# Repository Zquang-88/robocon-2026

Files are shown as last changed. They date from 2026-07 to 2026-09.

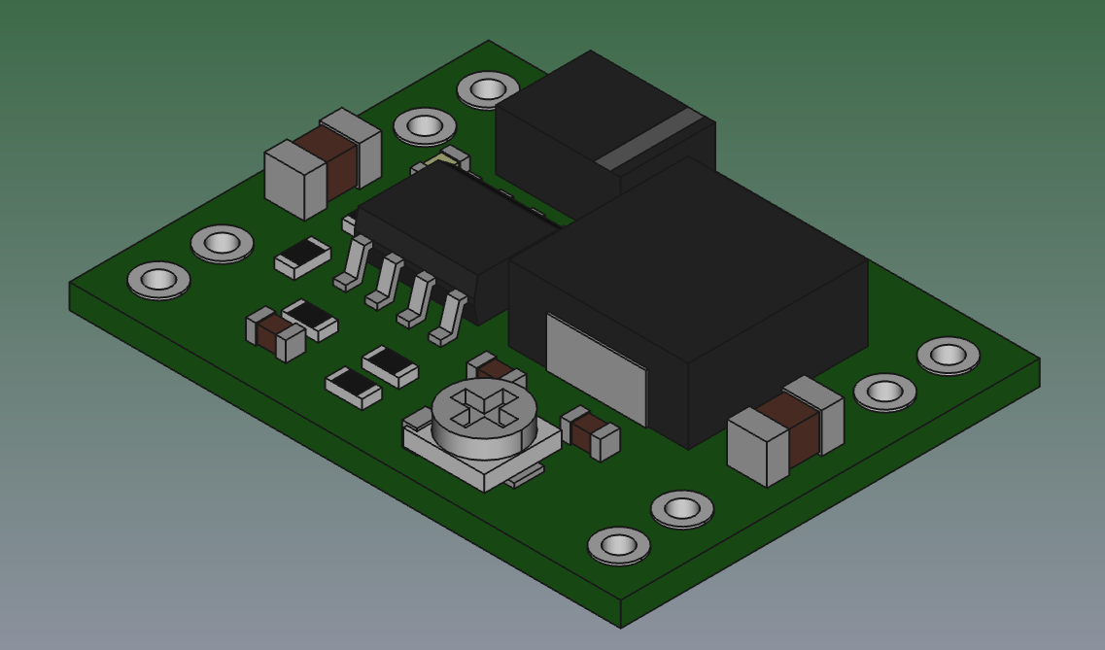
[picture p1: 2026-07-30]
hardwave/MP1584/d-sun-dc-dc-step-down-voltage-regulator-simple-version-1.snapshot.4/render/D-SUN_dcdc_step_down_SIMPLE2.png

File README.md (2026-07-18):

# ROBOCON 2026

Kho mã nguồn và thiết kế phần cứng dùng chung của đội Robocon 2026.

> Trạng thái: đang phát triển. Nhánh `main` chỉ dành cho phiên bản đã được kiểm tra.

## Phạm vi dự án

- Firmware điều khiển robot và các module ngoại vi
- Schematic, PCB và thư viện linh kiện
- Tài liệu kỹ thuật, sơ đồ kết nối và quy trình kiểm thử

## Cấu trúc hiện tại

```text
robocon-2026/
├── firmwave/                  # Firmware hiện có
│   ├── Auto_v1.cpp
│   └── line.h
├── hardwave/                  # Dự án Altium, PCB và schematic
│   ├── ROBOCON_AUTO/
│   ├── ROBOCON_T9_LOGIC/
│   └── ROBOCON_T9_V1/
├── docs/                      # Tài liệu làm việc nhóm
├── CONTRIBUTING.md            # Quy tắc đóng góp
└── README.md
```

Tên `firmwave` và `hardwave` được giữ nguyên để không làm hỏng đường dẫn dự án hiện tại. Có thể đổi thành `firmware` và `hardware` trong một Pull Request riêng sau khi cả đội thống nhất.

## Bắt đầu

1. Cài GitHub Desktop và đăng nhập GitHub.
2. Clone repository về máy.
3. Chọn **Fetch origin** và **Pull origin** trước khi bắt đầu.
4. Tạo branch mới từ `main`.
5. Chỉ sửa phần được phân công và kiểm tra trước khi commit.
6. Push branch và tạo Pull Request để thành viên khác duyệt.

Xem hướng dẫn chi tiết tại [CONTRIBUTING.md](CONTRIBUTING.md).

## Quy ước branch

| Loại công việc | Ví dụ |
|---|---|
| Tính năng firmware | `feature/motor-control` |
| Thiết kế phần cứng | `hardware/logic-board-v2` |
| Sửa lỗi | `fix/encoder-reading` |
| Tài liệu | `docs/wiring-diagram` |

## Quy ước commit

Viết ngắn gọn, mô tả đúng thay đổi:

```text
feat: thêm điều khiển động cơ
fix: sửa cách đọc encoder
hardware: cập nhật schematic bo logic
docs: bổ sung sơ đồ kết nối
```

## Nguyên tắc an toàn

- Không commit mật khẩu Wi-Fi, token, khóa SSH hoặc thông tin bí mật.
- Không đưa code chưa kiểm tra trực tiếp lên `main`.
- Không sửa đồng thời cùng một file PCB/SchDoc trên nhiều branch.
- Ghi rõ điện áp, cực tính và phiên bản bo mạch trước khi thử trên robot.
- Luôn có phương án dừng khẩn cấp khi kiểm thử cơ cấu chấp hành.

## Công cụ

- Firmware: C/C++ (bổ sung board, framework và phiên bản khi chốt cấu hình)
- PCB/Schematic: Altium Designer
- Quản lý mã nguồn: Git, GitHub Desktop và GitHub Pull Request

## Thành viên và phân công

Cập nhật bảng này khi đội chốt vai trò:

| Thành viên | Phụ trách | Module |
|---|---|---|
| Chưa cập nhật | Trưởng nhóm | Điều phối và tích hợp |
| Chưa cập nhật | Firmware | Điều khiển robot |
| Chưa cập nhật | Hardware | PCB và hệ thống điện |
| Chưa cập nhật | Mechanical | Cơ khí |

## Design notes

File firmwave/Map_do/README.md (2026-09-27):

# ESP32-S3 mechanism controller

Firmware điều khiển hai động cơ bước, hai cảm biến E18 và bốn van điện từ hai đầu qua PCF8574. ESP32 nhận lệnh từ Teensy 4.1 bằng UART2; USB Serial 115200 dùng chung bộ parser để thử và chẩn đoán.

## Kiến trúc

```text
Teensy Serial6 (TX24, RX25)
  <-> 57600 baud
ESP32-S3 UART2 (RX16, TX15)
  |- UartProtocol: buffer char cố định, lọc CR/LF/khoảng trắng/byte rác đầu dòng
  |- MechanismController: state machine động cơ, HOME, E18 và chuỗi van
  |- ValveController: PCF8574 active-low, interlock cặp và deadtime 50 ms
  |- AccelStepper.run(): phát xung động cơ không chặn
  `- PersistentConfig: cấu hình profile trong NVS có CRC
```

Chuỗi van dùng `millis()`, không dùng `delay(700)`. Trong thời gian chờ, vòng lặp vẫn đọc UART, chạy động cơ bước, cập nhật E18 và nhận `STOP`.

## Chân phần cứng

| Chức năng | ESP32-S3 | Nối với |
| --- | ---: | --- |
| UART2 RX | GPIO16 | Teensy TX6 chân 24 |
| UART2 TX | GPIO15 | Teensy RX6 chân 25 |
| I2C SDA | GPIO8 | PCF8574 SDA |
| I2C SCL | GPIO3 | PCF8574 SCL |
| PCF8574 | `0x20` | P0-P7, active LOW |
| Step/Dir A | GPIO1 / GPIO2 | Driver stepper A |
| Step/Dir B | GPIO45 / GPIO48 | Driver stepper B |
| HOME A/B | GPIO36 / GPIO37 | Công tắc active LOW |
| E18 A/B | GPIO17 / GPIO18 | Cảm biến active LOW |
| Nút van | GPIO11 | Nút thường hở nối GND, INPUT_PULLUP |
| Nút HOME B rồi A | GPIO12 | Nút thường hở nối GND, INPUT_PULLUP |

Firmware chỉ chấp nhận PCF8574 đúng địa chỉ `0x20`. Khi khởi động, `pcfState = 0xFF`, tức P0-P7 đều HIGH và mọi cuộn van đều mất điện. Nếu không tìm thấy PCF8574, cơ cấu không bắt đầu HOME/AUTO và UART báo `ERROR_PCF8574`.

## Hai nút điều khiển tại ESP32

Các nút vẫn hoạt động khi USB/telemetry không kết nối. Một đầu nút nối GPIO,
đầu còn lại nối GND: bình thường HIGH, nhấn LOW. Chống dội 30 ms; nút bị giữ
khi bật nguồn hoặc lúc STOP phải được nhả ra rồi nhấn lại mới có lệnh mới.

- **GPIO11 nhấn một lần:** đóng cả bốn van bằng cách bật P4/P5/P6/P7 và tắt
  P0/P1/P2/P3 (`enabledMask = 0xF0`, trạng thái PCF sau chuyển mạch là `0x0F`).
  Firmware vẫn mở cửa sổ 400 ms để nhận lần nhấn thứ hai. Nếu cơ cấu đang chạy,
  dừng cả chu trình và motor để bước kế tiếp không ghi đè trạng thái đóng.
  UART/USB báo `ACK,BUTTON11,P4_P7_ON_CLOSED`.
- **GPIO11 nhấn nhanh hai lần trong 400 ms:** mở cả bốn van bằng cách bật
  P0/P1/P2/P3 và tắt P4/P5/P6/P7
  trong cùng một mask (`pcfState = 0xF0`), sau deadtime 50 ms. Khi cơ cấu bận
  hoặc có fault, từ chối bật van. UART/USB báo
  `ACK,BUTTON11,P0_P3_ON_REQUESTED` khi nhận yêu cầu chuyển van.
- **GPIO12 nhấn một lần:** khi cơ cấu rảnh và không có fault, giữ A đứng yên,
  cho B chạy về HOME37. B chạm công tắc thì dừng xung ngay, xác nhận ổn định
  25 ms rồi đặt B=0; sau đó mới kéo A về HOME36 và đặt A=0. Cả hai trục dùng
  8000 step/s, gia tốc 5500 step/s²; timeout toàn chu trình 45 giây. Trục đã
  chạm HOME không chạy thêm. Báo `ACK,BUTTON12,HOME_B_THEN_A,8000,5500` khi
  bắt đầu và `HOME,STATUS,...` khi kết thúc. Nhấn khi bận bị từ chối, không xếp
  hàng để tự chạy sau. Lệnh UART `STOP` vẫn được xử lý trong khi HOME.

Chỉnh chân nút, thời gian nhấn đôi và tốc độ HOME ở `include/HardwareConfig.h`:
`VALVE_BUTTON_PIN`, `HOME_BUTTON_PIN`, `BUTTON_DOUBLE_CLICK_MS`,
`BUTTON_HOME_SPEED_STEPS_S`, `BUTTON_HOME_ACCEL_STEPS_S2`, `BUTTON_HOME_TIMEOUT_MS`.
HOME khi bật nguồn và lệnh UART HOME vẫn dùng cấu hình HOME thông thường;
chuỗi B trước A tốc độ 8000/5500 áp dụng riêng cho GPIO12.

## Ghép bốn van hai đầu

| Van | Đầu thứ nhất | Đầu đối diện |
| --- | --- | --- |
| 1 | P0 | P7 |
| 2 | P1 | P6 |
| 3 | P2 | P5 |
| 4 | P3 | P4 |

Mức LOW bật cuộn; mức HIGH tắt cuộn. Trước mỗi lần đổi đầu kích, `ValveController` đưa cả hai đầu của cặp lên HIGH, chờ 50 ms, rồi mới kéo đầu mới xuống LOW. Mọi byte ghi ra PCF đều được kiểm tra để không có hai đầu cùng một cặp đồng thời ở LOW.

Các hàm chính trong `ValveController`:

- `writePCF()`: ghi toàn bộ `pcfState` và kiểm tra giao tiếp.
- `setOutput(pin, enabled)` và `switchValveOutput(pin, enabled)`: chọn một đầu của đúng cặp; `false` chọn đầu đối diện.
- `allValveCoilsOff()`: hủy chuyển mạch đang chờ và ghi `0xFF` ngay.
- `update()`: hoàn tất pha make sau deadtime 50 ms mà không chặn vòng lặp.

## Chuỗi AUTO của van

Tại cả hai MAP, `POINT_A` hạ sâu hơn `POINT_B`: A/B hạ `610/545 mm` tại
`POINT_A` và `520/480 mm` tại `POINT_B`, tính từ `READY_HOME_A`. MAP đỏ và MAP
xanh có bộ hằng số riêng trong `include/HardwareConfig.h`: tiền tố
`RED_POINT_*` và `BLUE_POINT_*`, nên có thể hiệu chỉnh độc lập về sau.

| Lệnh | Bước 1 | Chờ | Bước 2 | Chờ | Phản hồi |
| --- | --- | ---: | --- | ---: | --- |
| `POINT_A` | P2 và P3 ON đồng thời trong một byte PCF | 50 ms deadtime an toàn | Nâng A/B về HOME_A ngay | - | `DONE_POINT_A` |
| `POINT_B` | P0 và P1 ON đồng thời trong một byte PCF | 50 ms deadtime an toàn | A/B cùng về READY_HOME_A; A nâng 1700 mm, B nâng 850 mm rồi giữ | - | `DONE_POINT_B` khi pha nâng tầng 1 bắt đầu |
| `BRIDGE_STABLE` | Không đổi van | - | A giữ ở 1700 mm, chỉ B nâng nốt 850 mm | - | `DONE_BRIDGE_B` |
| `THA_2A` | P1 OFF, P6 ON | 700 ms | P3 OFF, P4 ON | 700 ms | `DONE_THA_2A` |
| `THA_2B` MAP đỏ | P2 OFF, P5 ON | 350 ms | P0 OFF, P7 ON | 700 ms | `DONE_THA_2B` |
| `THA_2B` MAP xanh | P0 OFF, P7 ON | 350 ms | P2 OFF, P5 ON | 700 ms | `DONE_THA_2B` |

Tại `POINT_A` và `POINT_B`, hai cuộn yêu cầu được chuyển bằng một mask PCF8574 nên cùng kích sau deadtime an toàn 50 ms; không còn khoảng chờ 700 ms giữa hai van. Tại `POINT_B`, A và B trước tiên cùng nâng từ vị trí đang hạ về đúng `READY_HOME_A`. Sau khi cả hai tới READY, A/B cùng tốc độ nâng 850 mm; B dừng giữ, còn A nâng tiếp 850 mm để đạt tổng 1700 mm. ESP32 gửi `DONE_POINT_B` ngay khi pha 850 mm đầu bắt đầu để Teensy chạy qua line lên cầu song song. Khi BNO085 trên Teensy xác nhận robot đã xuống hết dốc và mặt phẳng ổn định 500 ms, Teensy gửi `BRIDGE_STABLE`; ESP32 giữ A ở 1700 mm, nâng riêng B nốt 850 mm và trả `DONE_BRIDGE_B`. Teensy vẫn được căn line sau cầu trong lúc B nâng, nhưng bắt buộc chờ `DONE_BRIDGE_B` trước khi gửi `THA_2A`. Các pha nâng dùng giới hạn 9000 step/s và gia tốc 6000 step/s². `MechanismController::updateValveSequence()` vẫn xử lý không chặn cho `THA_2A` và `THA_2B`. Lệnh chuyển động khác trong lúc cơ cấu bận nhận phản hồi `BUSY`. `STOP` luôn hủy chuỗi, dừng stepper, ghi `0xFF` và phản hồi `STOPPED`.
Sau chuỗi van `THA_2B`, ESP32 trả `DONE_THA_2B` ngay để Teensy bắt đầu chạy robot. ESP32 cho riêng động cơ B hạ trước 400 mm, sau đó A và B cùng chạy với tốc độ 8000 step/s và gia tốc 5000 step/s² cho tới khi HOME37 ổn định 25 ms. Lúc đó B được đặt zero và riêng A đổi chiều kéo về HOME36. Nếu HOME37 tác động sớm trong 400 mm đầu, firmware dừng B ngay và bỏ qua pha hạ đồng bộ để bảo vệ cơ cấu. Toàn bộ quá trình không chặn UART/E18/STOP và có timeout 45 giây.

Phía Teensy, sau `DONE_THA_2B`, robot giữ heading và thực hiện một vector chéo duy nhất: lùi 3000 mm (`-X`) đồng thời đi phải 2000 mm (`-Y`), giới hạn tốc độ tổng 1200 mm/s, rồi chuyển sang `FINISH`.

Log kiểm tra ví dụ:

```text
[POINT_A] P2 + P3 ON TOGETHER
DONE_POINT_A
```

## Lệnh chẩn đoán PCF8574

| Lệnh | Chức năng |
| --- | --- |
| `PCF,P0,ON` ... `PCF,P7,ON` | Chọn đầu được chỉ định, tự tắt đầu đối diện |
| `PCF,P0,OFF` ... `PCF,P7,OFF` | Tắt đầu chỉ định và chọn đầu đối diện |
| `PCF,ALL,OFF` | Tắt điện toàn bộ P0-P7 (`0xFF`) |
| `PCF,STATUS` | Đọc status hiện tại |
| `STOP` | Dừng ưu tiên cao, safe-off toàn bộ van |

Chân ngoài P0-P7 bị từ chối. Nếu ghi I2C thất bại, chuỗi bị hủy, cơ cấu vào fault và UART phát `ERROR_PCF8574`.

## Build và kiểm thử

```powershell
C:\Users\Acer\.platformio\penv\Scripts\platformio.exe run -e esp32-s3-devkitm-1
.\test\run_jog_host.ps1
```

Bộ test host kiểm tra địa chỉ/chân I2C, trạng thái khởi động `0xFF`, active-low, bốn cặp interlock, deadtime 50 ms, thứ tự cả bốn chuỗi, `BUSY`, `STOP` và lỗi ghi PCF8574.

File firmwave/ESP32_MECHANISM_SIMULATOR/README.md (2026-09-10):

# ESP32 mechanism simulator

Firmware này giả lập cơ cấu chưa hoàn thiện để Teensy 4.1 có thể tiếp tục chạy
state machine tự động. ESP32 nhận một lệnh cơ cấu hợp lệ, chờ không chặn 4 giây,
sau đó gửi đúng một dòng `DONE` về robot.

## Giao thức khớp với firmware chính

| Teensy gửi | ESP32 trả sau 4 giây |
|---|---|
| `POINT_A` | `DONE` |
| `POINT_B` | `DONE` |
| `THA_2B` | `DONE` |
| `THA_2A` | `DONE` |
| `DONE_THA_2A` | `DONE_THA2A` |
| `DONE_THA_2B` | `DONE_THA2B` |

- UART giữa hai board: `57600`, `8N1`.
- Mỗi bản tin kết thúc bằng CR/LF; `println()` ở hai phía đáp ứng yêu cầu này.
- Chuỗi `DONE` phải viết hoa vì Teensy so sánh chính xác, phân biệt hoa/thường.
- Lệnh không thuộc bảng trên sẽ bị bỏ qua và chỉ được báo trên USB Serial của
  ESP32. Lệnh lặp trong lúc đang chờ cũng bị bỏ qua để không khởi động lại bộ đếm.

## Đấu dây

| ESP32 DevKit V1 | Teensy 4.1 |
|---|---|
| GPIO16 / RX2 | pin 24 / TX6 |
| GPIO15 / TX2 | pin 25 / RX6 |
| GND | GND |

Hai board đều dùng logic 3.3 V. Phải nối chung GND và nối chéo TX-RX. Không nối
chân 5 V vào đường RX/TX.

## Nạp bằng PlatformIO

Mở thư mục này bằng PlatformIO rồi chạy:

```powershell
platformio run
platformio run --target upload
platformio device monitor
```

USB monitor chạy ở 115200 baud và hiển thị lệnh đã nhận, thời điểm bắt đầu mô
phỏng và lúc gửi `DONE`. Kênh USB debug độc lập với UART2 nối sang Teensy.

Firmware chính đã đặt `ESP32_REPLY_TIMEOUT_MS` thành 15 giây để đủ thời gian chờ
4 giây và có thêm biên an toàn cho scheduler/UART.

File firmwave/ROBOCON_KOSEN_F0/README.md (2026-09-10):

# ROBOCON_KOSEN_F0 — Teensy 4.1 Mecanum

Firmware thi đấu Mecanum được nâng cấp trực tiếp từ trình tự nhiệm vụ của
`V10_SAN_DO_V2.cpp`. Chương trình dùng PID bánh xe 100 Hz, BNO085, hai MCP3008,
optical flow MAVLink, VL53L1X, UART ESP32 và parser Serial không chặn.

## Trạng thái an toàn ban đầu

Firmware biên dịch được nhưng **không cho motor chạy ngay sau khi nạp**.
Trong `include/RobotConfig.h`, `HARDWARE_CONFIG_VERIFIED` đang là `false`, kích
thước robot, số count encoder và phía sân chưa được đặt. Đây là khóa có chủ ý để
robot không chạy sai chiều do thông số chưa đo.

Chỉ đặt `HARDWARE_CONFIG_VERIFIED = true` sau khi hoàn thành toàn bộ mục hiệu
chỉnh bên dưới. Khi STOP pin 31 đang LOW hoặc còn fault, lệnh chạy bị từ chối.

## File chính

- `include/RobotConfig.h`: mọi chân, dấu chiều, kích thước, calibration và PID.
- `src/main.cpp`: firmware thi đấu hoàn chỉnh.
- `src/Read_Optical_Flow.cpp`: firmware chẩn đoán optical flow riêng.
- `platformio.ini`: môi trường `robot` và `optical_flow`; mặc định là `robot`.

## Bảng chân kết nối

| Chức năng | Chân Teensy 4.1 |
|---|---:|
| FL RPWM / LPWM | 36 / 37 |
| FR RPWM / LPWM | 22 / 23 |
| RL RPWM / LPWM | 18 / 19 |
| RR RPWM / LPWM | 14 / 15 |
| Encoder FL A / B | 0 / 1 |
| Encoder FR A / B | 6 / 7 |
| Encoder RL A / B | 2 / 3 |
| Encoder RR A / B | 4 / 5 |
| MCP3008 center CS | 26 |
| MCP3008 stop CS | 8 |
| SPI MOSI / MISO / SCK | 11 / 12 / 13 |
| BNO085 + VL53L1X Wire1 SDA / SCL | 17 / 16 |
| Optical flow UART | Tạm tắt; Serial1 chân 0/1 trùng encoder FL |
| Telemetry Serial5 RX / TX | RX21 / TX20; CP210x phía PC là COM5, 57600 baud |
| ESP32 UART | Tạm tắt; chưa chốt UART và chân riêng không xung đột |
| START / STOP vật lý | Không dùng; chân 32 / 31 để trống |

Hai MCP3008 dùng chung SPI0 MOSI/MISO/SCK và khác CS. MCP center đọc CH0–CH7;
do hai cáp cụm stop được đấu chéo, MCP stop đọc CH3–CH5 cho bên trái và CH0–CH2
cho bên phải. Firmware đổi chúng về thứ tự logic trái trước, phải sau. Tất cả thiết
bị phải chung GND;
Teensy dùng mức logic 3.3 V. Optical flow và VL53L1X đang tắt. Lệnh điều khiển
và telemetry RBT/1 đi qua Serial5 tới COM5; USB native COM14 không phải kênh điều
khiển trong bản này. Chân 31/32 hiện không dùng.

## Thư viện PlatformIO/Arduino

`platformio.ini` đã khai báo:

- Paul Stoffregen `Encoder`
- Adafruit `Adafruit BNO08x`
- Pololu `VL53L1X`
- `SPI` và `Wire` có sẵn trong Teensy framework

## Thông số bắt buộc phải đo

Sửa tập trung trong `include/RobotConfig.h`:

1. `ROBOT_LENGTH_MM`: khoảng cách tâm bánh trước–sau.
2. `ROBOT_WIDTH_MM`: khoảng cách tâm bánh trái–phải.
3. `ENCODER_COUNTS_PER_WHEEL_REV`: số count AB thực tế trên một vòng bánh sau hộp số.
4. `MOTOR_SIGN_*` và `ENCODER_SIGN_*` cho bốn bánh.
5. Chọn sân trên giao diện trước khi START AUTO: sân đỏ bắt đầu đi trái,
   sân xanh bắt đầu đi phải. Firmware tự đảo hướng và chọn cụm 3 mắt tương ứng.
6. Xác nhận bố trí con lăn chữ X và `BNO_YAW_SIGN`.
7. UART/baud, đổi trục, dấu trục và scale của optical flow.
8. `CENTER_SENSOR_MIN/MAX`, `STOP_SENSOR_MIN/MAX`, cực tính line/nền và thứ tự sáu mắt dừng.
9. `TOF_TARGET_MM` và giới hạn hợp lệ VL53L1X.
10. Feedforward, dead-zone và PID riêng của từng bánh sau khi test cơ khí.

`MM_PER_COUNT` được tính từ đường kính 100 mm, count/vòng và
`DISTANCE_CALIBRATION`; không còn dùng hằng số cũ `0.73`.

## Build

```text
pio run -e robot
pio run -e optical_flow
```

Chọn environment `robot` để nạp firmware thi đấu. Chỉ nạp `optical_flow` khi
muốn chạy chương trình chẩn đoán MAVLink độc lập.

## Lệnh telemetry COM5, Serial5, 57600 baud

```text
START                 hoặc RUN / AUTO
STOP                  hoặc ESTOP
RESET
CAL_LINE
TEST_MOTOR
TEST_ENCODER
TEST_BNO
TEST_LINE_CENTER
TEST_LINE_STOP
TEST_FLOW
TEST_TOF
STATUS
DRIVE,vx_mm_s,vy_mm_s,wz_rad_s
MOVE,dx_mm,dy_mm,max_speed_mm_s
POSE_RESET
YAW,degrees
SET_PID,wheel(0-3),kp,ki,kd,kff,deadzone
PID,WHEEL,FL,0.4,0.3,0.002
PID,WHEEL,ALL,0.4,0.3,0.002
PID,HEADING,0,6.0,0.1,0.08
PID,LINE,0,0.16,0.02,0.003
PING
GET_CONFIG
TUNE,WHEEL,FL,120
TUNE,STOP
SAVE_CONFIG
PROFILE_LOAD
FACTORY_RESET
```

`DRIVE` phải được gửi lại trong tối đa 500 ms; mất lệnh sẽ dừng và disarm.
Manual `DRIVE` được phép hoạt động khi BNO085 timeout vì Vx/Vy/Wz được điều khiển
trực tiếp; chỉ riêng `FAULT_IMU_TIMEOUT` được bỏ qua trong chế độ này. Mọi fault
khác vẫn khóa motor. `MOVE`, heading hold và state machine vẫn bắt buộc BNO085.
Khi BNO085 hợp lệ, manual Vx/Vy với Wz bằng 0 dùng PID heading để giữ yaw; mức
bù quay manual được giới hạn bởi `MAX_MANUAL_HEADING_WZ_RAD_S`.
`MOVE` điều khiển vị trí tương đối theo X tiến/lùi và Y phải/trái, dùng odometry,
PID vị trí và BNO085 giữ yaw. Mất heartbeat giao diện quá 600 ms cũng dừng MOVE.
Các alias `RUN`, `ESTOP`, `PID,...` và dòng `TEL,...` tương thích giao diện
ASCII RBT/1 trong thư mục `pid-tuner`. Telemetry đầy đủ có tiền tố `DBG` ở 10 Hz.

Trong lúc AUTO đang ARM, firmware không phát khối telemetry định kỳ. Chọn
`AUTO_TELEM,ON_REQUEST` để chỉ đọc một lần bằng `AUTO_TELEM,SNAPSHOT`, hoặc
`AUTO_TELEM,SILENT` để không trả snapshot. Snapshot theo yêu cầu được chia thành
`AUTO_SNAPSHOT`, `AUTO_WHEELS`, `AUTO_SENSORS` và
`AUTO_TELEM,SNAPSHOT_END`, mỗi vòng lặp chỉ phát một khung ngắn.

Các sự kiện `STATE`, `FAULT`, `SAFETY,FAULT`, `SAFETY,ESTOP`,
`SAFETY,STOP_INPUT` và `SAFETY,AUTO_COMPLETE` luôn được gửi trong cả hai chế độ;
giao diện không thể tắt các bản tin an toàn này.

Giao diện Web Serial gửi heartbeat mỗi 100 ms. Chế độ `TUNE,WHEEL` chỉ cho
phép một bánh chạy; nếu mất heartbeat quá 600 ms, firmware đặt bốn target về 0,
xóa PID và disarm. PID, feedforward, deadzone và các giới hạn mặc định nằm trong
`include/RobotConfig.h`; firmware không đọc hoặc ghi EEPROM. Tune từ giao diện chỉ
thay đổi RAM cho tới khi reset. `SAVE_CONFIG` xác nhận RAM-only và `PROFILE_LOAD`
nạp lại các giá trị đã biên dịch từ `RobotConfig.h`. Hãy mở `pid-tuner`, chọn cổng
CP210x COM5 ở 57600 baud, chọn một
bánh và bắt đầu ở RPM thấp khi robot đang được kê khỏi mặt đất.

Telemetry dùng Serial5 RX21/TX20. ESP32 dùng UART6 riêng: Teensy TX24 → ESP32
RX16 và ESP32 TX15 → Teensy RX25, kèm GND chung.

## Trình tự test bắt buộc

1. Kê bốn bánh khỏi mặt đất, tháo cơ cấu tải và giữ STOP ở trạng thái có thể bấm ngay.
2. Để khóa motion, chạy `TEST_BNO`, `TEST_LINE_CENTER`, `TEST_LINE_STOP`,
   `TEST_FLOW`, `TEST_TOF`; xem `DBG` và sửa chân/cực tính/calibration.
3. Gửi `CAL_LINE`, đưa từng mắt qua cả nền và line, rồi gửi `CAL_LINE` lần nữa.
   Chép bốn mảng min/max được in ra vào `RobotConfig.h`.
4. Đo kích thước, encoder count/vòng, chọn phía sân; đặt
   `HARDWARE_CONFIG_VERIFIED = true`.
5. Kê bánh, chạy `TEST_MOTOR`. Bánh 0/1/2/3 lần lượt là FL/FR/RL/RR, mỗi bánh 2 s.
6. Khi target dương, mỗi bánh phải tạo lực đẩy robot về trước. Nếu sai, đổi
   `MOTOR_SIGN_*`, không đảo dây ngẫu nhiên trong lúc cấp nguồn.
7. Quan sát `ENC`. Khi bánh quay theo chiều dương, count phải tăng; nếu giảm, đổi
   `ENCODER_SIGN_*`. Đo đủ một vòng để xác nhận count/vòng.
8. Dùng `DRIVE,100,0,0`: bốn bánh phải làm robot tiến.
9. Dùng `DRIVE,0,100,0`: robot phải sang phải. Nếu cả hướng bị đối xứng, kiểm tra
   vị trí FL/FR/RL/RR và bố trí con lăn trước khi sửa công thức.
10. Dùng `DRIVE,0,0,0.2`: robot phải quay theo chiều kim đồng hồ. Đồng thời yaw
    BNO phải tăng; nếu không, đổi `BNO_YAW_SIGN`.
11. Đẩy robot bằng tay: chuyển động tiến phải cho flow X dương, sang phải cho
    flow Y dương. Sửa `FLOW_*_FROM_SENSOR_AXIS` và `FLOW_*_SIGN`, rồi đo scale.
12. Tune feedforward/dead-zone trước, sau đó P, I, D từng bánh; cuối cùng mới tune
    heading, line, stop-line và position.
13. Test riêng từng state ở tốc độ thấp, luôn kiểm timeout/fault, rồi mới chạy toàn tuyến.

## Tuyến AUTO commissioning đến cầu

Tuyến hiện tại dừng có chủ ý sau giai đoạn 8 mắt giữa bám line lên cầu. Sau khi
căn ToF và hoàn thành các điểm A/B bằng hai cụm 3 mắt, robot tìm line cầu, yêu
cầu line hợp lệ liên tục, sau đó bám line bằng PID và BNO085. Vạch ngang được
đếm có debounce; đủ `BRIDGE_STOP_CROSS_TARGET` thì firmware vào
`BRIDGE_ENTRY_STOP`, đặt bốn target/PWM về 0 và DISARM. Các nhiệm vụ sau cầu
không được chạy trong bản commissioning này.

## Giới hạn chính đã sửa từ V10

Code V10 dùng động học Omni, `mmPerCount = 0.73`, BNO055, hai line digital và
đọc ESP bằng `String/readStringUntil()`. Heading integral không nhân `dt`; có
`delay()`/`while(1)` chặn, đọc ToF thiếu kiểm soát timeout theo state, và nhiều
lệnh khởi tạo chuyển động nằm trực tiếp trong vòng state. Những điểm này đã được
thay bằng Mecanum X, PID có `dt`/anti-windup, parser không chặn, cảm biến có
validity/timeout, state `onEnter` và fault latch. Thứ tự nhiệm vụ V10 và các lệnh
ESP32 `POINT_A`, `POINT_B`, `THA_2B`, `THA_2A`/phản hồi `DONE` vẫn được giữ.

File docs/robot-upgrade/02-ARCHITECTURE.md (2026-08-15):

# Kiến trúc đích

## Firmware Teensy

```text
ROBOCON_KOSEN_F0/
  src/
    main.cpp                  # setup, scheduler, wiring dependency
    app/ModeManager.*         # IDLE/MANUAL/AUTO/TUNE/SAFE/FAULT
    control/PidController.*
    control/MotorControl.*
    control/HeadingControl.*
    control/LineControl.*
    control/DistanceControl.*
    sensors/EncoderBank.*
    sensors/ImuSensor.*
    sensors/LineSensors.*
    sensors/TofSensors.*
    sensors/OpticalFlow.*
    sensors/BatteryMonitor.*
    actuators/ServoBank.*
    actuators/BldcBank.*
    actuators/PneumaticBank.*
    communication/Protocol.*
    communication/TelemetryService.*
    communication/MechanismLink.*
    config/RobotConfig.*
    config/ConfigStore.*
    safety/FaultManager.*
    safety/SafetyManager.*
    logging/Logger.*
```

`main.cpp` chỉ điều phối scheduler và gọi module. Module không tự dùng `delay()`.

## Scheduler đề xuất

| Task | Tần số | Ưu tiên |
|---|---:|---:|
| E-stop + Safety | mỗi vòng loop | cao nhất |
| Motor speed PID | 200 Hz | cao |
| Heading PID | 100 Hz | cao |
| Line PID | 100 Hz | cao |
| Distance PID | 50 Hz | trung bình |
| Sensor update | theo sensor | trung bình |
| PC heartbeat | 10 Hz | trung bình |
| Telemetry | 25–50 Hz | thấp |
| Buffered logging | 20–100 Hz | thấp |

## GUI

```text
Web Serial worker
  -> RBT/2 stream parser
  -> Robot data store
  -> ring buffers (10–30 s)
  -> tab UI
  -> CSV/profile export
```

State kết nối:

```text
DISCONNECTED -> PORT_OPEN -> HANDSHAKE -> SYNC_CONFIG -> STREAMING
                                             |              |
                                             +----ERROR-----+
```

GUI không gửi PID mặc định khi reconnect. Robot là nguồn cấu hình chính.

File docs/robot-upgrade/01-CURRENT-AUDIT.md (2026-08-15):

# Kiểm kê hệ thống hiện tại

## Firmware đang hoạt động

Dự án hiện hành: `firmwave/ROBOCON_KOSEN_F0` cho Teensy 4.1.

Các module logic đang có trong `src/main.cpp`:

| Nhóm | Hiện trạng |
|---|---|
| Motor | 4 motor FL/FR/RL/RR, encoder riêng, mixer mecanum |
| PID motor | PID riêng từng bánh, 100 Hz; chưa có open-loop mode rõ ràng |
| Heading | BNO055 + PID heading |
| Line | 1 cụm 8 mắt MCP3008 + 1 PID dùng chung |
| ToF | 1 VL53L1X, mới đọc sensor; chưa có PID khoảng cách |
| Battery | ADC điện áp, chưa có dòng điện và fault threshold hoàn chỉnh |
| Safety | E-stop vật lý, khóa motor khi boot, timeout DRIVE 500 ms |
| Auto | State machine kiểm tra 3 bước, chưa phải kịch bản thi đấu chính thức |
| ESP32 | Serial4, gửi chuỗi `POINT_A`, chờ chuỗi chứa `DONE` |
| PC telemetry | Serial5, RBT/1 ASCII, không CRC/sequence/heartbeat/config sync |
| Config | Gain khởi tạo trong code, chưa lưu bền vững |
| Logging | Chưa có logger/ring buffer/SD logging |

## Dashboard hiện tại

`pid-tuner` là dashboard React/Web Serial. Hiện có:

- Kết nối cổng COM bằng Web Serial.
- PID riêng từng bánh, PID heading và một PID line.
- Hiển thị RPM, heading, line error, điện áp.
- Gửi `RUN`, `ESTOP`, `PID`, `YAW` theo RBT/1.

Thiếu: handshake, heartbeat 10 Hz, config sync, packet CRC/sequence, reconnect state machine,
fault model, module tabs đầy đủ, ring buffer graph và CSV logger.

## Rủi ro cần giữ nguyên trong lúc refactor

1. Không thay pin, chiều motor/encoder, CPR hoặc kinematics nếu chưa test trên giá kê.
2. Không xóa RBT/1 cho đến khi RBT/2 đã chạy ổn định trên PC và Teensy.
3. Không chuyển PID ra GUI; tất cả control loop vẫn nằm trên Teensy.
4. Không ghi flash/EEPROM mỗi lần kéo slider.
5. Mọi actuator mới mặc định disabled/disarmed/off.

## Phần cứng chưa đủ thông tin để hoàn thiện

- Địa chỉ/XSHUT của 4 VL53L1X.
- Model và protocol của 4 optical-flow sensor.
- Chân, feedback và giới hạn của 4 servo.
- BLDC dùng PWM, DShot hay protocol khác.
- Mapping 8 van và ma trận interlock.
- Sensor dòng điện và ngưỡng pin thấp.
- Command thật của ESP32 cơ cấu.

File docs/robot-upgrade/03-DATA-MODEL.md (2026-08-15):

# Data model RBT/2

## Trạng thái chung

- `RobotMode`: IDLE, MANUAL, AUTO, TUNE, SAFE, FAULT.
- `ModuleState`: enabled, valid, fault, lastUpdateMs.
- `FaultFlags`: bitmask 32-bit; fault latching do `FaultManager` quản lý.

## PID

Mọi PID dùng chung cấu trúc:

```cpp
struct PIDConfig {
  float kp, ki, kd;
  float integralLimit;
  float outputLimit;
  bool enabled;
};

struct PIDRuntime {
  float target, actual, error;
  float integral, derivative, output;
};
```

`PIDConfig` là dữ liệu lưu bền vững. `PIDRuntime` chỉ là telemetry.

## RobotConfig

Một record versioned gồm:

- 4 motor config.
- Heading PID.
- 3 line PID (left/right/rear).
- 4 distance PID (front/rear/left/right).
- 4 servo config.
- 2 BLDC config.
- 8 valve config + interlock mask.
- Safety thresholds và communication settings.
- `version`, `size`, `crc32`.

Phase 1 mới truyền schema/config hiện có. Field chưa có phần cứng phải mang trạng thái disabled.

## Telemetry

Telemetry snapshot chứa runtime hiện tại. Dữ liệu graph tần số cao có thể tách thành
packet `STREAM_SAMPLE` để không phải gửi toàn bộ snapshot lớn ở 50 Hz.

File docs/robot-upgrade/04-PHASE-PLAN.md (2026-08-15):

# Kế hoạch triển khai theo phase

## Phase 1 — Protocol + Dashboard foundation

- RBT/2 binary framing, CRC16, sequence, timestamp.
- HELLO/HELLO_ACK, heartbeat 10 Hz, connection timeout 500 ms.
- CONFIG_READ handshake; giữ RBT/1 tương thích trong giai đoạn migration.
- Data model và diagnostics counters.
- Test parser với packet chia nhỏ, dính liền, CRC sai và noise.

## Phase 2 — Motor PID Tune

- Tách motor/encoder/PID khỏi main.
- OPEN_LOOP_PWM và CLOSED_LOOP_SPEED_PID loại trừ nhau.
- Điều khiển từng bánh và mixer 4 bánh.
- Ring-buffer graph target/actual/error/PWM.

## Phase 3 — Heading PID

- Heading hold enable/disable/reset/set-current-target.
- Runtime target/actual/error/omega và graph.

## Phase 4 — Line PID

- 3 cụm left/right/rear, mỗi cụm 3 mắt và PID riêng.
- Enable/valid/fault độc lập.

## Phase 5 — ToF PID

- 4 VL53L1X, XSHUT/address management.
- PID không chạy khi invalid/timeout/range error.

## Phase 6 — Optical Flow

- 4 module, quality/flow/velocity/timestamp/valid.

## Phase 7 — Actuators + ESP32 mechanism

- Servo, BLDC protocol abstraction, pneumatic interlock.
- ESP32 command ID + ACK/DONE/ERROR/timeout.

## Phase 8 — Config storage

- EEPROM/Flash record A/B, version, size, CRC32, factory defaults.
- Save/Load/Factory reset; rate-limit writes.

## Phase 9 — Safety + Fault

- Safety priority override, fault latching/clearing, physical E-stop policy.

## Phase 10 — Logging + Diagnostics

- CSV browser logging, fault log, optional SD buffered logger.
- Loop rates, drops, CRC errors, timeouts, CPU load estimate.

## Gate sau mỗi phase

1. Build firmware và dashboard.
2. Unit test protocol/module.
3. Bench test bánh kê khỏi mặt đất.
4. Ghi lại pin/config/threshold đã xác nhận.
5. Chỉ merge sang phase tiếp theo khi gate đạt.

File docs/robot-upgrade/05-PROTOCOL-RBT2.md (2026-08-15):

# RBT/2 protocol

## Framing

Little-endian, không padding:

```cpp
struct PacketHeader {
  uint16_t magic;         // 0x4252 = "RB" trên dây
  uint8_t version;        // 2
  uint8_t type;
  uint16_t payloadLength; // tối đa 1024
  uint32_t sequence;
  uint32_t timestampMs;
  uint16_t crc16;
};
```

CRC16-CCITT-FALSE tính trên header với `crc16 = 0`, sau đó payload.

## Packet types Phase 1

| Type | Hướng | Mục đích |
|---|---|---|
| HELLO | PC -> Teensy | protocol range + client nonce |
| HELLO_ACK | Teensy -> PC | firmware/config version + capabilities |
| HEARTBEAT | hai chiều | 10 Hz, mode/fault/link health |
| CONFIG_READ | PC -> Teensy | yêu cầu config hiện tại |
| CONFIG_DATA | Teensy -> PC | chunk config versioned |
| CONFIG_WRITE | PC -> Teensy | thay đổi RAM, chưa ghi flash |
| CONFIG_SAVE | PC -> Teensy | yêu cầu lưu bền vững |
| TELEMETRY | Teensy -> PC | snapshot/module samples |
| COMMAND | PC -> Teensy | mode/setpoint/actuator command |
| ACK | hai chiều | ACK theo sequence/command ID |
| ERROR | hai chiều | mã lỗi có cấu trúc |

## Reconnect

```text
open port
HELLO
HELLO_ACK
CONFIG_READ
CONFIG_DATA chunk(s)
ACK config complete
start HEARTBEAT + TELEMETRY
```

Không có bước nào tự ghi giá trị mặc định GUI xuống robot.

## Tương thích

RBT/1 ASCII tiếp tục là protocol active của robot trong Phase 1A. RBT/2 được đưa vào
song song và chỉ trở thành mặc định sau bench test. Không trộn byte ASCII và binary
trên cùng link sau khi đã negotiate RBT/2.

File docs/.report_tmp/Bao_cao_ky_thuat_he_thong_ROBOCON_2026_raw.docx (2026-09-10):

# Báo cáo kỹ thuật hệ thống điều khiển robot ROBOCON 2026

Teensy 4.1 ESP32 S3 Giao diện Web Serial

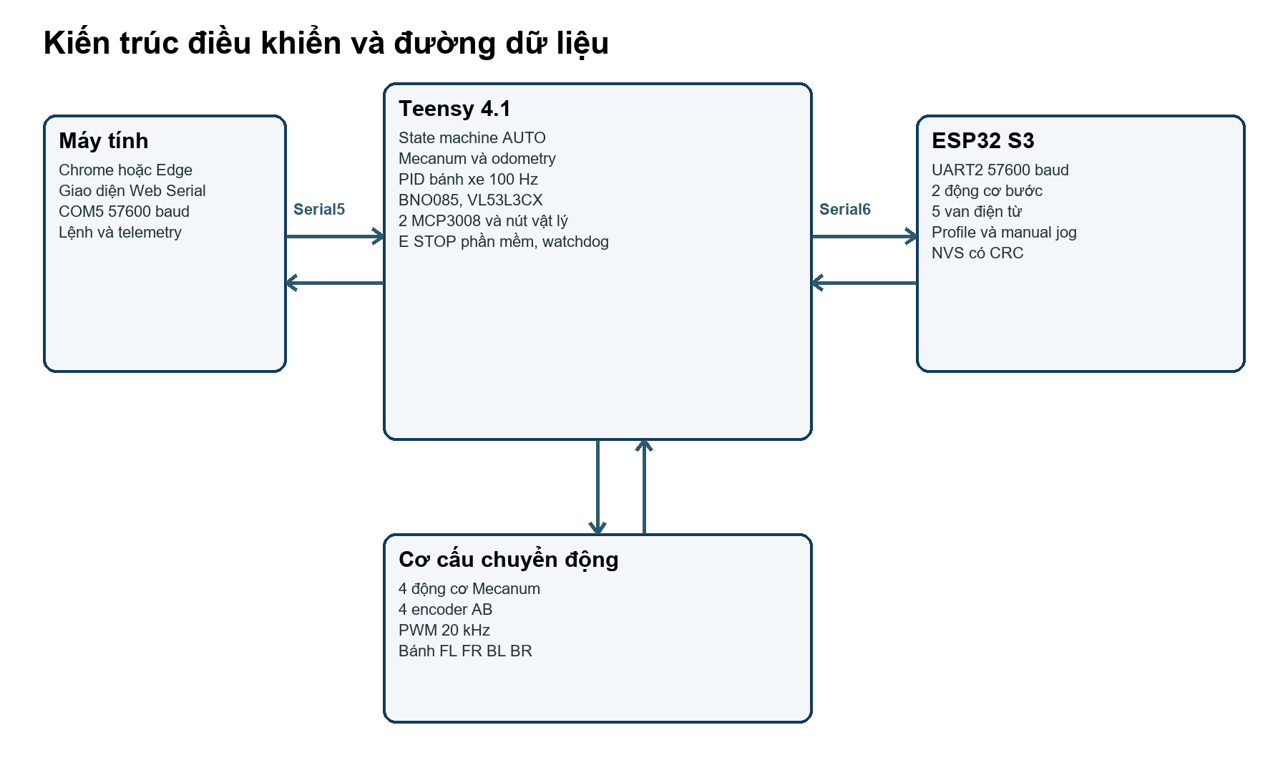
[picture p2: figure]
Sơ đồ máy tính kết nối Teensy qua Serial5, Teensy kết nối ESP32 qua Serial6 và điều khiển bốn bánh Mecanum.

Hình 1 Kiến trúc tổng thể của hệ thống

Thông tin | Giá trị
Mục đích | Giải thích toàn bộ source hiện tại để vận hành, hiệu chỉnh, bảo trì và kiểm soát thay đổi
Phạm vi | Firmware Teensy, firmware ESP32 cơ cấu thật, firmware ESP32 giả lập, giao diện telemetry và các công cụ chẩn đoán
Ngày chụp source | 08 tháng 09 năm 2026
Workspace | D:\ABOUT_ROBOCON_2026\robocon-2026
Commit repository chính | 0b20696
Commit giao diện | 8a5b587
Trạng thái | Tài liệu phản ánh file đang có trên đĩa, bao gồm các thay đổi chưa commit trong repository chính

Kết luận chính Hệ thống đã tách rõ điều khiển chuyển động trên Teensy và điều khiển cơ cấu trên ESP32. Cả hai firmware cùng giao diện đều build thành công tại thời điểm lập báo cáo. Tuy nhiên source chính đang có nhiều thay đổi chưa commit, một số state và hằng số kế thừa không còn nằm trong tuyến AUTO đang chạy, và tài liệu giao diện còn hai nhãn lưu EEPROM không đúng với hành vi RAM only của Teensy. Các điểm này cần được quản lý trước khi chốt bản thi đấu.

# Mục lục

[[TOC]]

# 1 Phạm vi và trạng thái xác minh

Báo cáo này mô tả source đang hoạt động trong workspace, không chỉ mô tả commit Git gần nhất. Cách đọc này cần thiết vì firmware cơ cấu ESP32 và nhiều mô đun mới của Teensy đang ở trạng thái chưa được commit trong repository chính. Các số liệu build bên dưới được kiểm tra trực tiếp từ source hiện tại.

Khối | Kết quả build | Thông tin chính
Teensy 4.1 | Thành công | Platform Teensy 5.1.0; code 156176 byte; data 44540 byte; RAM1 còn 300864 byte; RAM2 còn 511872 byte
ESP32 S3 cơ cấu | Thành công | Espressif32 6.11.0; RAM 20596 trên 327680 byte; flash 328325 trên 3342336 byte
Giao diện | Thành công | vinext build hoàn tất cho route gốc

## 1 1 Các giới hạn của kết quả xác minh

- Build thành công xác nhận cú pháp, liên kết thư viện và kích thước chương trình; build không thay thế thử nghiệm phần cứng dưới tải.
- Không có phép đo mới về chiều motor, cực tính cảm biến, khoảng cách thực tế hoặc đáp ứng PID trong quá trình lập tài liệu.
- Firmware có cơ chế bảo vệ bằng fault, watchdog và giới hạn phần mềm, nhưng E STOP vật lý độc lập chưa xuất hiện trong source Teensy hiện tại; biến dừng hiện tại là chốt E STOP do lệnh serial.
- Map_do là project ESP32 cơ cấu thật hiện tại. ESP32_MECHANISM_SIMULATOR là project thay thế để giả lập DONE sau 4 giây.

# 2 Kiến trúc hệ thống

Máy tính mở giao diện trong Chrome hoặc Edge và trao đổi với Teensy qua Web Serial. Teensy chịu trách nhiệm thời gian thực cho chuyển động, cảm biến, odometry và tuyến AUTO. ESP32 nhận lệnh cơ cấu từ Teensy qua UART riêng, phát xung cho hai động cơ bước, điều khiển năm van và trả trạng thái hoặc DONE.

Liên kết | Đầu thứ nhất | Đầu thứ hai | Tốc độ | Nội dung
Telemetry | Máy tính COM5 | Teensy Serial5 RX21 TX20 | 57600 8N1 | RBT 1 ASCII, lệnh điều khiển, cấu hình, telemetry
Cơ cấu | Teensy Serial6 TX24 RX25 | ESP32 UART2 RX16 TX15 | 57600 8N1 | Lệnh profile, jog, van, config, STATUS, DONE, ERR
Bảo trì Teensy | Máy tính COM14 | USB native Teensy | 115200 | Đường nhận lệnh dự phòng; phản hồi chính vẫn được in qua Serial5 do macro Serial
Bảo trì ESP32 | Máy tính USB | USB Serial ESP32 | 115200 | Dùng cùng parser với UART2 và nhận bản sao phản hồi

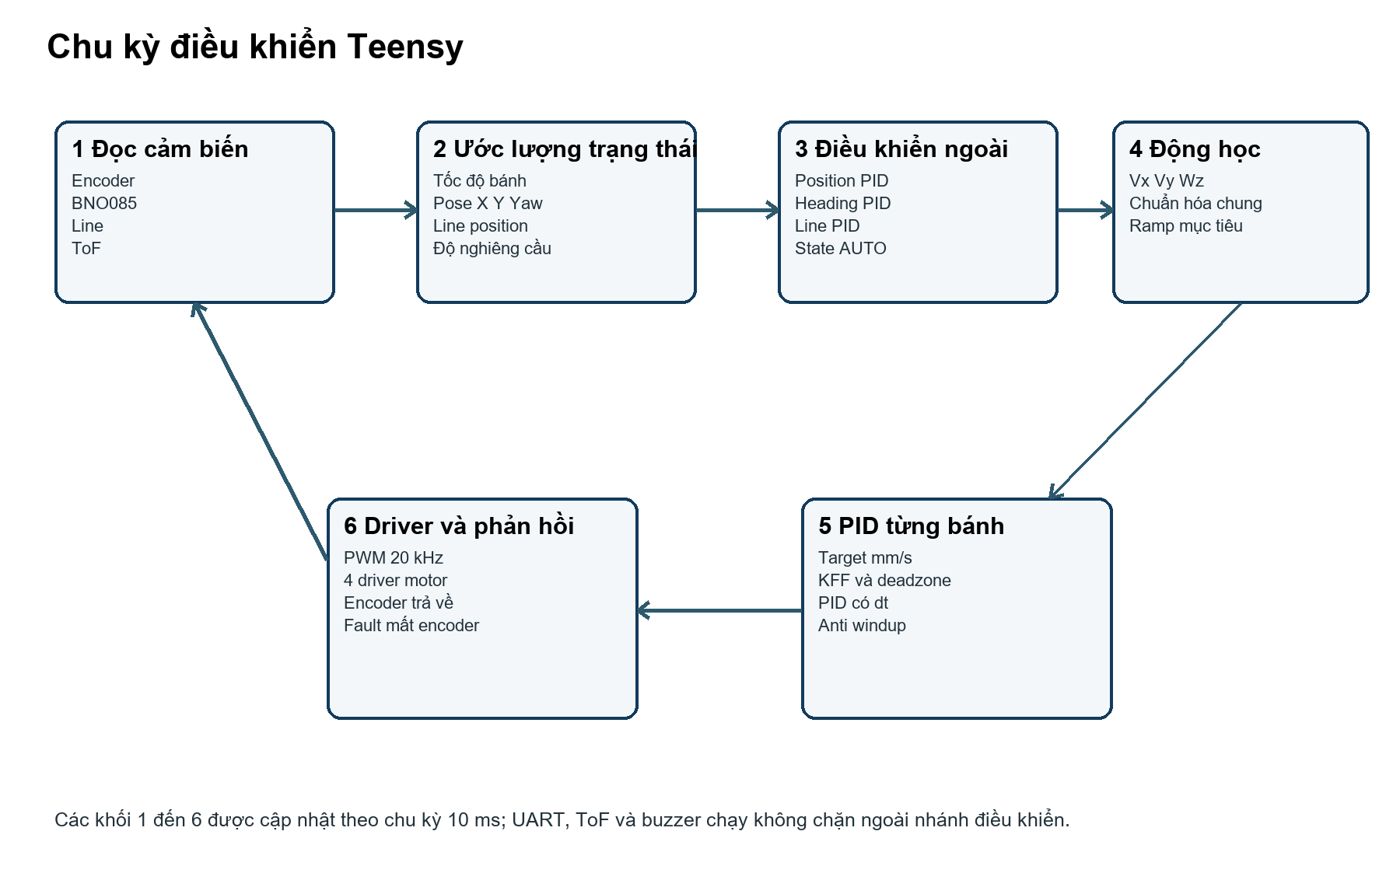
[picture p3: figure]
Chu kỳ đọc cảm biến, odometry, điều khiển ngoài, động học Mecanum, PID bánh và phản hồi encoder.

Hình 2 Các tầng điều khiển trong chu kỳ 10 ms

# 3 Bố cục source code

Đường dẫn logic | Vai trò
firmwave ROBOCON KOSEN F0 include RobotConfig h | Cấu hình tập trung Teensy gồm chân, dấu chiều, PID, line, ToF, AUTO, UART và an toàn
firmwave ROBOCON KOSEN F0 src main cpp | Firmware thi đấu Teensy gồm toàn bộ vòng điều khiển và state machine
firmwave ROBOCON KOSEN F0 src mechanism | Client UART6 và bộ giải mã trạng thái cơ cấu ESP32
firmwave ROBOCON KOSEN F0 src communication | Khung nhị phân RBT 2 có CRC; hiện không được nối vào main RBT 1 ASCII
firmwave ROBOCON KOSEN F0 src READ và TUNE | Các firmware độc lập để đọc line, ToF, optical flow, encoder và tune bốn bánh
firmwave Map_do | Firmware ESP32 S3 cơ cấu thật gồm controller, profile, van, UART và NVS
firmwave ESP32_MECHANISM_SIMULATOR | Firmware giả lập nhận lệnh và trả DONE sau 4 giây
pid-tuner app page tsx | Giao diện chính, Web Serial, parser, log chuyển động, xuất Excel và các trang chức năng
pid-tuner app MechanismJog tsx | Hai cần nhấn giữ cho động cơ bước A và B
pid-tuner app mechanism-jog-controller ts | Bộ phát latest state only 120 ms và hủy lệnh cũ để giảm lag
pid-tuner worker và vite config | Lớp deploy Cloudflare và tích hợp Sites

# 4 Phần cứng và sơ đồ chân

## 4 1 Chân Teensy 4 1

Khối | Chân | Ghi chú
Motor FL | RPWM 36 LPWM 37 | PWM 20 kHz
Motor FR | RPWM 22 LPWM 23 | MOTOR SIGN bằng âm
Motor BL RL | RPWM 18 LPWM 19 | Kênh sau đã được đổi nhận dạng vật lý
Motor BR RR | RPWM 14 LPWM 15 | Kênh sau đã được đổi nhận dạng vật lý
Encoder FL | A0 B1 | ENCODER SIGN âm
Encoder FR | A6 B7 | ENCODER SIGN dương
Encoder BL RL | A2 B3 | ENCODER SIGN dương
Encoder BR RR | A4 B5 | ENCODER SIGN âm
MCP3008 center | CS26 SPI0 11 12 13 | 8 mắt giữa CH0 đến CH7
MCP3008 stop | CS8 SPI0 11 12 13 | 6 mắt dừng cùng H1 H2 CH6 CH7
I2C Wire1 | SDA17 SCL16 | BNO085 0x4A và VL53L3CX 0x29 dùng chung bus 100 kHz
Telemetry | RX21 TX20 | Serial5 57600
ESP32 | TX24 RX25 | Serial6 57600
Nút START | 34 | Active low với INPUT PULLUP
Nút đổi map | 35 | Một nhấn RED hai nhấn BLUE
Buzzer | 40 | Active high qua AO3400A

## 4 2 Chân ESP32 S3

Khối | GPIO | Ghi chú
UART2 | RX16 TX15 | Nối chéo với Teensy TX24 RX25 và chung GND
Stepper A | STEP1 DIR2 | AccelStepper DRIVER
Stepper B | STEP45 DIR48 | GPIO45 là strap và GPIO48 dùng chung LED trên một số board
Van 1 đến 5 | 4 5 6 7 8 | Active high, safe mask 0; source yêu cầu xác nhận dây trước khi cấp khí
Home và cảm biến cơ cấu | Chưa gán | HOME chỉ về zero phần mềm; E18 và line input đang bằng âm một

# 5 Firmware Teensy 4 1

## 5 1 Khởi tạo

1. Mở USB Serial 115200, cấu hình Serial5 telemetry và Serial6 cơ cấu.
2. Khởi tạo buzzer và hai nút active low.
3. Khởi tạo SPI, hai chân CS và bốn cặp PWM ở 20 kHz.
4. Nạp PID, KFF và deadzone đã biên dịch từ RobotConfig h vào RAM.
5. Sao chép min max hiệu chuẩn line vào mảng runtime.
6. Khởi tạo Wire1 100 kHz, thử BNO085 tối đa ba lần và đặt yaw tương đối về zero.
7. Khởi tạo VL53L3CX ở long distance, timing budget 100 ms và bắt đầu đo liên tục.
8. Reset pose, phát thông tin boot và giữ robot không chạy cho đến khi có lệnh hợp lệ.

## 5 2 Vòng lặp hợp tác

Hàm loop không dùng delay trong đường chạy bình thường. Mỗi vòng lặp cập nhật parser USB và telemetry, UART ESP32, optical flow, BNO085, ToF, nút và buzzer. Cứ đủ 10000 micro giây, firmware đọc line, encoder, odometry, kiểm tra fault, cập nhật test hoặc AUTO rồi chạy PID bánh. Telemetry được xử lý sau khối điều khiển.

loop -> UART -> ESP32 -> Flow -> BNO085 -> ToF -> Nút và buzzer -> chu kỳ 10 ms -> Telemetry

## 5 3 Động học Mecanum và giới hạn

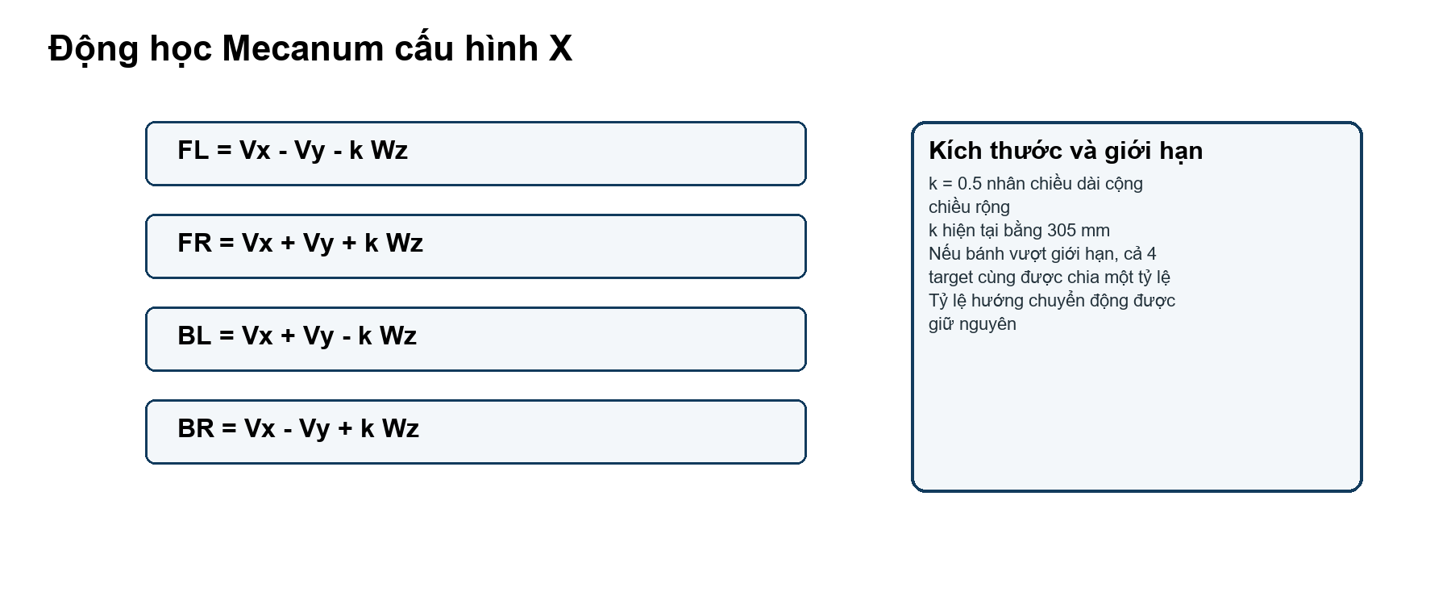
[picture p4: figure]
Bốn công thức vận tốc bánh cho cấu hình Mecanum X và cơ chế chuẩn hóa chung.

Hình 3 Công thức target bốn bánh

Trong công thức, Vx dương là tiến, Vy dương là sang phải theo quy ước nội bộ và Wz dương là quay theo chiều kim đồng hồ. k bằng nửa tổng khoảng cách tâm bánh trước sau và trái phải, hiện bằng 305 mm. Nếu một target vượt giới hạn bánh, setRobotVelocity chia đồng thời cả bốn target cho cùng một hệ số. Sau đó target được ramp đồng bộ với gia tốc 1400 mm trên giây bình phương và giảm tốc 2400 mm trên giây bình phương, nhờ đó tỷ lệ hướng Mecanum không bị phá bởi việc kẹp từng bánh độc lập.

## 5 4 Vòng PID tốc độ bốn bánh

Bánh | Kp | Ki | Kd | KFF | Deadzone PWM | Motor sign | Encoder sign
FL | 0.15 | 0.08 | 0 | 0.035 | 36 | +1 | -1
FR | 0.14 | 0.08 | 0 | 0.045 | 34 | -1 | +1
BL RL | 0.14 | 0.12 | 0 | 0.034 | 34 | +1 | +1
BR RR | 0.15 | 0.10 | 0 | 0.034 | 34 | -1 | -1

Encoder được đổi từ count sang milimet bằng chu vi bánh 100 mm chia 300 count mỗi vòng. Tốc độ đo được lọc IIR với alpha 0.35. PWM bằng KFF nhân target cộng deadzone theo dấu, sau đó cộng hiệu chỉnh PID. PID dùng dt, giới hạn tích phân 250 và anti windup theo bão hòa đầu ra. Nếu target lớn hơn 100 mm trên giây nhưng encoder không đổi trong 600 ms, firmware chốt FAULT ENCODER và dừng.

## 5 5 Các vòng điều khiển ngoài

Vòng | Hệ số hiện tại | Vai trò
Heading thường | Kp 0.101 Ki 0 Kd 0.004 | Giữ yaw; deadband 0.50 độ; Wz tối thiểu 0.18; max 1.2 rad trên giây
Heading fine | Kp 0.120 Kd 0.003 | Căn góc chính xác; deadband 0.25 độ; max 0.35
Heading ngang | Fine PID cộng slew | Deadband 0.45 độ; min 0.06; max 0.20; slew 0.80 rad trên giây bình phương
Heading tại trạm | Fine PID cộng slew | Deadband 0.45 độ; min 0.05; max 0.16; slew 0.55
Position X và Y | Mỗi trục 1.40 0.05 0.01 | MOVE tương đối và GOTO tuyệt đối; ngưỡng hoàn thành 18 mm
Line center | 0.16 0.02 0.003 | Sai số weighted của 8 mắt thành Vy; giảm Vx khi line lệch về mép
ToF | 0.80 0 0 | Căn khoảng cách target 160 mm; hiện không chặn A và B
Stop forward | 0.20 0.01 0.002 | Căn theo trung bình vị trí hai cụm trong hàm stop alignment kế thừa
Stop yaw | 0.0018 0.0001 0.00002 | Căn chênh lệch hai cụm line kế thừa
Cụm 3 mắt trái phải | Kp 0.08 | Kéo cặp mắt mục tiêu về vị trí 500 tại B

## 5 6 BNO085 và nhận diện dốc cầu

BNO085 phát Game Rotation Vector mỗi 10 ms. Firmware đổi quaternion thành yaw, roll và pitch. Yaw được đặt tương đối theo yawReferenceDeg; tốc độ quay được lọc. Roll và pitch dùng alpha 0.35. Trên cầu, robot chụp roll và pitch nền lúc bắt đầu bám line, chọn trục nghiêng lớn hơn khi độ nghiêng vượt 5 độ trong 150 ms, tăng tốc lên 1300 mm trên giây khi đang leo, nhận đỉnh khi trục nghiêng trở lại dưới 4 độ trong 120 ms sau tối thiểu 300 ms leo, rồi giảm còn 400 mm trên giây để xuống.

## 5 7 Cảm biến line

Cụm | Kênh vật lý | Thứ tự logic | Công dụng
8 mắt giữa | MCP CS26 CH0 đến CH7 | Trọng số âm 3500 đến dương 3500 | Bám line lên cầu và nhận vạch ngang khi ít nhất 6 mắt active
3 mắt trái | MCP CS8 CH3 CH4 CH5 | Ngoài âm 1000 giữa 0 trong dương 1000 | Căn điểm theo map
3 mắt phải | MCP CS8 CH0 CH1 CH2 | Ngoài âm 1000 giữa 0 trong dương 1000 | RED dùng tại A; cụm đối diện dùng tại B
H1 H2 | MCP CS8 CH6 CH7 | H1 ở đuôi H2 ở đầu | Giữ trôi dọc khi chạy ngang và tìm line dọc

Line đen cho ADC cao hơn nền trắng. Dữ liệu được chuẩn hóa 0 đến 1000 và cảm biến được xem là HIGH trên line khi normalized đạt ngưỡng. Ngưỡng chung là 550; riêng phát hiện nhanh pick line dùng 400. Center có min max đã hiệu chuẩn; sáu mắt stop cũng có min max đã hiệu chuẩn. H1 H2 vẫn dùng min 0 max 1023 mặc định và nên được hiệu chuẩn riêng để tăng độ tin cậy.

## 5 8 VL53L3CX

VL53L3CX dùng địa chỉ 0x29 trên Wire1 chung với BNO085. Firmware chọn vật thể hợp lệ gần nhất trong vùng 35 đến 800 mm, loại bước nhảy lớn hơn 250 mm và lọc median 5 mẫu. Timeout mẫu là 1500 ms. Tại A và B, ToF chỉ được phát bản tin thông tin và không quyết định chuyển state. Target vẫn là 160 mm, dung sai 30 mm. Luồng xuất phát hiện tại tắt nhận ToF trong đoạn tiến 170 mm vì cảm biến ở quá gần tường.

## 5 9 Odometry và MOVE

Odometry Mecanum tính dx và dy trong thân robot từ bốn delta encoder, dùng BNO085 làm yaw khi hợp lệ và xoay delta sang hệ tọa độ thế giới. Optical flow đang tắt, do đó trọng số odometry hiện là encoder 1.0 và flow 0.0. MOVE nhận dx dy tương đối trong hệ tọa độ tại thời điểm bắt đầu. GOTO nhận X Y yaw tuyệt đối trong hệ pose hiện tại. Cả hai đều yêu cầu BNO085 và heartbeat; mất heartbeat sau 600 ms sẽ dừng.

## 5 10 Nút vật lý và buzzer

Tác động | Xử lý
Nhấn START chân 34 | Kêu 1 tiếng, kiểm tra idle, E STOP, fault, BNO và cấu hình; tự chọn AUTO rồi vào CAN START dù không có telemetry
Nhấn map chân 35 một lần | Sau cửa sổ 450 ms chọn sân RED và kêu 2 tiếng
Nhấn map hai lần | Chọn sân BLUE và kêu 3 tiếng
Đến A hoặc B và bắt đầu chờ cơ cấu | Kêu 2 tiếng
Fault trong nhóm state căn A hoặc B | Buzzer chớp tắt 120 ms trong 2 giây

Hai nút dùng INPUT PULLUP nên thả là HIGH và nhấn nối GND là LOW. Debounce bằng thời gian, buzzer dùng hàng đợi và không chặn vòng điều khiển.

## 5 11 Fault và watchdog

Bit | Tên | Nguyên nhân điển hình | Tác động
0 | IMU TIMEOUT | BNO không có mẫu quá 250 ms | AUTO dừng; manual DRIVE có thể bỏ qua riêng bit này
1 | FLOW TIMEOUT | Optical flow mất dữ liệu | Hiện flow tắt nên không dùng trong tuyến chính
2 | LINE LOST | Mất center line quá 650 ms hoặc H1 H2 mất quá thời gian | Dừng và FAULT STOP
3 | TOF TIMEOUT | ToF bắt buộc ở hàm căn ToF nhưng mất quá 3 s | Dừng
4 | ENCODER | Có target trên 100 nhưng encoder đứng 600 ms | Dừng bốn bánh
5 | ESP TIMEOUT | Cơ cấu REAL không trả lời trong state chờ | Dừng AUTO
6 | STATE TIMEOUT | State vượt thời gian cho phép | Dừng AUTO
7 | CONFIG | Cấu hình không đủ hoặc tune bị khóa | Không cho motor chạy

# 6 Luồng AUTO hiện tại

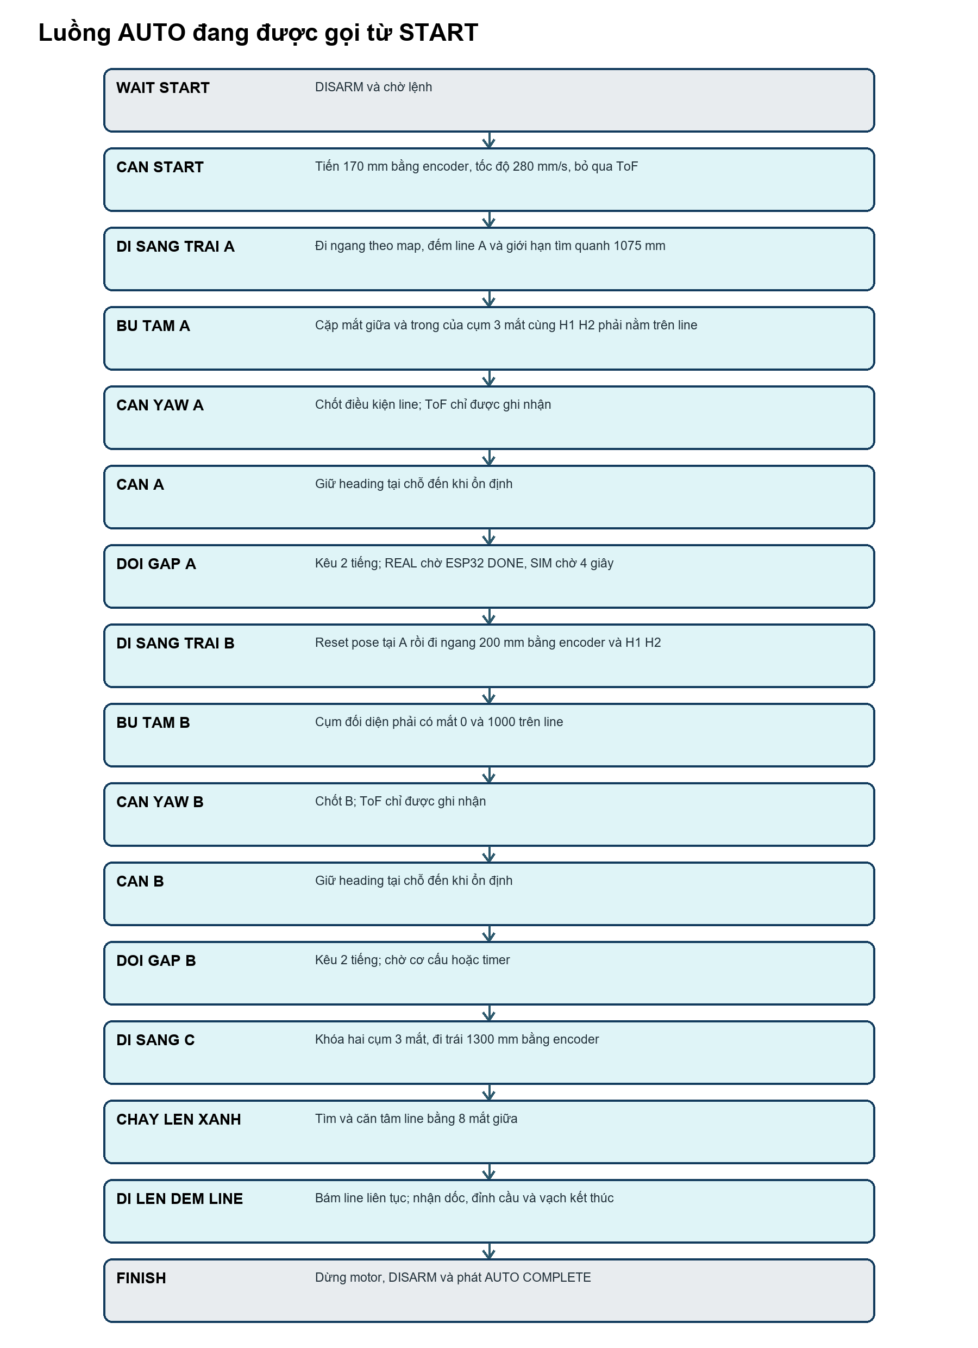
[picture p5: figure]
Chuỗi state từ WAIT START qua A, B, tìm line cầu, bám line và FINISH.

Hình 4 Tuyến AUTO thực sự được gọi từ START

Sân RED đặt dấu chạy ngang là dương và dùng cụm 3 mắt phải tại A. Sân BLUE đảo dấu chạy ngang và dùng cụm trái tại A. B dùng cụm đối diện. Heading cạnh tranh được chụp đúng lúc START và giữ xuyên suốt A và B.

State | Hành động | Điều kiện hoàn tất | State sau
WAIT START | Robot DISARM | START UART hoặc nút 34 | CAN START
CAN START | Tiến 170 mm encoder ở 280 | MOVE hoàn thành | DI SANG TRAI A
DI SANG TRAI A | Tìm pick line A quanh 1075 cộng trừ 200 mm | Đếm đủ 2 line, encoder trong cửa sổ, mắt giữa và trong đã đi qua | BU TAM A
BU TAM A | Kéo chậm về line | Mắt giữa và trong của cụm A cùng H1 H2 ổn định 180 ms | CAN YAW A
CAN YAW A | Xác nhận line và ghi ToF | Line còn đúng | CAN A
CAN A | Căn heading tại chỗ | X Y đã chốt và heading ổn định | DOI GAP A
DOI GAP A | Gửi POINT A hoặc SIM POINT A | DONE hoặc đủ 4 s | DI SANG TRAI B
DI SANG TRAI B | Reset pose rồi chạy ngang 200 mm | Relative move hoàn thành | BU TAM B
BU TAM B | Căn cụm đối diện | Mắt 0 và dương 1000 cùng nằm trên line 180 ms | CAN YAW B
CAN YAW B | Chốt B và ghi ToF | Ngay sau ghi | CAN B
CAN B | Căn heading tại chỗ | Heading ổn định | DOI GAP B
DOI GAP B | Gửi POINT B hoặc SIM POINT B | DONE hoặc đủ 4 s | DI SANG C
DI SANG C | Khóa cụm 3 mắt và đi trái 1300 mm ở 800 | MOVE hoàn thành | CHAY LEN XANH
CHAY LEN XANH | Quét trái phải trong bán kính 180 mm và căn center line | Line hợp lệ và gần tâm 180 ms | DI LEN DEM LINE
DI LEN DEM LINE | Bám line, tăng giảm ga theo dốc | Sau đỉnh cầu gặp vạch ngang ít nhất 80 ms | FINISH
FINISH | PWM về zero, DISARM | Lệnh RESET hoặc START mới | WAIT START qua lệnh

## 6 1 State kế thừa không nằm trong tuyến START hiện tại

Các state sau vẫn còn trong enum và switch nhưng không được tuyến START hiện tại chuyển tới. Chúng là phần kế thừa hoặc đường thử. Không nên chỉnh tốc độ trong các state này với kỳ vọng tuyến thi đấu sẽ thay đổi:

- CAN START FAST
- CAN START FINE
- BU TAM C
- CAN YAW C
- CAN GIUA LINE C
- HOME CENTER
- HOME DROP
- HOME TO B
- TIEN 34CM B
- DOI THA 2B
- CHO SAU B
- LUI 33CM A
- DOI THA 2A
- CHO SAU THA A
- LUI 3M
- SANG TRAI 1M5

## 6 2 Hằng số được định nghĩa nhưng không ảnh hưởng tuyến chính

Hằng số | Giá trị | Nhận xét
START LATERAL DISTANCE MM | 1000 | Không có tham chiếu trong main hiện tại
START LATERAL SPEED MM S | 400 | Không có tham chiếu trong main hiện tại
TOF START ESCAPE DISTANCE MM | 250 | Không có tham chiếu trong main hiện tại
TOF START ESCAPE SPEED MM S | 300 | Không có tham chiếu trong main hiện tại
PICK B LINE TARGET | 1 | Tuyến B hiện dùng encoder 200 mm rồi căn cặp mắt, không đếm line
BRIDGE LINE TARGET | 3 | Không được dùng; tuyến hiện dừng theo center cross sau đỉnh
BRIDGE SPEED FAST SLOW | 1150 và 1000 | Chỉ còn tham chiếu trong file recovery, không được main dùng
BRIDGE ACCEL DECEL | 1800 và 700 | Chỉ còn tham chiếu trong file recovery

# 7 Giao tiếp giữa Teensy và ESP32

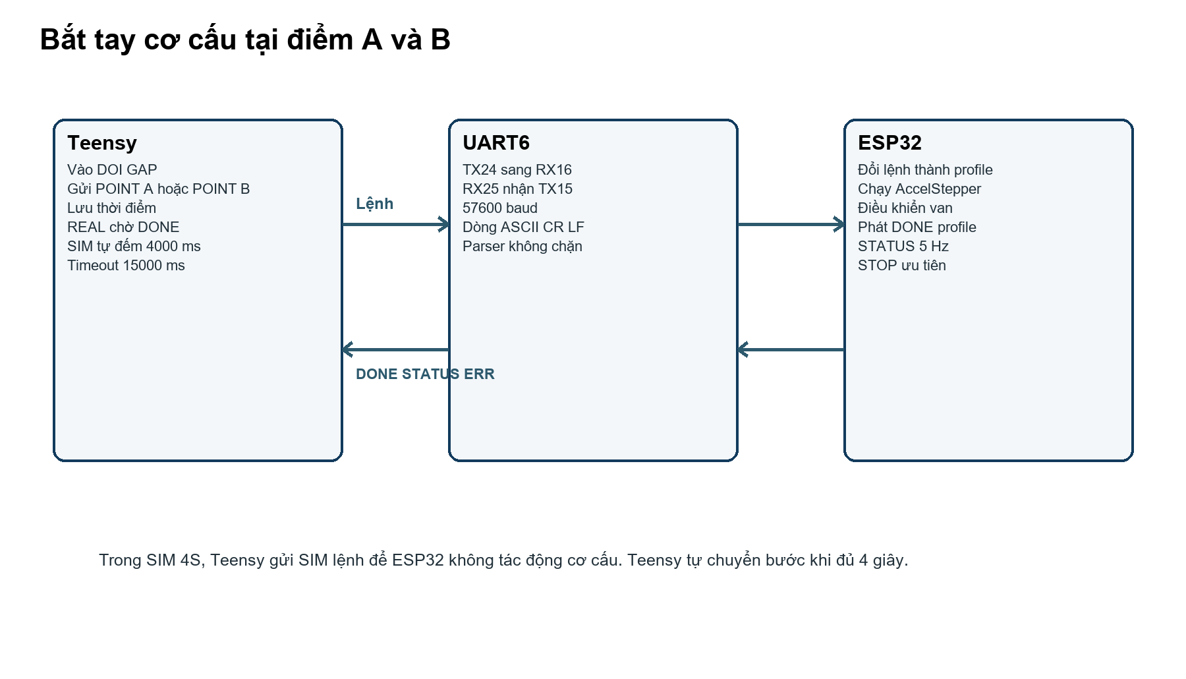
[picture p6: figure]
Teensy gửi lệnh qua UART6, ESP32 chạy profile và trả DONE hoặc Teensy chờ timer ở chế độ SIM.

Hình 5 Cơ chế chờ cơ cấu tại A và B

Chế độ REAL là mặc định sau mỗi lần reset Teensy. Ở chế độ này, robot chỉ rời state chờ khi nhận chuỗi chứa DONE. Nếu sau 5.5 giây chưa DONE, Teensy gửi lại POINT A hoặc POINT B với khoảng cách giữa hai lần gửi ít nhất 5 giây. Timeout state là 15 giây. Chế độ SIM 4S gửi khung SIM để ESP32 xác nhận nhưng không chạy cơ cấu; Teensy tự coi hoàn thành khi đủ 4000 ms.

Teensy gửi | ESP32 cơ cấu thật | Phản hồi quyết định
POINT A | Chạy profile PICK A | DONE PICK A
POINT B | Chạy profile PICK B | DONE PICK B
THA 2A hoặc THA 2B | Chạy profile RETRACT | DONE RETRACT
SIM lệnh | Chỉ ACK NO MOTION | Teensy tự hết 4 giây
STOP | Dừng stepper và đưa van về safe mask | ACK STOPPED SAFE

# 8 Firmware ESP32 S3 cơ cấu

## 8 1 Cấu trúc chạy

main cpp chỉ khởi tạo USB Serial, UART2, đọc cấu hình NVS hoặc nạp mặc định, khởi tạo MechanismController và gọi protocol update liên tục. UartProtocol đọc đồng thời UART2 và USB bằng hai buffer cố định 256 byte. Mỗi lần update, controller được gọi trước và sau khi đọc lệnh để AccelStepper run có cơ hội phát xung đều.

## 8 2 Cấu hình profile

Profile | A mm | B mm | Dir A | Dir B | Speed step s | Accel step s2 | Chờ ms | Mode
ROBOT START | 10 | 0 | -1 | +1 | 5000 5000 | 3500 3500 | 300 | Tương đối
PICK A | 500 | 500 | -1 | -1 | 5000 5000 | 3500 3500 | 3000 | Tương đối
PICK B | 615 | 500 | -1 | +1 | 5000 5000 | 3500 3500 | 3000 | Tương đối
RETRACT | 2200 | 2200 | +1 | -1 | 5000 5000 | 3500 3500 | 3000 | Tương đối
HOME | 0 | 0 | +1 | +1 | 5000 5000 | 3500 3500 | 0 | Tuyệt đối

Mỗi profile mặc định có ba bước: phát lệnh move, chờ hai stepper về target, rồi chờ post wait. Khung dữ liệu cho phép tối đa tám bước và enum đã hỗ trợ bật van, chờ thời gian, chờ stepper, chờ cảm biến và kết thúc. Tuy nhiên profile mặc định hiện không có bước ValveSet hoặc WaitSensor.

## 8 3 Tính vị trí và đồng bộ hai trục

Số step trên milimet bằng step trên vòng nhân hệ số hiệu chỉnh rồi chia bước vít. Mặc định A dùng 200 step trên vòng và vít 12 mm trên vòng; B dùng 200 và 10. Khi hai trục có quãng đường khác nhau, firmware chỉ giảm tốc trục ngắn hơn để thời gian chạy gần bằng trục dài hơn, không tăng quá giới hạn đã cấu hình. Chuyển profile vẫn giữ tọa độ milimet bằng cách đổi currentPosition theo scale mới.

## 8 4 Manual jog

JOG nhận tốc độ có dấu riêng cho A và B trong vùng 10 đến 30000 step trên giây. Giao diện gửi lại mỗi 120 ms. ESP32 yêu cầu có lệnh mới trong 500 ms; quá thời gian sẽ dừng và chốt JogLinkTimeout. Đổi chiều làm tốc độ dư được xóa trước khi ramp lại. Lệnh JOG STOP dừng hai trục nhưng không phát DONE và không thay đổi van.

## 8 5 Van và interlock

Năm van active high khởi động ở safe mask 0. writeOne ghi mức safe trước khi đổi chân sang OUTPUT để giảm xung kích lúc boot. Interlock hiện đều bằng 0, nghĩa là source chưa cấm cặp van nào bật cùng lúc. Nếu mạch dùng hai coil đối nghịch, cần điền VALVE INTERLOCK MASK trước khi chạy khí thật.

## 8 6 NVS và CRC

MechanismConfig có magic MECH, version, size, giới hạn vị trí, năm profile và CRC32. SAVE kiểm tra phạm vi, tính CRC, ghi namespace mechanism key config, đọc lại toàn bộ, so sánh byte và kiểm CRC lần nữa. Nếu load thất bại, ESP32 nạp mặc định vào RAM nhưng không tự ghi NVS. RESTORE DEFAULT cũng chỉ nạp RAM cho đến khi có SAVE.

## 8 7 Fault cơ cấu

Mã enum | Tên | Ý nghĩa
0 | None | Không lỗi
1 | Busy | Dùng cho dừng bất thường có reason khác STOP hoặc BOOT SAFE
2 | InvalidProfile | Profile không hợp lệ
3 | PositionLimit | Target vượt giới hạn phần mềm
4 | MotionTimeout | Profile hoặc direct move quá deadline
5 | SensorUnavailable | Profile yêu cầu sensor chưa gán chân
6 | SensorTimeout | Sensor không đạt trạng thái đúng hạn
7 | ValveInterlock | Hai van xung đột
8 | NotZeroed | HOME khi chưa SET ZERO và không có công tắc home
9 | JogLinkTimeout | Mất refresh JOG trên 500 ms

# 9 Firmware ESP32 giả lập

Project ESP32 MECHANISM SIMULATOR dùng cùng UART2 RX16 TX15 ở 57600. Nó nhận POINT A, POINT B, THA 2A, THA 2B hoặc SIM lệnh. Với lệnh hợp lệ, timer không chặn bắt đầu, LED bật và sau 4 giây gửi đúng một dòng DONE. Lệnh lặp khi bận bị bỏ qua nên không làm timer chạy lại. STOP hoặc ESTOP hủy pending ngay. Firmware này không điều khiển stepper hoặc van.

# 10 Giao diện Web Serial

## 10 1 Công nghệ và kết nối

Giao diện dùng React 19, Next 16, TypeScript, vinext và Vite. Bản deploy chạy qua Cloudflare Worker và Sites. Web Serial mở cổng ở baud do người dùng chọn, mặc định 57600 và buffer 8192 byte. Khi kết nối, giao diện gửi PING, GET CONFIG, MECH GET STATUS và MECH GET CONFIG. Nếu chỉ nhận mà không có chiều gửi, giao diện cảnh báo kiểm tra TXD bộ chuyển sang RX5 chân 21.

## 10 2 Các trang chức năng

Trang | Chức năng chính
Tổng quan | Hiển thị bốn bánh, heading, line và ToF
Điều khiển Mecanum | DRIVE nhấn giữ, heading manual, MOVE tương đối, pose, log và tải Excel
AUTO Setup sân | Chọn map, REAL hoặc SIM 4S, telemetry mode, GOTO, snapshot, START, DISARM, E STOP
CƠ CẤU ESP32 | Profile, trạng thái, hai cần jog, năm van, SET ZERO, config RAM và SAVE NVS
PID 4 bánh | Chọn một bánh, PID, target RPM, chạy thuận nghịch và heartbeat an toàn
Heading PID | PID heading, giới hạn Wz, deadband, Wz tối thiểu và giới hạn tốc độ bánh
Line PID | Đọc raw normalized, hiệu chuẩn 8 mắt, 6 mắt và xem H1 H2
Cấu hình | GET CONFIG, SAVE CONFIG, PROFILE LOAD và FACTORY RESET
Chẩn đoán | Trạng thái liên kết, RX TX, state, fault và ARM

## 10 3 Cơ chế chống lag

Parser đọc mọi dòng để ghi log, nhưng UI chỉ render theo batch 40 ms. Các record tần suất cao như WHEEL được ghi đè bằng bản mới nhất theo key; record sự kiện như STATE, ACK và ERR vẫn giữ thứ tự. Các dòng không cần cho giao diện như MOTION, DBG, TILT, STOP6, HOLD2, PICK SCAN và BRIDGE SCAN bị bỏ khỏi hàng render. Hàng lệnh serial được tuần tự hóa. DRIVE và JOG dùng latest state only để không tích tụ lệnh cũ phía sau thao tác ghi chậm.

## 10 4 Ghi log và xuất Excel

Giao diện tự ghi mẫu khi MOTION báo active. Mỗi mẫu giữ thời gian PC và robot, mode, map, state, fault, ARM, Vx Vy Wz, sai số vị trí, pose, heading, ToF và target actual error PWM encoder của từng bánh. File tải về là workbook XML Excel có sheet Tổng quan và Dữ liệu 4 bánh. Tốc độ thực tế robot được suy ra từ RPM bốn bánh và đường kính 100 mm; đây là tốc độ suy ra từ encoder, không phải tốc độ đo độc lập ngoài robot.

# 11 Danh mục lệnh điều khiển

Lệnh Teensy | Chức năng
PING | Bắt tay và nhận HELLO
GET CONFIG | Đọc PID, giới hạn, mode, map và cấu hình AUTO
HEARTBEAT | Giữ tune, MOVE, GOTO hoặc test giám sát
MODE MANUAL hoặc AUTO | Đổi mode khi DISARM
FIELD RED hoặc BLUE | Chọn map khi DISARM
START hoặc RUN | Chạy tuyến AUTO hiện tại
START TEST | AUTO có heartbeat giám sát
START BRIDGE TEST | Bắt đầu từ đoạn sau B để thử cầu
ARM | Chỉ test khóa heading AUTO, không chạy tuyến
STOP hoặc DISARM | Dừng và về WAIT START
ESTOP | Chốt E STOP phần mềm và gửi STOP sang ESP32
RESET | Xóa E STOP phần mềm và fault
DRIVE vx vy wz | Điều khiển vận tốc manual; phải refresh trong 500 ms
MOVE dx dy maxSpeed | Vị trí tương đối
GOTO x y yaw maxSpeed | Vị trí tuyệt đối ở mode AUTO
POSE RESET | Đặt pose về zero khi DISARM
MANUAL HEADING ON OFF | Bật tắt giữ heading manual
MANUAL YAW degrees | Đặt yaw manual
PID WHEEL name kp ki kd | Đổi PID bánh trong RAM
SET PID index kp ki kd kff deadzone | Đổi đầy đủ điều khiển một bánh trong RAM
PID HEADING | Đổi PID heading trong RAM
PID LINE | Đổi PID line trong RAM
LIMITS HEADING | Đổi max Wz, deadband và min Wz khi DISARM
LIMITS MOTOR | Đổi giới hạn bánh 100 đến 2000 mm trên giây
TUNE WHEEL | Quay một bánh theo target RPM
TUNE STOP | Dừng tune
TEST LINE CENTER STOP | Bật dữ liệu raw line tương ứng
CAL CENTER hoặc CAL STOP | Bắt đầu và kết thúc hiệu chuẩn
AUTO MECH REAL hoặc SIM 4S | Chọn cơ cấu thật hoặc giả lập
AUTO TELEM ON REQUEST hoặc SILENT | Chọn chính sách telemetry AUTO
AUTO TELEM SNAPSHOT | Lấy một snapshot phân mảnh
MECH command | Chuyển command nguyên văn xuống ESP32

Lệnh ESP32 | Chức năng
PING | HELLO ESP32 MECHANISM
GET STATUS | Trạng thái, vị trí, van, profile, step, zero và jog
GET CONFIG | Header CRC và năm profile
CMD profile | Chạy ROBOT START, PICK A, PICK B, RETRACT hoặc HOME
POINT A POINT B | Alias trực tiếp cho PICK A và PICK B
THA 2A THA 2B | Alias trực tiếp cho RETRACT
JOG speedA speedB | Điều khiển giữ tốc độ hai trục
JOG STOP | Dừng manual jog
VALVE n state | Điều khiển van 1 đến 5 khi idle
STOP ESTOP CMD STOP | Dừng ưu tiên và safe off van
SET ZERO | Đặt tọa độ phần mềm bằng zero
HOME | Về zero phần mềm
SET PROFILE | Cập nhật một profile trong RAM
SAVE | Ghi NVS và kiểm CRC
RESTORE DEFAULT | Nạp mặc định vào RAM
CLEAR FAULT | Xóa fault khi không bận
NANG HA SPEED POS | Tương thích lệnh USB cũ
SIM action | Xác nhận không chạy cơ cấu

# 12 Trình tự vận hành và kiểm tra

## 12 1 Trước khi cấp nguồn

9. Kiểm tra GND chung, TX RX nối chéo, dây BNO, ToF, hai MCP3008 và encoder.
10. Xác nhận vùng chạy trống, nguồn motor và nguồn van có nút ngắt độc lập, E STOP sẵn sàng.
11. Đặt cơ cấu trong vùng hành trình an toàn vì chưa có công tắc home hoặc limit trong source.
12. Đặt robot ở đúng vạch xuất phát và kiểm tra H1 H2 cùng các cụm 3 mắt theo map.

## 12 2 Khởi động bằng giao diện

13. Mở giao diện bằng Chrome hoặc Edge, chọn KẾT NỐI TEENSY và COM5 ở 57600 baud.
14. Chờ HELLO, GET CONFIG và MECH STATUS. Nếu cơ cấu offline, kiểm tra UART6.
15. Chọn AUTO, map RED hoặc BLUE, chọn REAL hoặc SIM 4S và chính sách telemetry.
16. Nếu dùng cơ cấu thật, đọc config ESP32, xác nhận zero và profile trước khi chạy.
17. Giữ robot DISARM và nhấn START AUTO ĐẾN CẦU. Không nhấn ARM trước vì ARM chỉ test khóa đầu.
18. Theo dõi sự kiện STATE, FAULT và DONE. Dùng snapshot khi cần nhưng không stream AUTO.

## 12 3 Khởi động không telemetry

19. Chờ BNO085 khởi tạo và đảm bảo robot không có fault chốt từ lần chạy trước.
20. Nhấn nút map chân 35 một lần cho RED hoặc hai lần nhanh cho BLUE; nghe 2 hoặc 3 tiếng xác nhận.
21. Nhấn START chân 34 một lần; nghe một tiếng. Firmware tự chuyển AUTO và chạy nếu đủ điều kiện.
22. Nếu còi cảnh báo chớp trong 2 giây, dừng cấp lực và kết nối telemetry để đọc fault.

## 12 4 Quy trình tune

23. Tune bốn bánh khi kê khỏi sàn trước, sau đó kiểm tra lại có tải ở tốc độ thấp, trung bình và cao.
24. Xác nhận chiều motor và encoder trước khi thay Kp Ki Kd KFF hoặc deadzone.
25. Tune KFF và deadzone để đạt gần target, sau đó tăng Kp, thêm Ki vừa đủ và chỉ dùng Kd khi dữ liệu tốc độ đủ sạch.
26. Tune heading sau khi bốn bánh đồng đều. Tune line sau khi heading ổn và min max cảm biến đúng.
27. Mọi PID Teensy chỉnh từ giao diện chỉ nằm trong RAM. Chép giá trị đã chốt vào RobotConfig h rồi build lại.

# 13 Điểm cần kiểm soát trước khi chốt bản thi đấu

Mức | Vấn đề | Tác động | Hướng xử lý
Cao | Repository chính đang dirty và Map_do chưa được theo dõi | Có thể mất hoặc nhầm phiên bản source | Commit theo mốc có tag và ghi checksum firmware hex
Cao | Không có E STOP vật lý độc lập trong source Teensy | Mất serial hoặc treo MCU có thể không nhận lệnh ESTOP | Bổ sung ngõ dừng phần cứng hoặc mạch cắt enable nguồn motor
Cao | ESP32 chưa có limit home switch | HOME dựa trên zero phần mềm và mất mốc sau sự cố | Gắn limit, homing từng trục và kiểm tra polarity
Cao | GPIO van và interlock chưa xác minh | Có thể kích sai van hoặc hai coil đối nghịch | Đo từng ngõ ra khi chưa cấp khí rồi điền interlock
Trung bình | H1 H2 dùng min max mặc định 0 1023 | Ngưỡng thực tế có thể ít biên chống nhiễu | Hiệu chuẩn riêng H1 H2 và lưu hằng số
Trung bình | Nhiều state và hằng số kế thừa không được dùng | Người chỉnh nhầm tham số nhưng robot không đổi | Xóa hoặc gắn nhãn legacy rõ trong code
Trung bình | RBT 2 có source nhưng main dùng RBT 1 ASCII | Hai giao thức dễ gây hiểu nhầm | Quyết định giữ RBT 1 hoặc hoàn tất tích hợp RBT 2
Trung bình | Nhãn EEPROM trên UI và protocol sai | Người vận hành tưởng PID Teensy đã lưu bền | Đổi nhãn thành RAM only và sửa tài liệu protocol
Trung bình | USB COM14 nhận lệnh nhưng phản hồi dùng macro Serial5 | Khó tune chỉ bằng USB | Tách hàm emit theo cổng nguồn lệnh hoặc ghi rõ giới hạn
Thấp | README Teensy còn chi tiết VL53L1X và tuyến cũ | Tài liệu cục bộ không khớp source | Cập nhật README từ báo cáo này

# 14 Ma trận tham số chính

Nhóm | Tham số | Giá trị | Ảnh hưởng
Kích thước | WHEEL DIAMETER MM | 100 | Quy đổi encoder và RPM
Kích thước | ROBOT LENGTH MM | 260 | k Mecanum
Kích thước | ROBOT WIDTH MM | 350 | k Mecanum
Encoder | COUNTS PER WHEEL REV | 300 | mm per count
Motor | MAX WHEEL SPEED | 1300 mm/s | Trần target bánh
Motor | TARGET ACCEL DECEL | 1400 2400 | Khởi động và dừng mềm
Chu kỳ | CONTROL PERIOD | 10000 us | 100 Hz
Heading | KP KI KD | 0.101 0 0.004 | Giữ yaw
Heading | LATERAL MAX WZ | 0.20 rad/s | Đi ngang A B
Line | ACTIVE NORMALIZED | 550 | Logic HIGH trên line đen
Line | PICK DETECT | 400 | Phát hiện line hẹp tốc độ cao
Line | CENTER CONTROL SIGN | -1 | Chiều hiệu chỉnh 8 mắt
H1 H2 | CONTROL SIGN | +1 | Chiều kéo đuôi và đầu về line
ToF | TARGET | 160 mm | Thông tin tại A B; dùng trong state căn ToF nếu gọi
ToF | VALID RANGE | 35 đến 800 mm | Lọc target
Xuất phát | START ENCODER | 170 mm ở 280 mm/s | Bỏ qua ToF
A | EXPECTED LATERAL | 1075 cộng trừ 200 mm | Cửa sổ tìm line
A đến B | DISTANCE | 200 mm ở 300 mm/s | Relative move
Sau B | POST B LEFT | 1300 mm ở 800 mm/s | Tìm line cầu
Cầu | APPROACH ASCENT DESCENT | 1000 1300 400 mm/s | Theo phase độ nghiêng
UART | TELEMETRY PERIOD | 200 ms | 5 Hz ngoài AUTO ARM
UART | MANUAL WATCHDOG | 500 ms | Dừng DRIVE
UART | POSITION WATCHDOG | 600 ms | Dừng MOVE GOTO
Cơ cấu | SIM DELAY | 4000 ms | AUTO mô phỏng
Cơ cấu | REPLY TIMEOUT | 15000 ms | FAULT ESP

# 15 Phụ lục danh mục hàm

Các bảng sau được trích tự động từ source hiện tại. Số dòng giúp tra cứu trong VS Code; số dòng có thể thay đổi sau khi sửa code.

## Teensy main cpp

Dòng | Hàm | Tham số
20 | beginUsbCommandStream
236 | selectedFieldLateralSign
241 | selectedFieldUsesRightStopGroup
247 | secondPickUsesRightStopGroup
436 | applyFactoryPidConfig
456 | wrap180 | float angle
462 | shortestAngleError | float target, float current
466 | readFloatLE | const uint8_t *p
472 | readU32LE | const uint8_t *p
482 | stationAlignmentInProgress
489 | setFault | FaultCode fault, const char *reason
505 | stopInputActive
509 | clearFaults
517 | hardwareConfigurationValid
522 | competitionConfigurationValid
531 | wheelTuneConfigurationValid
536 | configurationAllowsMotion
545 | writeMotor | WheelControl &wheel, int pwm
551 | resetWheelPid | WheelControl &wheel
559 | resetAllControllers
577 | stopRobot
586 | setRobotVelocity | float vx, float vy, float wz
631 | updateEncoderMeasurements | float dt
644 | updateWheelSpeedPid | float dt
672 | enableBnoReport
680 | initializeBno085
694 | quaternionYaw | float real, float i, float j, float k
699 | quaternionRoll | float real, float i, float j, float k
704 | quaternionPitch | float real, float i, float j, float k
709 | updateBno085
781 | headingControl | float dt, float limit = MAX_HEADING_WZ_RAD_S
799 | headingControlFine | float dt, float limit = FINE_HEADING_MAX_WZ_RAD_S
813 | headingControlLateral | float dt
841 | headingControlStationary | float dt
873 | readMCP3008Raw | uint8_t csPin, uint8_t channel
882 | readMCP3008 | uint8_t csPin, uint8_t channel
889 | normalizeLine | uint16_t raw, uint16_t minimum, uint16_t maximum
897 | updateLineArrays
989 | updateLineFollowing | float dt, float &vx
1014 | printLineCalibration
1026 | printCenterCalibrationTelemetry
1035 | printStopCalibrationTelemetry
1122 | updateOpticalFlow
1145 | medianTof
1156 | updateTof
1197 | resetPose | float x=0, float y=0, float yaw=0
1206 | updateOdometry | float dt
1231 | lateralXHoldVelocity
1257 | resetLateralLineHold
1264 | lateralLineHoldVelocity | float dt
1301 | firstLateralGuidanceReady
1324 | beginRelativeMove | float dx, float dy, float maxSpeed=MOVE_SPEED_MM_S
1336 | beginAbsoluteMove | float targetX,float targetY,float targetYaw,float maxSpeed
1345 | updateAbsoluteMove | float dt
1380 | updateRelativeMove | float dt
1403 | updateRelativeLateralMoveWithHold | float dt
1424 | updateRelativeMoveWithLine | float dt
1442 | updateBridgeLineUntilEndMarker | float dt
1512 | updateYawAlignment | float dt, float tolerance=1.0f
1520 | updateTofAlignment | float dt
1561 | beginStopAlignment | float searchVy,uint8_t crossings,bool rightGroup
1569 | updateStopAlignment | float dt
1688 | stopGroupActiveCount | uint8_t offset
1695 | pointARequiredSensorsOnLine | bool rightGroup
1708 | updatePointAPassMemory | bool rightGroup
1716 | updateAutoPickTravel | float dt,bool rightGroup,uint8_t targetCount
1800 | updateAutoPickX | float dt,bool rightGroup
1896 | autoHeadingAligned
1906 | autoPickVerified
1912 | reportStationTofInfo | const char *point
1950 | sendEsp | const char *command
1970 | printAutoStartConfiguration | const char *source
1976 | printAutoTelemetryMode
1981 | requestAutoTelemetrySnapshot
1994 | printAutoMechanismStatus
2006 | printMechanismTelemetryStatus
2019 | beginAutoMechanismAction | const char *command
2037 | autoMechanismActionComplete
2058 | handleMechanismLine | const char *line, void *
2073 | updateEspProtocol
2098 | tunerWheelIndex | const char *name
2106 | wheelRpmToMmS | float rpm
2107 | wheelMmSToRpm | float speed
2109 | sendTunerConfig
2138 | enterPassiveTest | TestMode mode
2142 | processCommand | const char *line
2516 | updateUsbCommands
2525 | updateTestMode | float dt
2630 | onExitState | AutoState
2632 | transitionTo | AutoState next
2638 | onEnterState
2784 | checkStateTimeout
2794 | updateCompetition | float dt
3023 | printAutoTelemetrySnapshotStage
3065 | printTelemetry
3211 | confirmPhysicalField | FieldSide field
3218 | startAutoFromPhysicalButton
3258 | updatePhysicalControls
3291 | setup
3370 | loop

## Teensy Esp32MechanismClient cpp

Dòng | Hàm | Tham số
3 | Esp32MechanismClient::begin | uint8_t rxPin, uint8_t txPin, uint32_t baud
11 | Esp32MechanismClient::send | const char *line
15 | Esp32MechanismClient::update | LineHandler handler, void *context

## Teensy MechanismTelemetryView cpp

Dòng | Hàm | Tham số
6 | MechanismTelemetryView::consume | const char *line
33 | MechanismTelemetryView::updateTimeout | uint32_t timeoutMs

## Teensy RBT2 Protocol cpp

Dòng | Hàm | Tham số
12 | packetCrc | const uint8_t *packet, size_t length
27 | crc16Ccitt | const uint8_t *data, size_t length, uint16_t initial
37 | encodePacket | PacketType type, uint32_t sequence, uint32_t timestampMs, const void *payload, uint16_t payloadLength, uint8_t *output,
64 | StreamParser::StreamParser | PacketHandler handler, void *context) : handler_(handler), context_(context
67 | StreamParser::reset
73 | StreamParser::beginHeader
81 | StreamParser::feed | uint8_t byte
108 | StreamParser::feed | const uint8_t *data, size_t length
113 | StreamParser::validateHeader
136 | StreamParser::finishPacket

## ESP32 main cpp

Dòng | Hàm | Tham số
23 | setup
42 | loop

## ESP32 MechanismController cpp

Dòng | Hàm | Tham số
9 | MechanismController::MechanismController | AccelStepper &motorA, AccelStepper &motorB, ValveController &valves) : motorA_(motorA), motorB_(motorB), valves_(valves
14 | MechanismController::begin | MechanismConfig &config
27 | MechanismController::stepsPerMmA | const StepperProfile &p
31 | MechanismController::stepsPerMmB | const StepperProfile &p
35 | MechanismController::positionAmm
41 | MechanismController::positionBmm
47 | MechanismController::selectProfileScale | ProfileId id
59 | MechanismController::targetsWithinLimits | float targetAmm, float targetBmm
68 | MechanismController::issueProfileMotion | const StepperProfile &p
103 | MechanismController::startProfile | ProfileId id
117 | MechanismController::startDirectMove | float signedAmm, float signedBmm, float speedStepsPerSecond
142 | MechanismController::applyJogAxis | AccelStepper &motor, uint8_t axis, float speed, long target, float acceleration
160 | MechanismController::setJog | float signedSpeedA, float signedSpeedB
193 | MechanismController::stopJog
205 | MechanismController::advanceStep
210 | MechanismController::sensorValue | uint8_t sensorIndex, bool &available
221 | MechanismController::update
290 | MechanismController::setValve | uint8_t index, bool enabled
299 | MechanismController::setSoftwareZero
306 | MechanismController::startHome
314 | MechanismController::emergencyStop | const char *reason
328 | MechanismController::clearFault
336 | MechanismController::completeOperation
342 | MechanismController::setFault | MechanismFault fault, const char *reason
356 | MechanismController::takeDoneEvent | char *profileText, size_t capacity
366 | MechanismController::takeFaultEvent | char *reason, size_t capacity

## ESP32 PersistentConfig cpp

Dòng | Hàm | Tham số
9 | setReason | char *reason, size_t capacity, const char *text
16 | PersistentConfig::begin
21 | PersistentConfig::load | MechanismConfig &config, char *reason, size_t reasonCapacity
47 | PersistentConfig::save | MechanismConfig &config, char *reason, size_t reasonCapacity
76 | PersistentConfig::erase | char *reason, size_t reasonCapacity

## ESP32 StepperProfiles cpp

Dòng | Hàm | Tham số
10 | initProfile | StepperProfile &profile, const char *name, float distanceA, float distanceB, int8_t directionA, int8_t directionB, uint3
40 | finiteInRange | float value, float minimum, float maximum
44 | setReason | char *reason, size_t capacity, const char *text
58 | parseProfileId | const char *text, ProfileId &id
69 | loadDefaultMechanismConfig | MechanismConfig &config
90 | mechanismConfigCrc | const MechanismConfig &config
102 | validateMechanismConfig | const MechanismConfig &config, char *reason, size_t reasonCapacity

## ESP32 UartProtocol cpp

Dòng | Hàm | Tham số
20 | uppercaseAscii | char *text
27 | isSimulatedAutoAction | const char *action
33 | UartProtocol::UartProtocol | Stream &usb, Stream &robot, MechanismController &controller, MechanismConfig &config, PersistentConfig &persistentConfig
40 | UartProtocol::begin
48 | UartProtocol::emit | const char *line
53 | UartProtocol::emitAck | const char *token
59 | UartProtocol::emitError | const char *code, const char *detail
66 | UartProtocol::readStream | Stream &stream, Receiver &receiver
89 | UartProtocol::runNamedProfile | const char *name
102 | UartProtocol::updateProfile | const char *arguments
146 | UartProtocol::emitCapabilities
150 | UartProtocol::processJog | const char *arguments
173 | UartProtocol::processLine | char *rawLine
242 | UartProtocol::emitProfile | ProfileId id
255 | UartProtocol::emitConfig
267 | UartProtocol::emitStatus
278 | UartProtocol::update

## ESP32 ValveController cpp

Dòng | Hàm | Tham số
5 | ValveController::writeOne | uint8_t index, bool enabled
11 | ValveController::begin
21 | ValveController::set | uint8_t index, bool enabled
31 | ValveController::setMask | uint8_t mask
43 | ValveController::safeOff

## ESP32 simulator main cpp

Dòng | Hàm | Tham số
24 | isSupportedCommand | const char *command
48 | startSimulatedAction | const char *command
89 | processCompleteLine
98 | readRobotCommands
120 | finishSimulatedActionWhenDue
142 | setup
158 | loop

## Giao diện page tsx

Dòng | Hàm hoặc component | Tham số
96 | escapeXml | value: unknown
100 | excelCell | value: string | number, style = ""
105 | Pill | { tone = "good", children }: { tone?: "good" | "warn" | "bad" | "off"; children: React.ReactNode }
109 | Gauge | { current, target }: { current: number; target: number }
119 | GainsEditor | { gains, onChange }: { gains: Gains; onChange: (key: keyof Gains, value: number) => void }
123 | SectionTitle | { eyebrow, title, action }: { eyebrow: string; title: string; action?: React.ReactNode }
127 | Home
233 | if | !manualDriveActiveRef.current && !heartbeatPendingRef.current && queuedWritesRef.current === 0
285 | if | kind === "WHEEL"
321 | if | ["HELLO", "CFG", "CFG_END", "ACK", "ERR"].includes(fields[0])
325 | if | fields[0] === "MECH_STATUS" && fields.length >= 13
329 | if | [fault, positionA, positionB, valveMask, step].every(Number.isFinite)
338 | if | fields[1] === "STATUS" && fields.length >= 11
341 | if | [fault, positionA, positionB, valveMask, step].every(Number.isFinite)
358 | if | mechanismProfileIds.includes(id)
360 | if | values.every(Number.isFinite)
387 | if | fields[1] === "MODE" && (fields[2] === "ON_REQUEST" || fields[2] === "SILENT")
401 | if | [fault, vx, vy, wz, x, y, poseYaw, actualYaw, wantedYaw, distance].every(Number.isFinite)
424 | if | fields[1] === "FAULT"
457 | if | values.every(Number.isFinite)
465 | if | values.every(Number.isFinite)
471 | if | values.every(Number.isFinite)
481 | if | values.every(Number.isFinite)
487 | if | values.every(Number.isFinite)
546 | if | fields[1] === "RESET"
547 | if | fields[1] === "ESTOP"
558 | if | fields[0] === "WHEEL" && fields.length >= 6
563 | if | id && [targetRpm, actualRpm, pwm, encoder].every(Number.isFinite)
581 | if | values.every(Number.isFinite)
585 | if | active
586 | if | !motionLogActiveRef.current
595 | if | now - motionLogCountUpdatedAtRef.current >= 500
614 | if | !motionLogRef.current.length
669 | while | portRef.current === port
671 | if | value
676 | for | const raw of lines
690 | if | connected
709 | if | !serial
741 | if | !connected
748 | if | !configSynced
755 | if | !configSynced
756 | if | robotArmed
758 | if | manualWz < .05 || manualWz > 1.5 || autoWz < .05 || autoWz > 2 || deadbandDeg < 0 || deadbandDeg > 5 || minWz < 0 || min
770 | if | !configSynced
777 | if | direction !== 0 && !wheelTuneReady
783 | if | manualDriveTimerRef.current !== null
796 | while | latestDriveRef.current !== null
808 | if | !connected || !configSynced
847 | if | !mechanismConfigSynced
865 | if | next === "mechanism"
877 | if | autoTelemetryMode === "SILENT"
927 | Overview | { wheels, yaw, targetYaw, lineError, lineRawReady, tofDistance, tofValid, open }: { wheels: Wheel[]; yaw: number; target
935 | MotionControl | { connected, manualReady, positionReady, fault, pose, yaw, targetYaw, manualHeadingLock, setManualHeading, setManualYaw,
980 | AutoControl | { connected, ready, mode, field, state, armed, fault, estop, bnoValid, tofDistance, tofValid, tofTarget, yaw, targetYaw,
1036 | MechanismNumber | { label, value, unit, min, max, step = 1, disabled, onChange }: { label: string; value: number; unit: string; min?: numb
1112 | Drive | { wheels, selectedWheel, setSelectedWheel, changeGain, tuneTargetRpm, changeTarget, ready, sendPid, applyAll, command }:
1117 | Heading | { yaw, target, setTarget, gains, setGain, limits, setLimit, maxWheelSpeed, setMaxWheelSpeed, sendSettings, saveConfig, s
1127 | Line | { error, gains, centerRaw, centerNormalized, centerCalMin, centerCalMax, calibrationActive, centerValid, centerPosition,
1175 | Config | { send }: { send: (command: string) => void }
1180 | Diagnostics | { connected, linkAlive, rx, tx, state, fault, armed }: { connected: boolean; linkAlive: boolean; rx: number; tx: number;

## Giao diện manual jog

Dòng | Hàm hoặc phương thức | Tham số
12 | MechanismJog | { ready, supported, connected, busy, positions, confirmedSpeeds, write }: Props
24 | if | !ready
51 | if | !Number.isFinite(speed[axis]) || speed[axis] < 10 || speed[axis] > 30000
81 | if | event.key === " " || event.key === "Enter"
10 | constructor | private send: Send, private onError: () => void
12 | setEnabled | enabled: boolean
17 | setAxis | axis: 0 | 1, speed: number
23 | if | !this.speeds.some(Boolean)
27 | stop | force = false
36 | pump

# 16 Phụ lục toàn bộ hằng số RobotConfig

Bảng này liệt kê mọi constexpr tìm thấy trong RobotConfig h để kiểm soát thay đổi. Giá trị mảng được giữ theo thứ tự source. Hãy ưu tiên bảng Ma trận tham số chính khi vận hành và dùng phụ lục này khi review code.

Dòng | Tên | Giá trị trong source
10 | HARDWARE_CONFIG_VERIFIED | true
13 | DEBUG_TELEMETRY | false
16 | WHEEL_DIAMETER_MM | 100.0f
17 | ROBOT_LENGTH_MM | 260.0f
18 | ROBOT_WIDTH_MM | 350.0f
19 | ENCODER_COUNTS_PER_WHEEL_REV | 300.0f
20 | DISTANCE_CALIBRATION | 1.0f
24 | RED_FIELD_LATERAL_SIGN | 1
25 | BLUE_FIELD_LATERAL_SIGN | -1
27 | MOTOR_SIGN_FL | 1
28 | MOTOR_SIGN_FR | -1
31 | MOTOR_SIGN_RL | 1
32 | MOTOR_SIGN_RR | -1
34 | ENCODER_SIGN_FL | -1
36 | ENCODER_SIGN_FR | 1
37 | ENCODER_SIGN_RL | 1
38 | ENCODER_SIGN_RR | -1
42 | MECANUM_X_CONFIGURATION | true
45 | FL_RPWM | 36, FL_LPWM = 37
46 | FR_RPWM | 22, FR_LPWM = 23
47 | RL_RPWM | 18, RL_LPWM = 19
48 | RR_RPWM | 14, RR_LPWM = 15
50 | FL_ENC_A | 0, FL_ENC_B = 1
51 | FR_ENC_A | 6, FR_ENC_B = 7
52 | RL_ENC_A | 2, RL_ENC_B = 3
53 | RR_ENC_A | 4, RR_ENC_B = 5
55 | PWM_FREQUENCY_HZ | 20000
56 | PWM_MAX | 255
57 | MAX_WHEEL_SPEED_MM_S | 1300.0f
58 | WHEEL_SPEED_FILTER_ALPHA | 0.35f
59 | CONTROL_PERIOD_US | 10000
62 | WHEEL_TARGET_ACCEL_MM_S2 | 1400.0f
63 | WHEEL_TARGET_DECEL_MM_S2 | 2400.0f
70 | WHEEL_KP[4] | { 0.15f, 0.14f, 0.14f, 0.15f }
76 | WHEEL_KI[4] | { 0.08f, 0.08f, 0.12f, 0.10f }
82 | WHEEL_KD[4] | { 0.0f, 0.0f, 0.0f, 0.0f }
88 | WHEEL_KFF[4] | {0.035f, 0.045f, 0.034f, 0.034f}
89 | WHEEL_DEADZONE_PWM[4] | {36, 34, 34, 34}
90 | WHEEL_INTEGRAL_LIMIT | 250.0f
93 | POSITION_X_KP | 1.40f
94 | POSITION_X_KI | 0.05f
95 | POSITION_X_KD | 0.01f
96 | POSITION_X_INTEGRAL_LIMIT | 400.0f
97 | POSITION_Y_KP | 1.40f
98 | POSITION_Y_KI | 0.05f
99 | POSITION_Y_KD | 0.01f
100 | POSITION_Y_INTEGRAL_LIMIT | 400.0f
101 | STOP_FORWARD_KP | 0.20f
102 | STOP_FORWARD_KI | 0.01f
103 | STOP_FORWARD_KD | 0.002f
104 | STOP_FORWARD_INTEGRAL_LIMIT | 600.0f
105 | STOP_YAW_KP | 0.0018f
106 | STOP_YAW_KI | 0.0001f
107 | STOP_YAW_KD | 0.00002f
108 | STOP_YAW_INTEGRAL_LIMIT | 500.0f
109 | TOF_DISTANCE_KP | 0.80f
110 | TOF_DISTANCE_KI | 0.0f
111 | TOF_DISTANCE_KD | 0.0f
112 | TOF_DISTANCE_INTEGRAL_LIMIT | 300.0f
113 | RIGHT_LINE_KP | 0.08f
114 | RIGHT_LINE_KI | 0.0f
115 | RIGHT_LINE_KD | 0.0f
116 | RIGHT_LINE_INTEGRAL_LIMIT | 1000.0f
117 | LEFT_LINE_KP | 0.08f
118 | LEFT_LINE_KI | 0.0f
119 | LEFT_LINE_KD | 0.0f
120 | LEFT_LINE_INTEGRAL_LIMIT | 1000.0f
124 | BNO085_I2C_ADDRESS | 0x4A
125 | SENSOR_I2C_HZ | 100000
126 | BNO_USE_GAME_ROTATION_VECTOR | true
130 | BNO_YAW_SIGN | 1
131 | BNO_REPORT_INTERVAL_US | 10000
132 | BNO_TIMEOUT_MS | 250
133 | BNO_RETRY_INTERVAL_MS | 1000
135 | HEADING_KP | 0.101f
136 | HEADING_KI | 0.0f
137 | HEADING_KD | 0.004f
138 | HEADING_INTEGRAL_LIMIT | 30.0f
139 | MAX_HEADING_WZ_RAD_S | 1.2f
140 | MAX_MANUAL_HEADING_WZ_RAD_S | 0.60f
141 | MAX_AUTO_HEAD_LOCK_WZ_RAD_S | 1.00f
142 | MAX_LINE_ALIGN_WZ_RAD_S | 0.45f
143 | MAX_BRIDGE_HEADING_WZ_RAD_S | 0.25f
144 | HEADING_OUTPUT_DEADBAND_DEG | 0.50f
145 | HEADING_MIN_WZ_RAD_S | 0.18f
146 | FINE_HEADING_KP | 0.120f
147 | FINE_HEADING_KD | 0.0030f
148 | FINE_HEADING_DEADBAND_DEG | 0.25f
149 | FINE_HEADING_MIN_WZ_RAD_S | 0.180f
150 | FINE_HEADING_MAX_WZ_RAD_S | 0.35f
154 | STATION_HEADING_DEADBAND_DEG | 0.45f
155 | STATION_HEADING_MIN_WZ_RAD_S | 0.05f
156 | STATION_HEADING_MAX_WZ_RAD_S | 0.16f
157 | STATION_HEADING_SLEW_RAD_S2 | 0.55f
158 | STATION_HEADING_SETTLED_RATE_DEG_S | 2.0f
161 | LATERAL_HEADING_DEADBAND_DEG | 0.45f
162 | LATERAL_HEADING_MIN_WZ_RAD_S | 0.06f
163 | LATERAL_HEADING_MAX_WZ_RAD_S | 0.20f
164 | LATERAL_HEADING_SLEW_RAD_S2 | 0.80f
165 | LATERAL_LINE_COUNT_MAX_YAW_ERROR_DEG | 2.0f
166 | LATERAL_HEADING_RECOVERY_SPEED_FACTOR | 0.45f
169 | MCP_CENTER_CS | 26
170 | MCP_STOP_CS | 8
173 | STOP_LEFT_CHANNELS[3] | {3, 4, 5}
174 | STOP_RIGHT_CHANNELS[3] | {0, 1, 2}
175 | MCP_SPI_HZ | 1000000
179 | LINE_IS_HIGHER_THAN_FLOOR | true
180 | CENTER_SENSOR_MIN[8] | {84,79,76,75,74,75,81,83}
181 | CENTER_SENSOR_MAX[8] | {1023,1023,1023,1023,969,866,1023,1023}
183 | STOP_SENSOR_MIN[6] | {76,76,76,80,83,81}
184 | STOP_SENSOR_MAX[6] | {1023,1023,1023,1023,1023,1023}
187 | LATERAL_HOLD_SENSOR_MIN[2] | {0, 0}
188 | LATERAL_HOLD_SENSOR_MAX[2] | {1023, 1023}
190 | LATERAL_HOLD_TAIL_CHANNEL | 6
191 | LATERAL_HOLD_FRONT_CHANNEL | 7
192 | LATERAL_HOLD_LINE_THRESHOLD | 500
195 | LATERAL_HOLD_CONTROL_SIGN | 1
196 | LATERAL_HOLD_CORRECTION_SPEED_MM_S | 65.0f
197 | LATERAL_HOLD_SEARCH_SPEED_MM_S | 35.0f
198 | LATERAL_HOLD_SLEW_MM_S2 | 220.0f
199 | LATERAL_HOLD_LOST_TIMEOUT_MS | 450
200 | LATERAL_HOLD_ACQUIRE_TIMEOUT_MS | 1200
204 | FIRST_LATERAL_BLIND_DISTANCE_MM | 400.0f
205 | CENTER_LINE_CALIBRATION_VERIFIED | true
206 | STOP_LINE_CALIBRATION_VERIFIED | true
209 | STOP_SENSOR_ORDER_VERIFIED | true
210 | LINE_FILTER_ALPHA | 0.55f
211 | LINE_ACTIVE_NORMALIZED | 550
212 | CROSS_MIN_ACTIVE_SENSORS | 6
213 | CROSS_CONFIRM_MS | 35
214 | CROSS_RELEASE_MS | 100
215 | LINE_SHORT_LOST_MS | 180
216 | LINE_FAULT_TIMEOUT_MS | 650
217 | LINE_KP | 0.16f
218 | LINE_KI | 0.02f
219 | LINE_KD | 0.003f
221 | CENTER_LINE_CONTROL_SIGN | -1
224 | MAX_LINE_VY_MM_S | 220.0f
225 | LINE_LOST_SEARCH_VY_MM_S | 140.0f
228 | STOP_WEIGHTS[3] | {-1000, 0, 1000}
229 | STOP_POSITION_TOLERANCE | 120.0f
230 | STOP_SIDE_DIFFERENCE_TOLERANCE | 150.0f
231 | STOP_ALIGNMENT_CONFIRM_MS | 180
232 | STOP_CROSS_CONFIRM_MS | 40
233 | STOP_CROSS_RELEASE_MS | 100
241 | PICK_A_LINE_TARGET | 2
242 | PICK_B_LINE_TARGET | 1
245 | BRIDGE_LINE_TARGET | 3
246 | LINE_DEBOUNCE_MS | 40
247 | LINE_CLEAR_DEBOUNCE_MS | 100
250 | PICK_LINE_DETECT_NORMALIZED | 400
251 | PICK_LINE_CONFIRM_MS | 8
252 | PICK_LINE_CLEAR_MS | 60
253 | X_ALIGN_STABLE_TIME_MS | 180
254 | LINE_SEARCH_TIMEOUT_MS | 5000
255 | HEADING_STABLE_TIME_MS | 350
256 | HEADING_TOLERANCE_DEG | 0.60f
257 | MOVE_LEFT_SPEED_MM_S | 400.0f
261 | LATERAL_LONGITUDINAL_HOLD_ENABLED | false
263 | LATERAL_X_HOLD_KP | 1.20f
264 | LATERAL_X_HOLD_DEADBAND_MM | 6.0f
265 | LATERAL_X_HOLD_MAX_SPEED_MM_S | 140.0f
268 | LATERAL_TOF_HOLD_KP | 0.90f
269 | LATERAL_TOF_HOLD_DEADBAND_MM | 8.0f
270 | LATERAL_TOF_HOLD_MAX_SPEED_MM_S | 130.0f
272 | BRIDGE_LATERAL_SCAN_SPEED_MM_S | 500.0f
273 | X_ALIGN_MAX_SPEED_MM_S | 80.0f
274 | X_ALIGN_SEARCH_SPEED_MM_S | 35.0f
277 | POINT_B_PAIR_TARGET_POSITION | 500.0f
278 | POINT_B_PAIR_SEARCH_TIMEOUT_MS | 10000
279 | TOF_ALIGN_MAX_SPEED_MM_S | 100.0f
280 | BRIDGE_FORWARD_SPEED_MM_S | 1300.0f
281 | BRIDGE_APPROACH_SPEED_MM_S | 1000.0f
282 | BRIDGE_DESCENT_SPEED_MM_S | 400.0f
285 | BRIDGE_INCLINE_ENTER_DEG | 5.0f
286 | BRIDGE_CREST_LEVEL_DEG | 4.0f
287 | BRIDGE_INCLINE_CONFIRM_MS | 150
288 | BRIDGE_CREST_CONFIRM_MS | 120
289 | BRIDGE_MIN_ASCENT_BEFORE_CREST_MS | 300
290 | BRIDGE_END_MARKER_CONFIRM_MS | 80
291 | BNO_TILT_FILTER_ALPHA | 0.35f
292 | BRIDGE_LINE_SEARCH_RADIUS_MM | 180.0f
293 | BRIDGE_LINE_SEARCH_SPEED_MM_S | 60.0f
294 | BRIDGE_ENTRY_CENTER_KP | 0.08f
296 | BRIDGE_ENTRY_CENTER_MIN_VY_MM_S | 90.0f
297 | BRIDGE_ENTRY_CENTER_MAX_VY_MM_S | 140.0f
298 | BRIDGE_ENTRY_CENTER_TOLERANCE | 300.0f
299 | BRIDGE_ENTRY_CENTER_CONFIRM_MS | 80
302 | BRIDGE_STOP_CROSS_TARGET | 3
303 | BRIDGE_LINE_ACQUIRE_CONFIRM_MS | 180
304 | BRIDGE_LINE_ACQUIRE_TIMEOUT_MS | 10000
305 | BRIDGE_FOLLOW_TIMEOUT_MS | 20000
307 | TOF_CONTROL_SIGN | 1
310 | LEFT_STOP_CONTROL_SIGN | 1
311 | RIGHT_STOP_CONTROL_SIGN | -1
317 | OPTICAL_FLOW_ENABLED | false
319 | FLOW_BAUD | 115200
320 | MAVLINK_OPTICAL_FLOW_RAD_ID | 106
321 | MAVLINK_OPTICAL_FLOW_RAD_LEN | 44
322 | MAVLINK_OPTICAL_FLOW_RAD_CRC_EXTRA | 138
323 | FLOW_X_FROM_SENSOR_AXIS | 0
324 | FLOW_Y_FROM_SENSOR_AXIS | 1
325 | FLOW_X_SIGN | 1
326 | FLOW_Y_SIGN | 1
327 | FLOW_SCALE_X_MM | 1.0f
328 | FLOW_SCALE_Y_MM | 1.0f
329 | FLOW_MIN_QUALITY | 80
330 | FLOW_TIMEOUT_MS | 250
331 | ODOM_ENCODER_WEIGHT | 1.0f
332 | ODOM_FLOW_WEIGHT | 0.0f
333 | LATERAL_SLIP_THRESHOLD_MM_S | 180.0f
338 | TOF_ENABLED | true
339 | TOF_I2C_ADDRESS | 0x29
341 | TOF_TARGET_MM | 160
342 | TOF_MIN_VALID_MM | 35
343 | TOF_MAX_VALID_MM | 800
345 | TOF_MAX_SAMPLE_JUMP_MM | 250
346 | TOF_TIMEOUT_MS | 1500
349 | TOF_ALIGNMENT_RECOVERY_MS | 3000
353 | START_ENCODER_DISTANCE_MM | 170.0f
354 | START_ENCODER_SPEED_MM_S | 280.0f
355 | START_LATERAL_DISTANCE_MM | 1000.0f
356 | START_LATERAL_SPEED_MM_S | 400.0f
357 | START_HOLD_LINE_SEARCH_SPEED_MM_S | 280.0f
358 | START_HOLD_LINE_CONFIRM_MS | 100
359 | START_HOLD_LINE_SEARCH_TIMEOUT_MS | 8000
362 | POINT_A_RIGHT_ALIGN_SPEED_MM_S | 50.0f
363 | POINT_A_RIGHT_SENSOR_THRESHOLD | 500
364 | POINT_A_RIGHT_CONFIRM_MS | 120
365 | POINT_A_RIGHT_PAIR_WINDOW_MS | 1200
366 | POINT_A_RIGHT_SEARCH_TIMEOUT_MS | 15000
370 | POINT_A_EXPECTED_LATERAL_MM | 1075.0f
371 | POINT_A_SEARCH_HALF_RANGE_MM | 200.0f
372 | POINT_A_SEARCH_SPEED_MM_S | 70.0f
375 | POINT_A_TO_B_DISTANCE_MM | 200.0f
376 | POINT_A_TO_B_SPEED_MM_S | 300.0f
379 | POINT_A_H_SEARCH_RADIUS_MM | 100.0f
380 | POINT_A_H_SEARCH_SPEED_MM_S | 35.0f
381 | POINT_A_H_SEARCH_TIMEOUT_MS | 15000
383 | POST_B_LEFT_DISTANCE_MM | 1300.0f
384 | POST_B_LEFT_SPEED_MM_S | 800.0f
385 | TOF_START_ESCAPE_DISTANCE_MM | 250.0f
386 | TOF_START_ESCAPE_SPEED_MM_S | 300.0f
387 | TOF_MEDIAN_SAMPLES | 5
388 | TOF_COARSE_SPEED_MM_S | 180.0f
389 | TOF_FINE_SPEED_MM_S | 65.0f
390 | TOF_TOLERANCE_MM | 30.0f
391 | TOF_CONFIRM_MS | 200
397 | TELEMETRY_BAUD | 57600
398 | TELEMETRY_RX_PIN | 21
399 | TELEMETRY_TX_PIN | 20
403 | ESP32_UART_ENABLED | true
405 | ESP32_TX_PIN | 24
406 | ESP32_RX_PIN | 25
407 | ESP32_BAUD | 57600
411 | AUTO_MECHANISM_SIM_DELAY_MS | 4000
414 | ESP32_REPLY_TIMEOUT_MS | 15000
415 | STATE_DEFAULT_TIMEOUT_MS | 12000
418 | TELEMETRY_PERIOD_MS | 200
419 | TUNER_WATCHDOG_MS | 600
420 | MANUAL_DRIVE_WATCHDOG_MS | 500
421 | POSITION_LINK_WATCHDOG_MS | 600
424 | MAX_POSITION_HEADING_WZ_RAD_S | 0.35f
428 | PHYSICAL_CONTROL_BUTTONS_ENABLED | true
429 | PHYSICAL_START_BUTTON_PIN | 34
430 | PHYSICAL_FIELD_BUTTON_PIN | 35
431 | PHYSICAL_BUTTON_DEBOUNCE_MS | 35
432 | PHYSICAL_FIELD_DOUBLE_CLICK_MS | 450
435 | BUZZER_PIN | 40
436 | BUZZER_ACTIVE_HIGH | true
437 | BUZZER_BEEP_ON_MS | 110
438 | BUZZER_BEEP_OFF_MS | 100
439 | BUZZER_PATTERN_GAP_MS | 180
440 | BUZZER_ALARM_TOGGLE_MS | 120
441 | BUZZER_ALIGNMENT_ALARM_MS | 2000
449 | SENSOR_TO_CENTER_MM | 20.0f
450 | START_APPROACH_MM | 125.0f
451 | C_OFFSET_MM | 150.0f
452 | HOME_TO_B_MM | 410.0f
453 | RETURN_A_MM | 330.0f
454 | RETURN_LONG_MM | 2650.0f
455 | RETURN_LATERAL_MM | 1650.0f
456 | MOVE_SPEED_MM_S | 450.0f
459 | BRIDGE_SPEED_FAST_MM_S | 1150.0f
460 | BRIDGE_SPEED_SLOW_MM_S | 1000.0f
461 | BRIDGE_ACCEL_MM_S2 | 1800.0f
462 | BRIDGE_DECEL_MM_S2 | 700.0f

# 17 Thư viện và môi trường build

Khối | Thư viện hoặc framework | Phiên bản hoặc vai trò
Teensy | Arduino Teensy | Framework 1.60 trên Teensy platform 5.1.0
Teensy | Encoder | 1.4.4; đọc encoder quadrature
Teensy | Adafruit BNO08x | 1.2.7; SH2 Game Rotation Vector
Teensy | PWFusion VL53L3C | 1.0.0; multi target ToF
Teensy | SPI và Wire | Thư viện lõi Arduino
ESP32 | Arduino ESP32 | Platform Espressif32 6.11.0
ESP32 | AccelStepper | 1.64; phát xung không chặn
ESP32 | Preferences | NVS thuộc Arduino ESP32
UI | React | 19.2.6
UI | Next | 16.2.6
UI | TypeScript | 5.9.3
UI | vinext và Vite | vinext 0.0.50; Vite 8.0.13
UI | Cloudflare plugin | Deploy Worker và Sites

# 18 Quy tắc kiểm soát thay đổi

28. Mỗi lần chốt hoạt động ổn định, commit đồng thời RobotConfig h, main cpp, ESP32 source, giao diện và tài liệu protocol.
29. Gắn tag theo ngày và nội dung thử, lưu file hex hoặc bin kèm checksum và log chạy thật.
30. Mỗi thay đổi route phải cập nhật một bảng state gồm điều kiện vào, điều kiện ra, timeout, cảm biến chính và hành động lỗi.
31. Không tái sử dụng chân mà chưa cập nhật bảng chân và kiểm tra xung đột UART PWM encoder I2C SPI.
32. Mọi tham số tune từ giao diện phải được chép về RobotConfig h hoặc profile ESP32 rồi build lại. Chỉ ESP32 SAVE mới ghi NVS.
33. Giữ một test checklist theo map RED và BLUE, tốc độ thấp và tốc độ thi đấu, nguồn đầy và nguồn giảm, không tải và có tải.
34. Trước khi thi đấu, tạo bản release chỉ chứa state đang dùng, xóa hằng số không tham chiếu hoặc đánh dấu legacy bằng tên riêng.

Tóm tắt sử dụng tài liệu Khi robot có hành vi sai, bắt đầu từ state đang báo trên giao diện, đối chiếu bảng luồng AUTO, kiểm tra cảm biến quyết định của state đó, sau đó mới thay PID hoặc tốc độ. Nếu giao diện báo gửi thành công nhưng cơ cấu không chạy, kiểm tra lần lượt chiều gửi COM5, UART6, MECH STATUS, fault ESP32 và zero phần mềm.

Trang | Snapshot ngày 08 tháng 09 năm 2026

ROBOCON 2026 | Tài liệu kiểm soát phần mềm

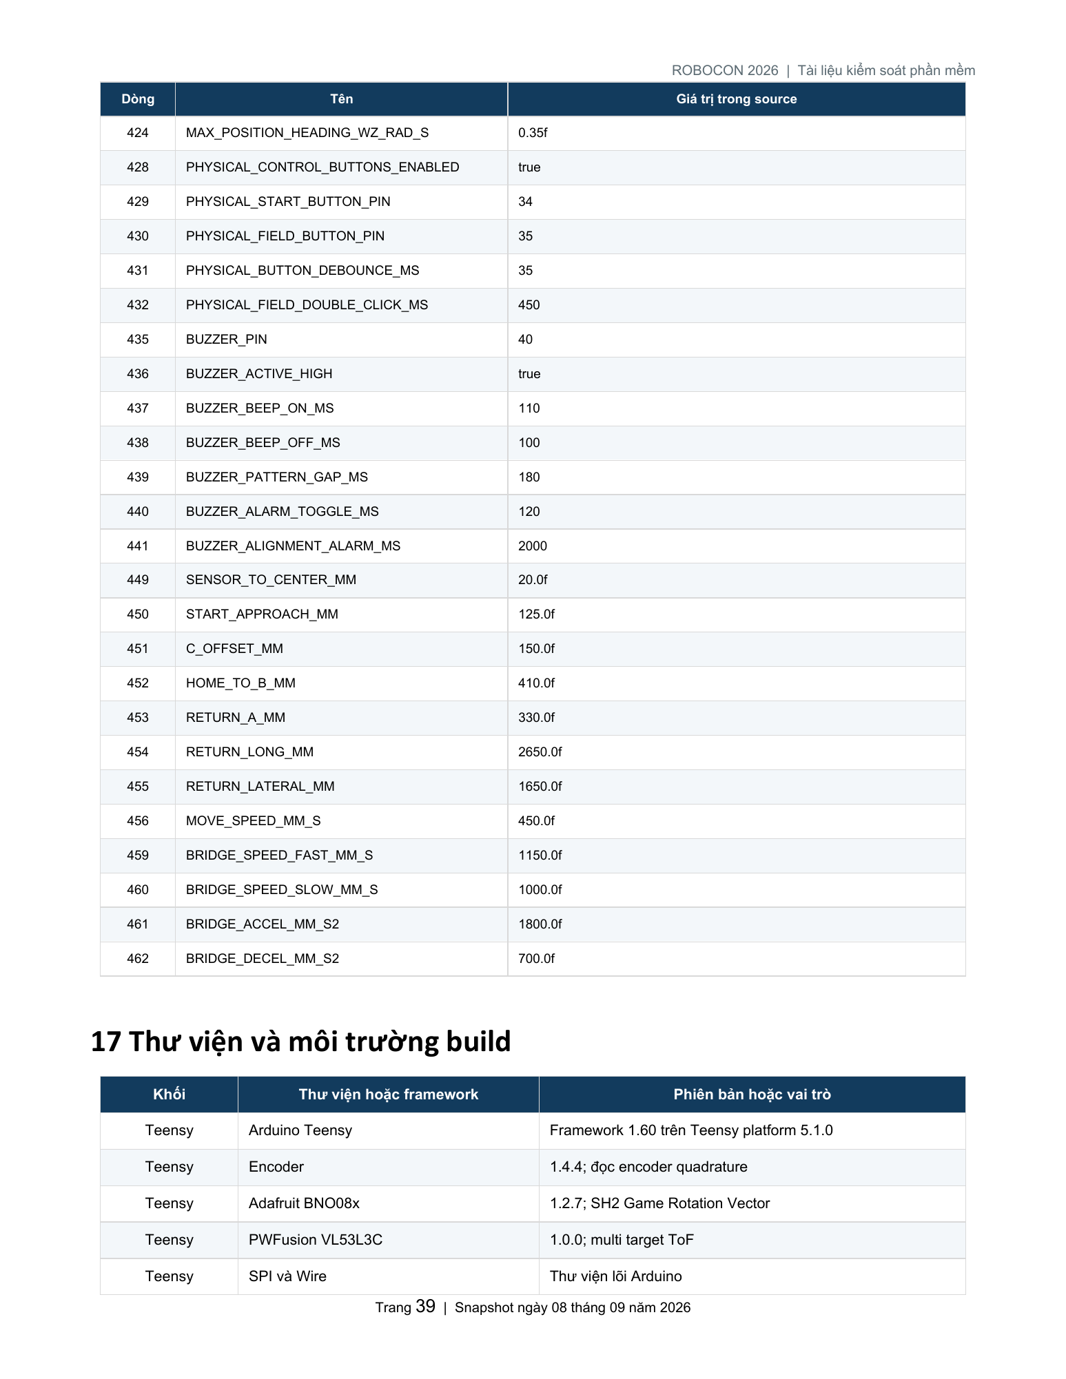
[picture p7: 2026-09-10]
docs/.report_tmp/rendered_final/page-39.png

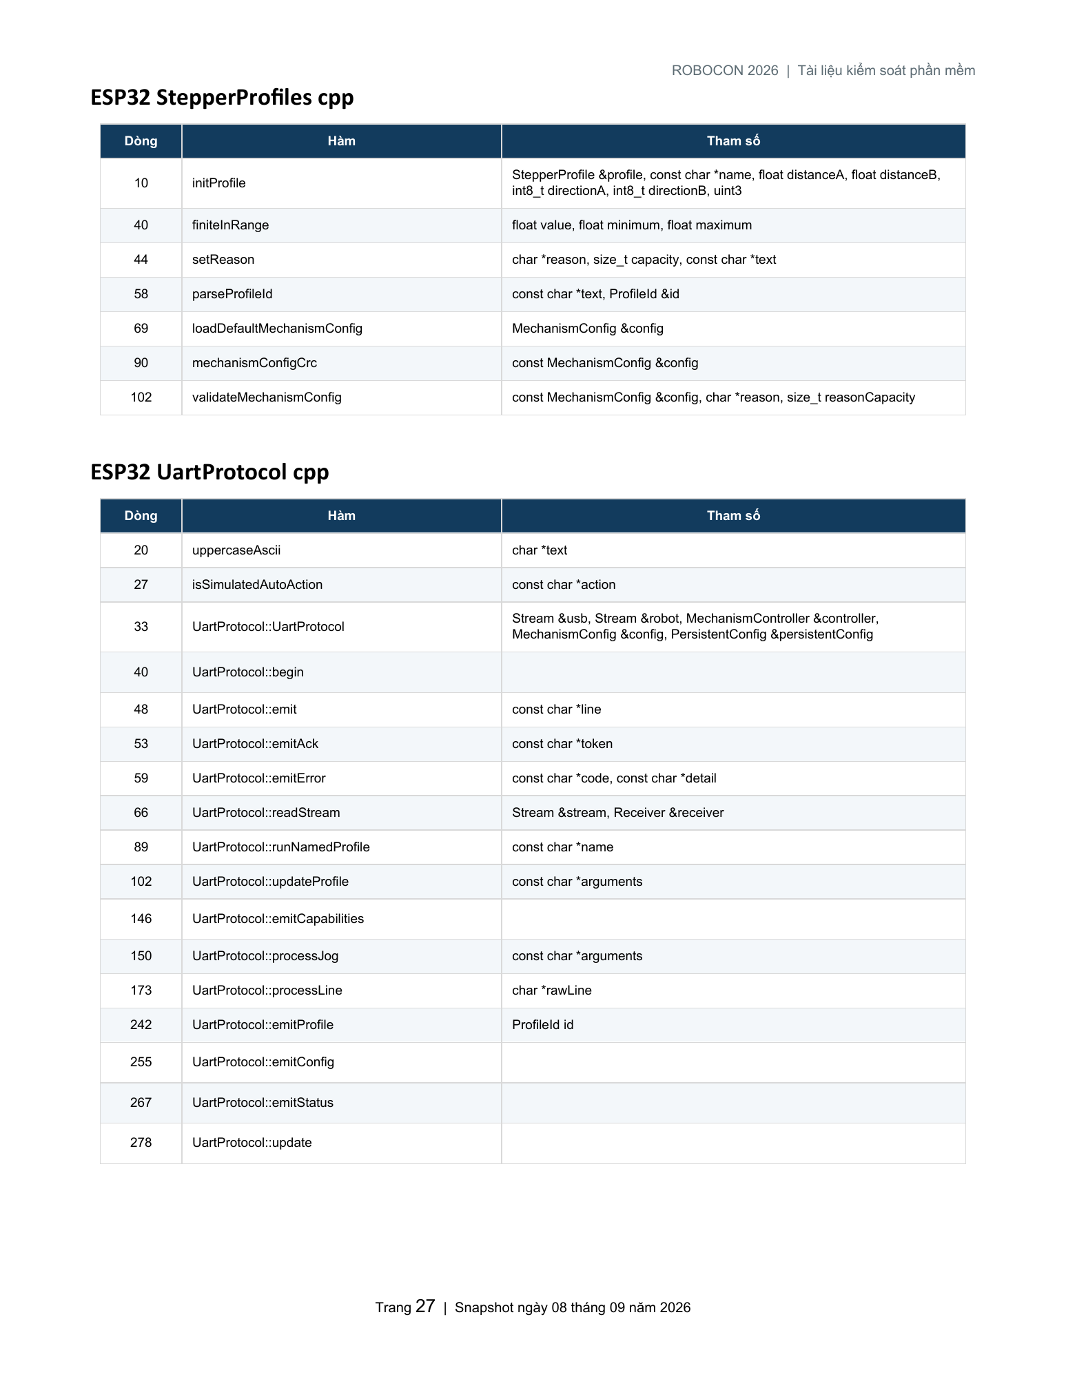
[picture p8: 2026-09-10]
docs/.report_tmp/rendered_final/page-27.png

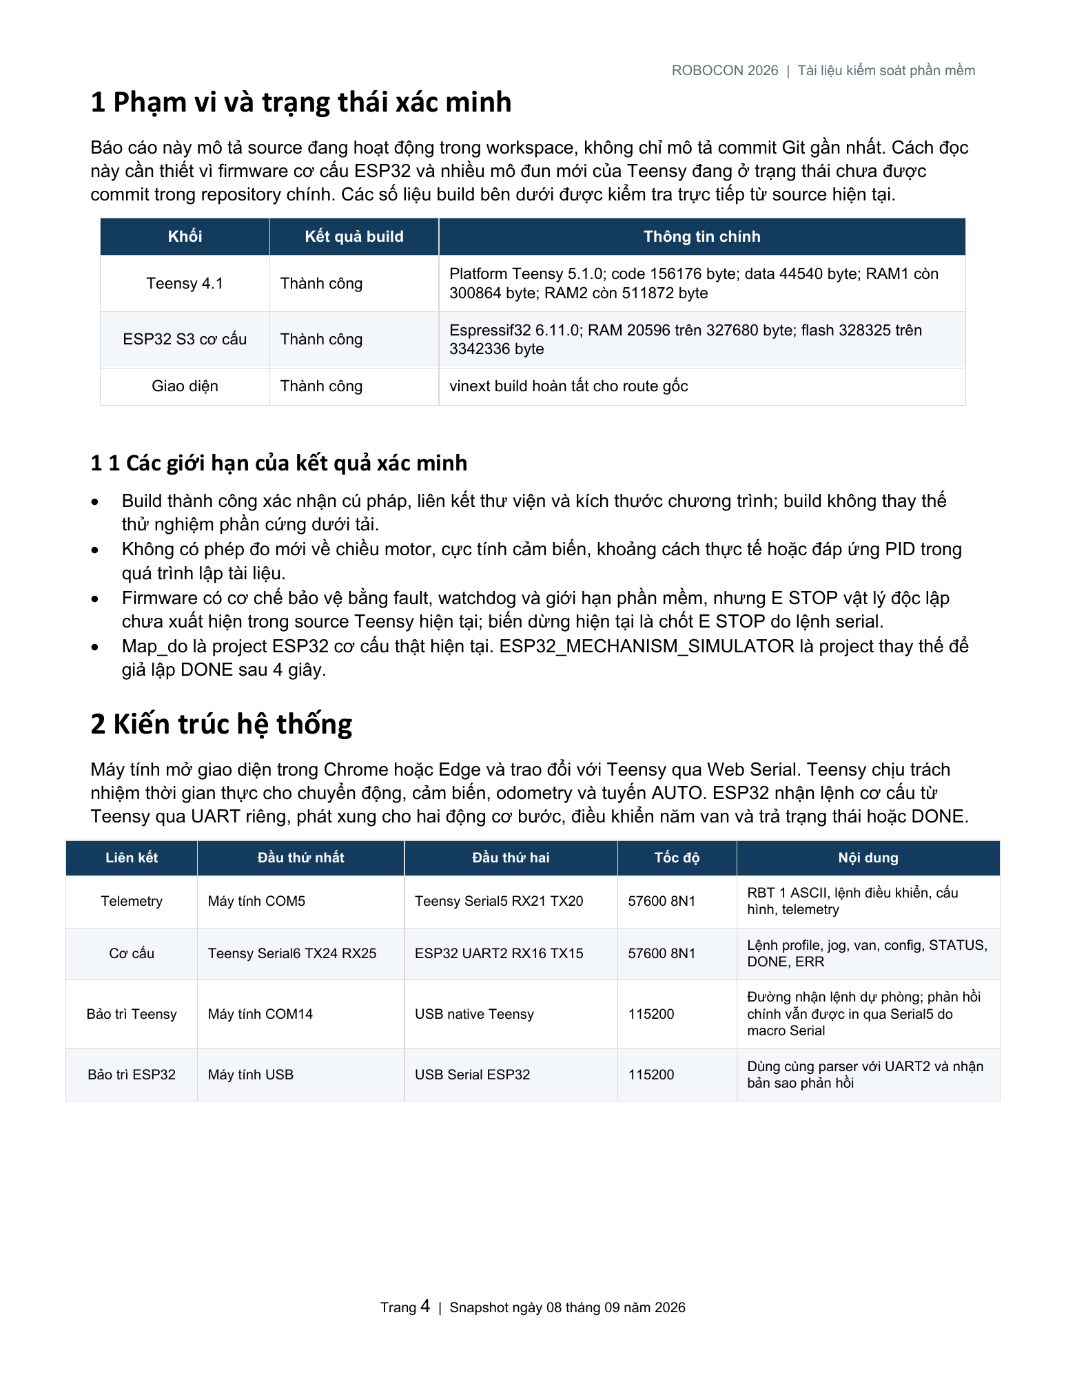
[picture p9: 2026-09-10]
docs/.report_tmp/rendered_final_v2/page-4.png

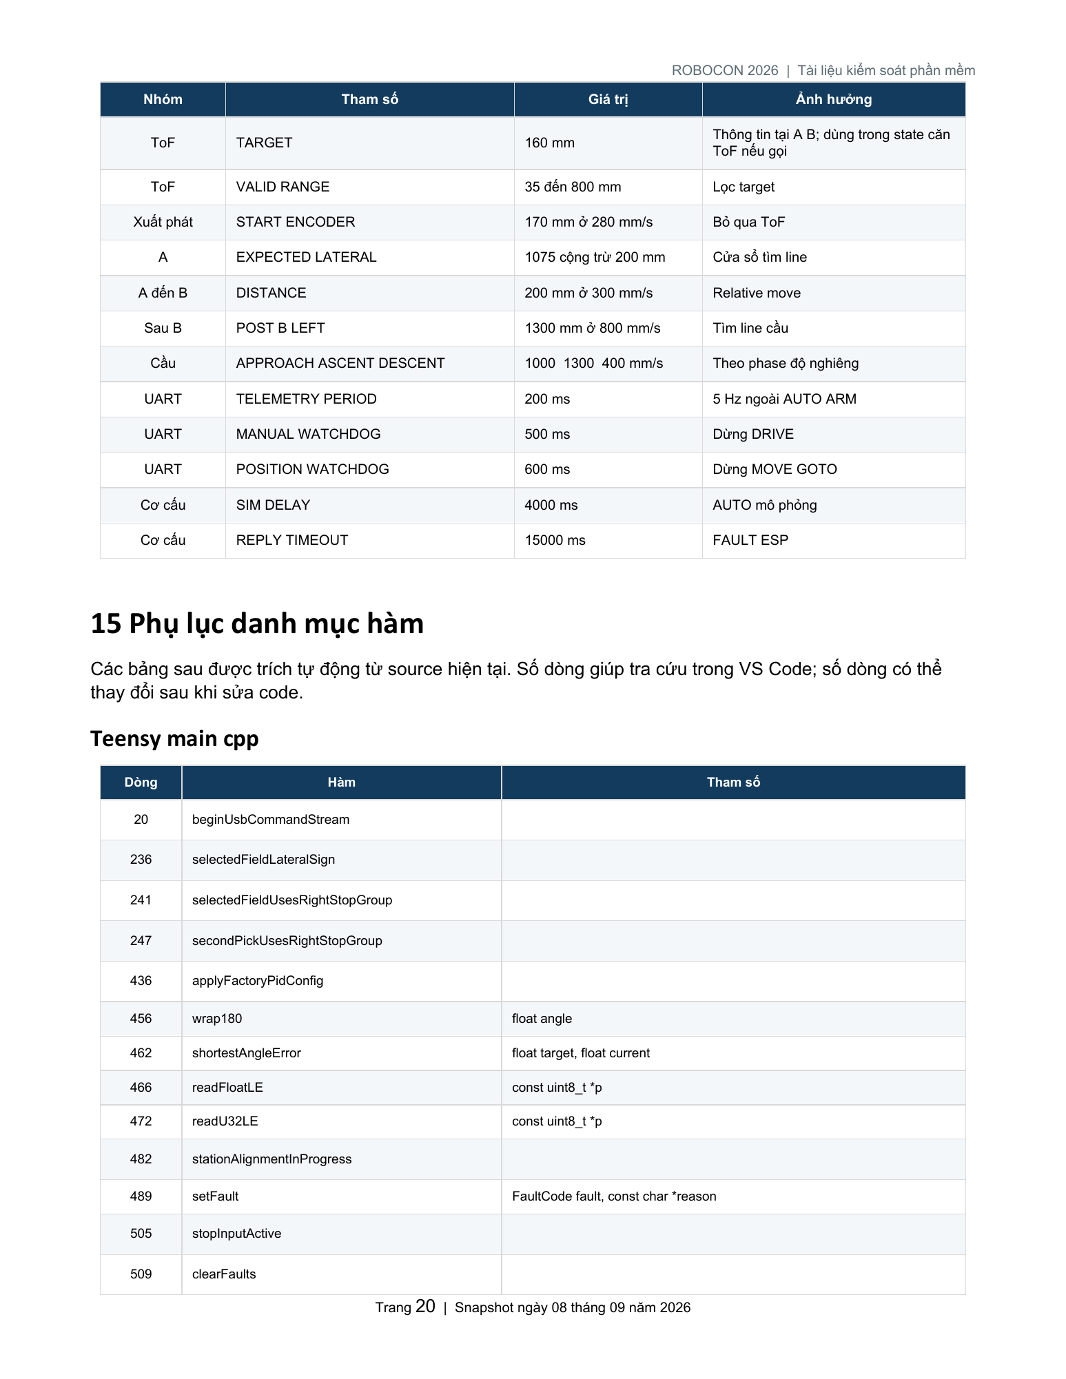
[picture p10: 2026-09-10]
docs/.report_tmp/rendered_final_v2/page-20.png

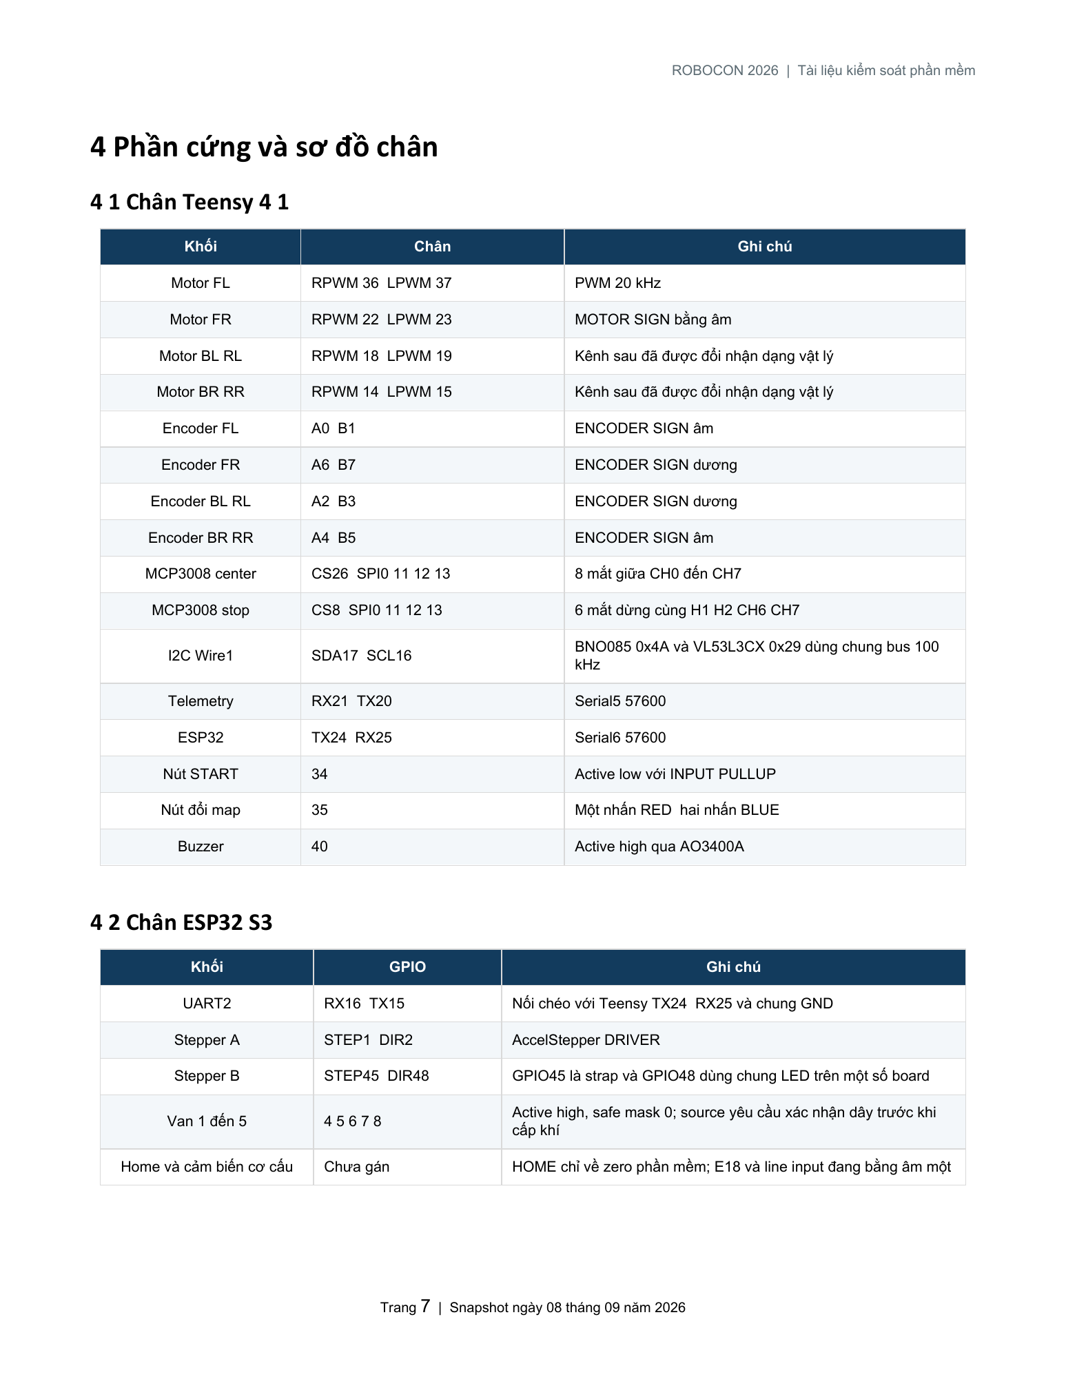
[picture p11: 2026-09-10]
docs/.report_tmp/rendered_final/page-7.png

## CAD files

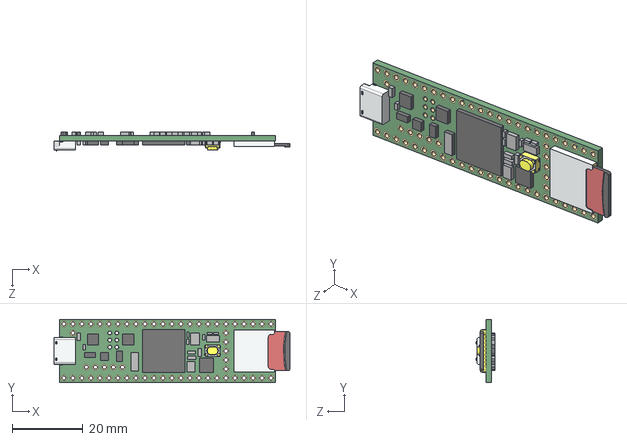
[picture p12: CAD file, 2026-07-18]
hardwave/ROBOCON_T9_LOGIC/teensy_4-1_assembly-1.snapshot.1/Teensy_4.1_Assembly.STEP
66.6 x 17.8 x 5.27 mm

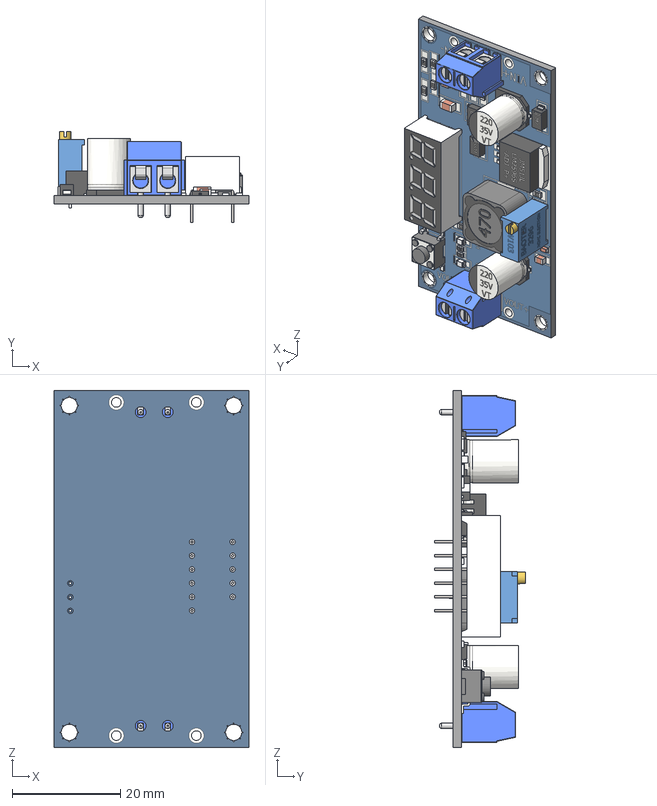
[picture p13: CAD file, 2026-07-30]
cad/buck-converter-lm2596-with-led-1.snapshot.1/LM2596_Led.stp
36.0 x 16.8 x 66.0 mm
Board
Resistor (0603) x 4
Resistor (0603)_1
Resistor (0603)_4 x 2
Resistor (0603)_3 x 2
Resistor (0603)_2
Resistor (0603)_5 x 2
Capacitor (0805)
Capacitor (0805)_1 x 2
Capacitor (0805)_2
Led x 2
button
Inductor_470
Diode M7
Diode M7_1
D882
LM2596S
TB5P-2P_P5_L10_W7-6_H10 x 2
Capacitor 35V x 2
Baoter_3296
2381BS-8.3

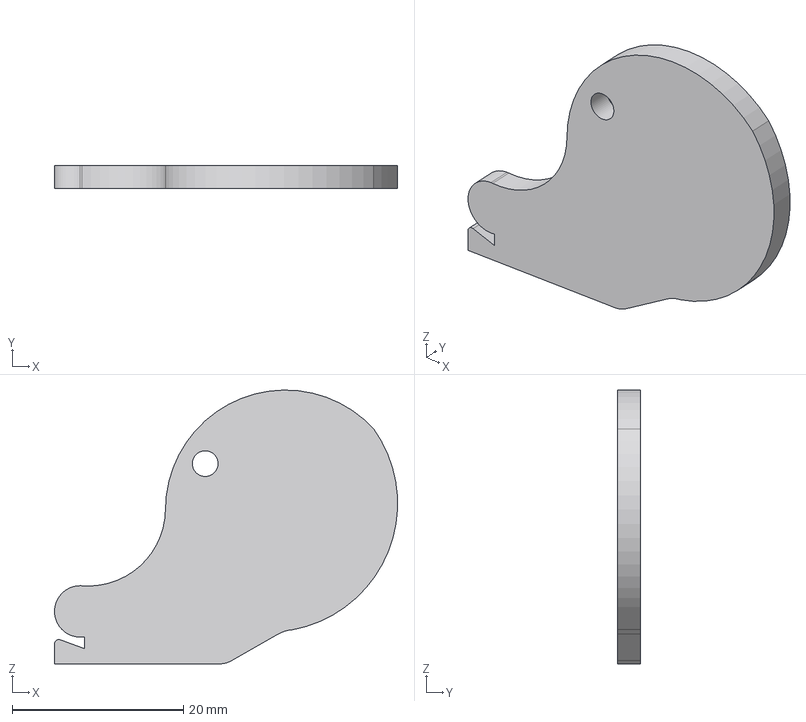
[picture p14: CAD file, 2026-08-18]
cad/KHOA_CHUONG_HEO/22.step
40.0 x 2.70 x 32.0 mm

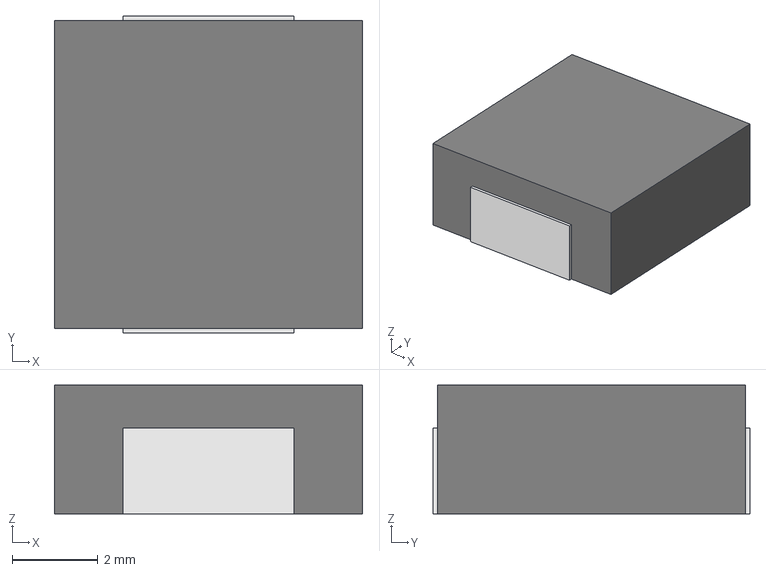
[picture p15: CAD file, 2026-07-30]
hardwave/MP1584/d-sun-dc-dc-step-down-voltage-regulator-simple-version-1.snapshot.4/components/Induct_7.2x7.2x3.0mm_simple.step
7.20 x 7.40 x 3.00 mm

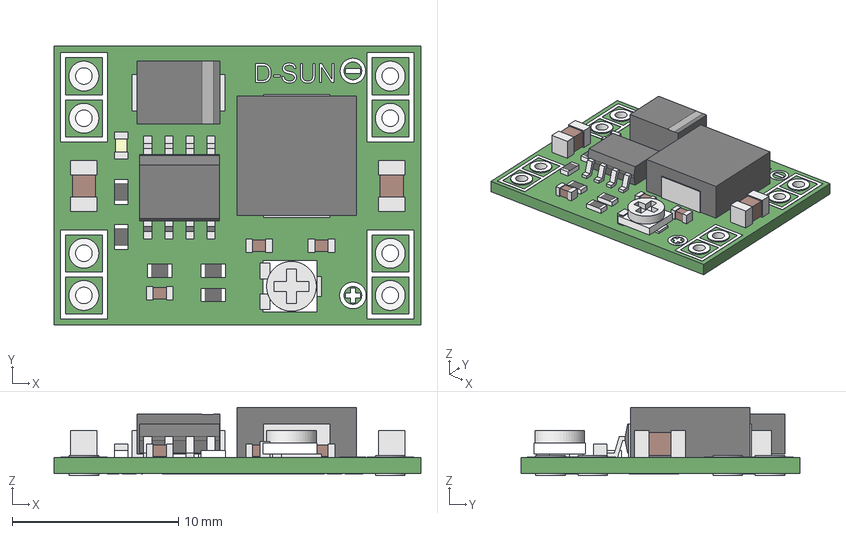
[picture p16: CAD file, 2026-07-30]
hardwave/MP1584/d-sun-dc-dc-step-down-voltage-regulator-simple-version-1.snapshot.4/D-SUN_dcdc_step_down_SIMPLE.step
22.1 x 16.8 x 4.10 mm
main001
silk-TOP
pins
silk-bot
comp-top

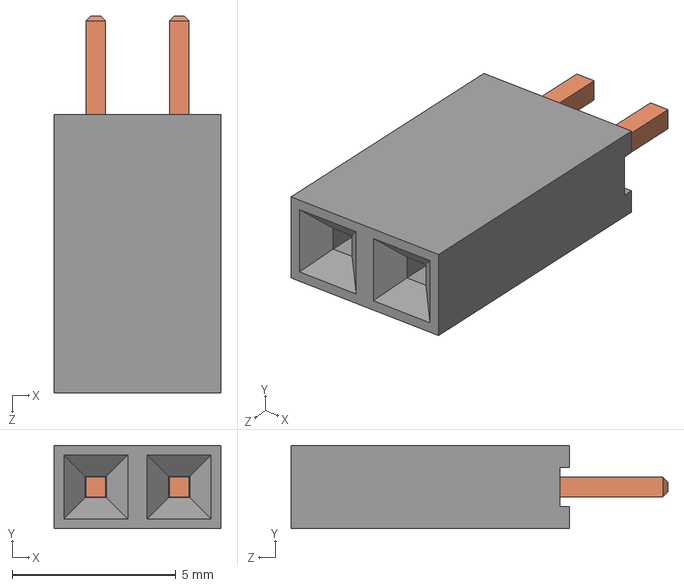
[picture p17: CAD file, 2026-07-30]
hardwave/MP1584/FemaleHeader.STEP
5.08 x 2.54 x 11.5 mm

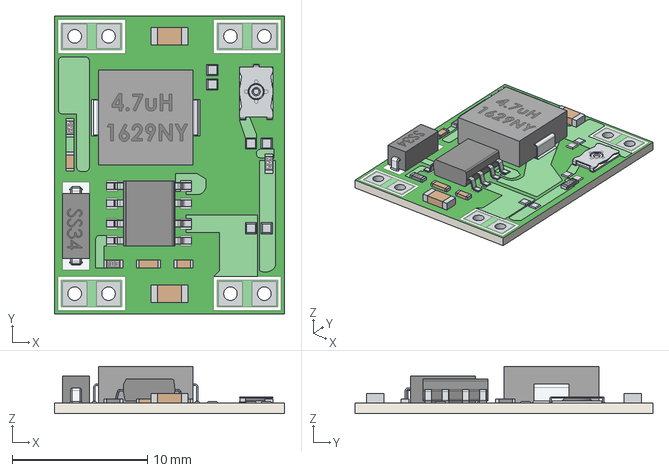
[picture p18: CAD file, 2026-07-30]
hardwave/MP1584/mp1584-1.snapshot.2/MP1584 Regulador.step
17.0 x 22.0 x 3.50 mm

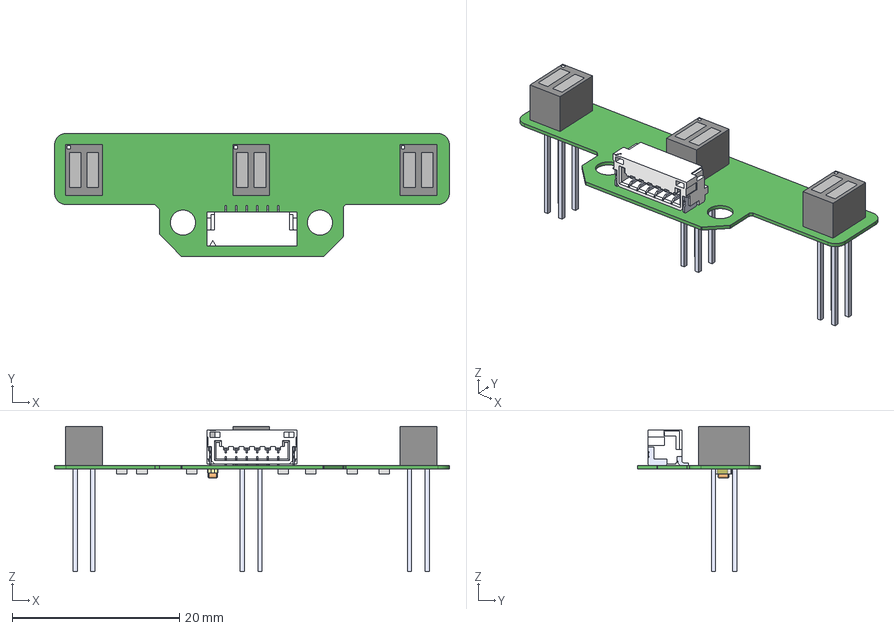
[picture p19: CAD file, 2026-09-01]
hardwave/ROBOCON_KOSEN/matline3/3matline.step
47.2 x 14.7 x 17.3 mm
SMxB-GHS-TB_06
pin x 6
SW3dPS-smt_resistor_packages x 7
User Library-led_0805-orange

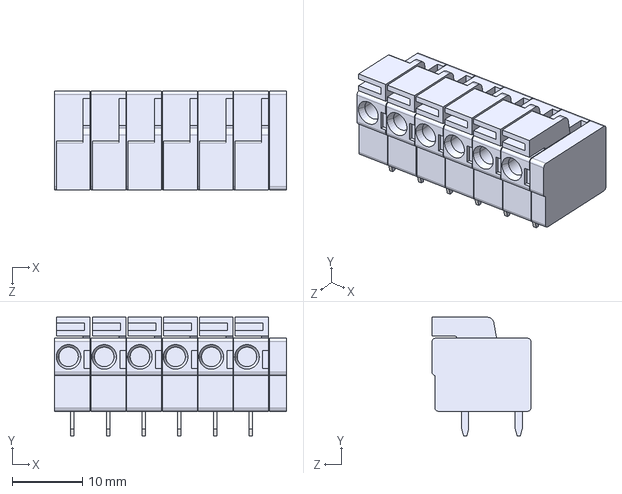
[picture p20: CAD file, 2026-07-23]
hardwave/ROBOCON_T9_LOGIC/pcb-spring-terminal-blocks-dg-142r-kf-142r-5-08-1.snapshot.16/DG142R-5-5.08.STEP
33.0 x 16.9 x 14.1 mm

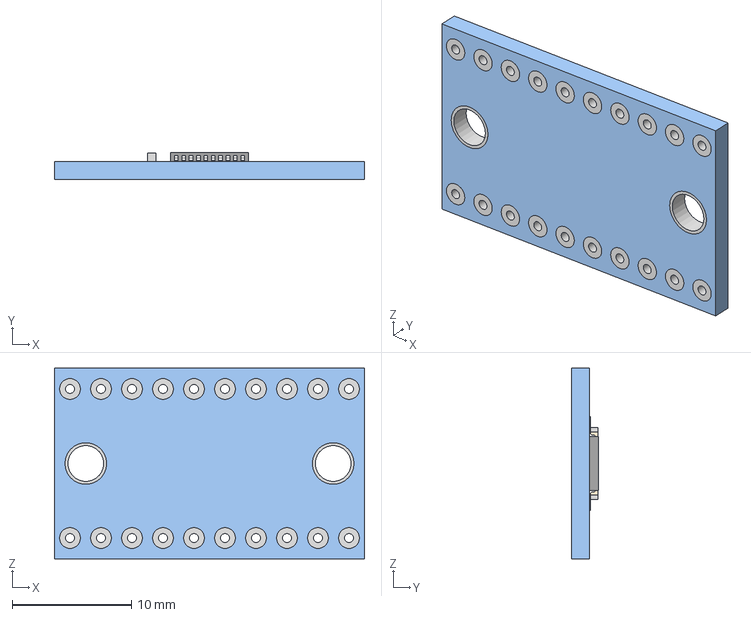
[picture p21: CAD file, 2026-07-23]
hardwave/ROBOCON_T9_LOGIC/TXS0108E.step
26.0 x 2.26 x 16.0 mm

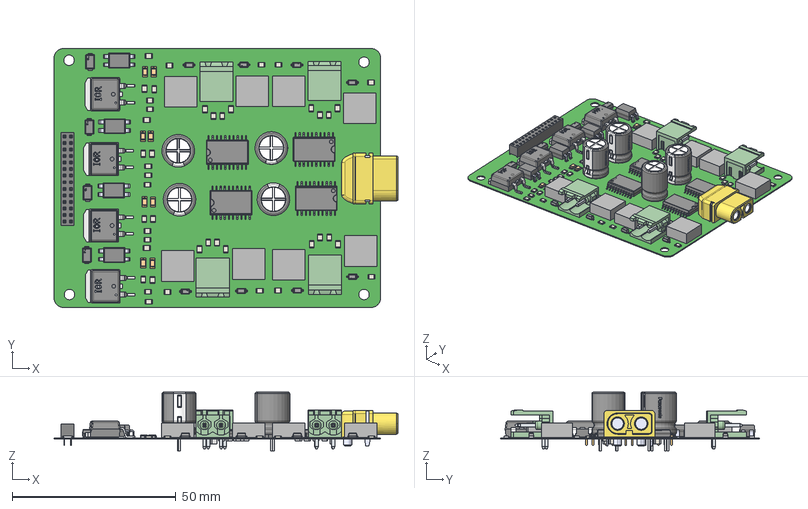
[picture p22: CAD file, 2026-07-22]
hardwave/ROBOCON_T9_V1/PCB1.step
105.1 x 79.1 x 18.0 mm
Extruded x 200
IRF logo x 4
Logo x 8
notch x 8
bb x 8
ON Semi Logo - 1 x 4
6200xx21821 x 28
XT60PW-F_XT60PW-F
diodes Logo x 1.6 x 8
diodes Logo x 1.6 - 1 x 8
BODY_DW0028A x 4
LEAD_DW0028A x 80
6913125100xx_PIN x 8
marking x 4
bottom x 4
logo x 4
polarity marking x 4
top x 4
terminal x 4

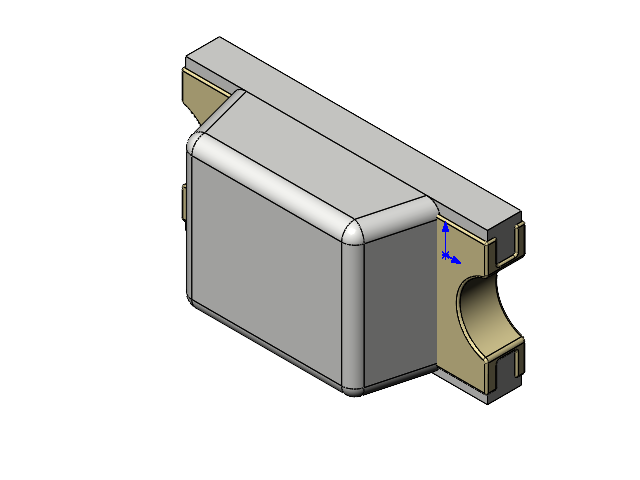
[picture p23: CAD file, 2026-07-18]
hardwave/ROBOCON_T9_V1/esp32-s3-wroom-1-1.snapshot.2/LED_0603 v4.SLDASM
Body.step
Cover.step
Cover_Mini.step
Insides.step

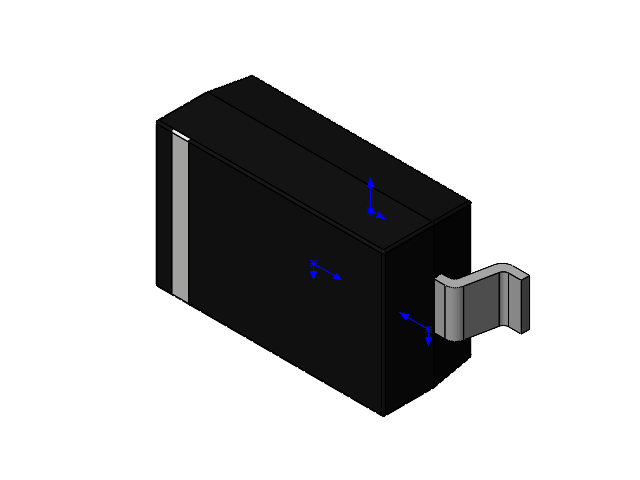
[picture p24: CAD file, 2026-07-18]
hardwave/ROBOCON_T9_V1/esp32-s3-wroom-1-1.snapshot.2/sod123 v4.SLDASM
pin.step
pin(Mirror).step
icbody_1.step
Component5.step

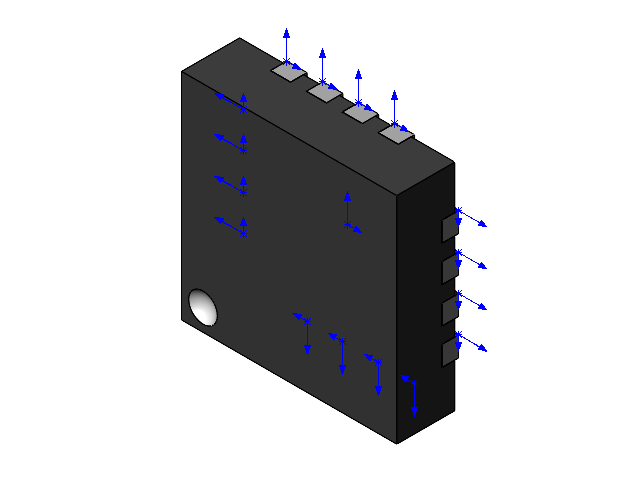
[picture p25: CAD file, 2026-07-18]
hardwave/ROBOCON_T9_V1/esp32-s3-wroom-1-1.snapshot.2/QFN-16 (3x3).SLDASM
QFN-16 (3x3) Part1.stp
QFN-16 (3x3) Part2.stp x 16
eBom-FreeParts.stp

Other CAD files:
hardwave/ROBOCON_T9_V1/esp32-s3-wroom-1-1.snapshot.2/USB-C.SLDASM
hardwave/ROBOCON_T9_V1/esp32-s3-wroom-1-1.snapshot.2/Кнопка.SLDASM
cad/demo đế v2/ĐẾ TRƯỚC 2D.dxf
cad/MÔ HÌNH.step
cad/KHOA_CHUONG_HEO/11.step
cad/KHOA_CHUONG_HEO/Part3.SLDPRT
cad/TẤM ĐẾ PHAY 2.step
cad/TẤM ĐẾ PHAY.step
cad/backup v5.step
cad/demo đế v2 (1)/CẢ KHUNG ĐẾ.step
cad/demo đế v2 (1)/TẤM NHỎ.step
cad/demo đế v2 (1)/ĐẾ TRƯỚC 2D.dxf
cad/demo đế v2 (1)/ĐẾ TRƯỚC.step
cad/demo đế v2 (1)/đế sau .step
cad/demo đế v2 (1)/đế sau 2D.dxf
cad/demo đế v2/CẢ KHUNG ĐẾ.step
cad/demo đế v2/ĐẾ TRƯỚC.step
cad/demo đế v2/đế sau .step
cad/demo đế v2/đế sau 2D.dxf
cad/demo đế/full 2 tấm.dxf
cad/demo đế/full 2 tấm.step
cad/demo đế/tấm sau .dxf
cad/demo đế/tấm trước.dxf
cad/demo đế/đế sau.step
cad/demo đế/đế trước.step
hardwave/MP1584/d-sun-dc-dc-step-down-voltage-regulator-simple-version-1.snapshot.4/D-SUN_dcdc_step_down_SIMPLE.FCStd
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

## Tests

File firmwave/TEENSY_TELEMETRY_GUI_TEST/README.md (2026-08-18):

# Teensy 4.1 — Telemetry GUI Test

Chương trình độc lập để kiểm tra truyền/nhận giữa dashboard ROBOCON Control Lab,
hai module radio telemetry kiểu SiK/3DR và Teensy 4.1. Chương trình không điều
khiển motor thật; nó mô phỏng RPM, yaw, line error và pin để kiểm tra giao diện
an toàn trên bàn.

## Đấu dây

| Telemetry phía robot | Teensy 4.1 |
|---|---|
| TX | RX8, chân 34 |
| RX | TX8, chân 35 |
| GND | GND |

Không cấp tín hiệu UART 5 V vào Teensy 4.1. Hai radio và Teensy dùng baud
`57600`, định dạng `8N1`.

## Nạp bằng PlatformIO

Mở thư mục `TEENSY_TELEMETRY_GUI_TEST`, cắm Teensy bằng USB rồi chạy:

```powershell
platformio run --target upload
```

USB Serial Monitor dùng `115200` baud và chỉ in lệnh nhận được để debug. Radio
telemetry dùng `Serial8` ở `57600` baud.

## Kiểm tra với dashboard

1. Cắm telemetry mặt đất vào PC.
2. Mở dashboard bằng Chrome hoặc Edge.
3. Chọn `57 600 baud` và nhấn **KẾT NỐI RADIO**.
4. Chọn đúng cổng COM của telemetry.
5. Chờ `TELEMETRY ONLINE` và `CONFIG SYNCED`.
6. Thử thay PID riêng cho FL/FR/BL/BR, gửi góc heading hoặc lệnh chạy.
7. Mở USB Serial Monitor để xem Teensy in các dòng `RX: ...`.

Dashboard sẽ tự gửi `PING`, `GET_CONFIG` và `HEARTBEAT`. Teensy trả dữ liệu
`TEL` ở 20 Hz. Nút **WRITE TO ROBOT** lưu PID vào EEPROM; rút nguồn, cắm lại và
kết nối lại để kiểm tra cấu hình vẫn được đồng bộ lên giao diện.

Sau khi nhấn E-STOP, gửi `RUN` hoặc `CLEAR_ESTOP` từ terminal UART, hoặc reset
Teensy để chạy lại phần mô phỏng.

## Lệnh hỗ trợ

```text
PING
HEARTBEAT
GET_CONFIG
PID,WHEEL,FL,0.82,0.031,0.012
PID,HEADING,0,3.2,0.018,0.24
PID,LINE,0,1.45,0.012,0.18
YAW,90
DRIVE,FORWARD,1200
DRIVE,0.5,0.0,0.0
ESTOP
RUN
SAVE_CONFIG
FACTORY_RESET
```

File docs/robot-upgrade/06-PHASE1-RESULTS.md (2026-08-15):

# Kết quả Phase 1A

Ngày kiểm tra: 2026-08-08.

## Đã triển khai

- Audit code hiện hành, không phục hồi cây firmware cũ đã bị xóa.
- Kiến trúc module, data model và kế hoạch migration 10 phase.
- Lõi RBT/2 binary:
  - header 16 byte;
  - CRC16-CCITT-FALSE;
  - sequence/timestamp;
  - parser resync sau noise;
  - giới hạn payload 1024 byte;
  - diagnostics counters.
- RBT/1 compatibility handshake dùng được ngay:
  - `PING` -> firmware/config version;
  - `GET_CONFIG` -> PID 4 bánh, heading, line, yaw target;
  - `HEARTBEAT` 10 Hz;
  - GUI báo mất link sau 500 ms;
  - GUI không cho gửi PID trước khi nhận `CFG_END`.

## Kết quả test

| Test | Kết quả |
|---|---|
| Native RBT/2 encode/decode | PASS |
| Packet bị chia nhỏ | PASS |
| Packet dính liền | PASS |
| Noise trước magic | PASS |
| CRC corruption + recovery | PASS |
| CRC vector `123456789` = `0x29B1` | PASS |
| Teensy 4.1 PlatformIO release build | PASS |
| Dashboard production build | PASS |

Firmware build sử dụng 72,352 byte code; còn dư lớn trên Teensy 4.1.

## Chưa được tuyên bố hoàn thành

- RBT/2 chưa thay RBT/1 trên robot thật; cần bench test telemetry radio trước.
- Config mới đồng bộ RAM, chưa lưu EEPROM/Flash (thuộc Phase 8).
- Chưa test motor/sensor vật lý; tuyệt đối kê bánh khi commissioning.
- Dashboard mở rộng đầy đủ các tab thuộc các phase sau.

## Gate trước Phase 2

1. Nạp firmware lên Teensy và xác nhận `PING/GET_CONFIG/HEARTBEAT` qua radio.
2. Rút/cắm lại telemetry và xác nhận GUI đọc đúng PID RAM hiện tại.
3. Xác nhận pin, chiều motor/encoder và CPR.
4. Chốt việc dùng tên `RL/RR` hay `BL/BR` trên toàn hệ thống.

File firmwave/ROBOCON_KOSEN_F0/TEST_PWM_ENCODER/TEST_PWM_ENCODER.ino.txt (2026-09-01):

#include <Arduino.h>

/* =========================================================
   1. KHAI BÁO CHÂN ENCODER
   Thay PIN_HERE bằng chân thực tế
   ========================================================= */

// Front Left
#define ENC_FL_A 0
#define ENC_FL_B 1

// Front Right
#define ENC_FR_A 6
#define ENC_FR_B 7

// Rear Left
#define ENC_RL_A 2
#define ENC_RL_B 3

// Rear Right
#define ENC_RR_A 4
#define ENC_RR_B 5

/* =========================================================
   2. KHAI BÁO CHÂN BTS7960
   Mỗi động cơ sử dụng RPWM và LPWM
   ========================================================= */

// Front Left
#define FL_RPWM 36
#define FL_LPWM 37

// Front Right
#define FR_RPWM 22
#define FR_LPWM 23

// Rear Left
#define RL_RPWM 14
#define RL_LPWM 15

// Rear Right
#define RR_RPWM 18
#define RR_LPWM 19

/* =========================================================
   3. CẤU HÌNH
   ========================================================= */

#define PWM_MAX       255
#define TEST_PWM      120
#define PRINT_TIME_MS 100

// Đổi thành -1 nếu động cơ quay ngược chiều mong muốn
#define MOTOR_FL_DIRECTION  1
#define MOTOR_FR_DIRECTION  -1
#define MOTOR_RL_DIRECTION  -1
#define MOTOR_RR_DIRECTION  1

// Đổi thành -1 nếu encoder đếm ngược chiều
#define ENCODER_FL_DIRECTION  1
#define ENCODER_FR_DIRECTION  -1
#define ENCODER_RL_DIRECTION  -1
#define ENCODER_RR_DIRECTION  -1

/* =========================================================
   4. BIẾN ENCODER
   ========================================================= */

volatile int32_t encoderFL = 0;
volatile int32_t encoderFR = 0;
volatile int32_t encoderRL = 0;
volatile int32_t encoderRR = 0;

volatile uint8_t lastStateFL = 0;
volatile uint8_t lastStateFR = 0;
volatile uint8_t lastStateRL = 0;
volatile uint8_t lastStateRR = 0;

/*
   Bảng giải mã Quadrature X4
*/
const int8_t QUADRATURE_TABLE[16] = {
   0, -1,  1,  0,
   1,  0,  0, -1,
  -1,  0,  0,  1,
   0,  1, -1,  0
};

/* =========================================================
   5. ĐỌC TRẠNG THÁI ENCODER
   ========================================================= */

inline uint8_t readEncoderState(uint8_t pinA, uint8_t pinB) {
  uint8_t stateA = digitalReadFast(pinA);
  uint8_t stateB = digitalReadFast(pinB);

  return (stateA << 1) | stateB;
}

/* =========================================================
   6. INTERRUPT ENCODER
   ========================================================= */

void updateEncoderFL() {
  uint8_t currentState =
      readEncoderState(ENC_FL_A, ENC_FL_B);

  uint8_t transition =
      (lastStateFL << 2) | currentState;

  encoderFL +=
      QUADRATURE_TABLE[transition] *
      ENCODER_FL_DIRECTION;

  lastStateFL = currentState;
}

void updateEncoderFR() {
  uint8_t currentState =
      readEncoderState(ENC_FR_A, ENC_FR_B);

  uint8_t transition =
      (lastStateFR << 2) | currentState;

  encoderFR +=
      QUADRATURE_TABLE[transition] *
      ENCODER_FR_DIRECTION;

  lastStateFR = currentState;
}

void updateEncoderRL() {
  uint8_t currentState =
      readEncoderState(ENC_RL_A, ENC_RL_B);

  uint8_t transition =
      (lastStateRL << 2) | currentState;

  encoderRL +=
      QUADRATURE_TABLE[transition] *
      ENCODER_RL_DIRECTION;

  lastStateRL = currentState;
}

void updateEncoderRR() {
  uint8_t currentState =
      readEncoderState(ENC_RR_A, ENC_RR_B);

  uint8_t transition =
      (lastStateRR << 2) | currentState;

  encoderRR +=
      QUADRATURE_TABLE[transition] *
      ENCODER_RR_DIRECTION;

  lastStateRR = currentState;
}

/* =========================================================
   7. ĐIỀU KHIỂN MỘT BTS7960
   pwm: -255 đến +255

   pwm > 0: quay thuận
   pwm < 0: quay nghịch
   pwm = 0: dừng
   ========================================================= */

void setBTS7960(
    uint8_t pinRPWM,
    uint8_t pinLPWM,
    int16_t pwm) {

  pwm = constrain(pwm, -PWM_MAX, PWM_MAX);

  if (pwm > 0) {
    // Quay thuận
    analogWrite(pinRPWM, pwm);
    analogWrite(pinLPWM, 0);
  }
  else if (pwm < 0) {
    // Quay nghịch
    analogWrite(pinRPWM, 0);
    analogWrite(pinLPWM, -pwm);
  }
  else {
    // Dừng thả động cơ
    analogWrite(pinRPWM, 0);
    analogWrite(pinLPWM, 0);
  }
}

/* =========================================================
   8. HÀM ĐIỀU KHIỂN TỪNG ĐỘNG CƠ
   ========================================================= */

void setMotorFL(int16_t pwm) {
  setBTS7960(
      FL_RPWM,
      FL_LPWM,
      pwm * MOTOR_FL_DIRECTION);
}

void setMotorFR(int16_t pwm) {
  setBTS7960(
      FR_RPWM,
      FR_LPWM,
      pwm * MOTOR_FR_DIRECTION);
}

void setMotorRL(int16_t pwm) {
  setBTS7960(
      RL_RPWM,
      RL_LPWM,
      pwm * MOTOR_RL_DIRECTION);
}

void setMotorRR(int16_t pwm) {
  setBTS7960(
      RR_RPWM,
      RR_LPWM,
      pwm * MOTOR_RR_DIRECTION);
}

/* =========================================================
   9. ĐIỀU KHIỂN ĐỒNG THỜI 4 ĐỘNG CƠ
   ========================================================= */

void setMotors(
    int16_t pwmFL,
    int16_t pwmFR,
    int16_t pwmRL,
    int16_t pwmRR) {

  setMotorFL(pwmFL);
  setMotorFR(pwmFR);
  setMotorRL(pwmRL);
  setMotorRR(pwmRR);
}

void stopMotors() {
  setMotors(0, 0, 0, 0);
}

/* =========================================================
   10. RESET ENCODER
   ========================================================= */

void resetEncoders() {
  noInterrupts();

  encoderFL = 0;
  encoderFR = 0;
  encoderRL = 0;
  encoderRR = 0;

  interrupts();
}

/* =========================================================
   11. IN GIÁ TRỊ ENCODER
   ========================================================= */

void printEncoders() {
  int32_t countFL;
  int32_t countFR;
  int32_t countRL;
  int32_t countRR;

  noInterrupts();

  countFL = encoderFL;
  countFR = encoderFR;
  countRL = encoderRL;
  countRR = encoderRR;

  interrupts();

  Serial.print("FL: ");
  Serial.print(countFL);

  Serial.print("\tFR: ");
  Serial.print(countFR);

  Serial.print("\tRL: ");
  Serial.print(countRL);

  Serial.print("\tRR: ");
  Serial.println(countRR);
}

/* =========================================================
   12. XỬ LÝ LỆNH SERIAL
   ========================================================= */

void processSerialCommand(char command) {
  switch (command) {
    case 'F':
    case 'f':
      // Cả 4 động cơ quay thuận
      setMotors(
          TEST_PWM,
          TEST_PWM,
          TEST_PWM,
          TEST_PWM);

      Serial.println("4 dong co quay THUAN");
      break;

    case 'B':
    case 'b':
      // Cả 4 động cơ quay nghịch1
      setMotors(
          -TEST_PWM,
          -TEST_PWM,
          -TEST_PWM,
          -TEST_PWM);

      Serial.println("4 dong co quay NGHICH");
      break;

    case 'S':
    case 's':
      stopMotors();
      Serial.println("DUNG 4 dong co");
      break;

    case 'R':
    case 'r':
      resetEncoders();
      Serial.println("Da reset encoder");
      break;

    case '1':
      stopMotors();
      setMotorFL(TEST_PWM);
      Serial.println("Test motor FL");
      break;

    case '2':
      stopMotors();
      setMotorFR(TEST_PWM);
      Serial.println("Test motor FR");
      break;

    case '3':
      stopMotors();
      setMotorRL(TEST_PWM);
      Serial.println("Test motor RL");
      break;

    case '4':
      stopMotors();
      setMotorRR(TEST_PWM);
      Serial.println("Test motor RR");
      break;

    case '0':
      stopMotors();
      Serial.println("Dung tat ca dong co");
      break;
  }
}

/* =========================================================
   13. SETUP
   ========================================================= */

void setup() {
  Serial.begin(115200);

  /* ---------- Encoder Input ---------- */

  pinMode(ENC_FL_A, INPUT_PULLUP);
  pinMode(ENC_FL_B, INPUT_PULLUP);

  pinMode(ENC_FR_A, INPUT_PULLUP);
  pinMode(ENC_FR_B, INPUT_PULLUP);

  pinMode(ENC_RL_A, INPUT_PULLUP);
  pinMode(ENC_RL_B, INPUT_PULLUP);

  pinMode(ENC_RR_A, INPUT_PULLUP);
  pinMode(ENC_RR_B, INPUT_PULLUP);

  /* ---------- BTS7960 Output ---------- */

  pinMode(FL_RPWM, OUTPUT);
  pinMode(FL_LPWM, OUTPUT);

  pinMode(FR_RPWM, OUTPUT);
  pinMode(FR_LPWM, OUTPUT);

  pinMode(RL_RPWM, OUTPUT);
  pinMode(RL_LPWM, OUTPUT);

  pinMode(RR_RPWM, OUTPUT);
  pinMode(RR_LPWM, OUTPUT);

  // PWM 8 bit: 0–255
  analogWriteResolution(8);

  // Tần số PWM 20 kHz
  analogWriteFrequency(FL_RPWM, 20000);
  analogWriteFrequency(FL_LPWM, 20000);

  analogWriteFrequency(FR_RPWM, 20000);
  analogWriteFrequency(FR_LPWM, 20000);

  analogWriteFrequency(RL_RPWM, 20000);
  analogWriteFrequency(RL_LPWM, 20000);

  analogWriteFrequency(RR_RPWM, 20000);
  analogWriteFrequency(RR_LPWM, 20000);

  stopMotors();

  /* ---------- Trạng thái encoder ban đầu ---------- */

  lastStateFL =
      readEncoderState(ENC_FL_A, ENC_FL_B);

  lastStateFR =
      readEncoderState(ENC_FR_A, ENC_FR_B);

  lastStateRL =
      readEncoderState(ENC_RL_A, ENC_RL_B);

  lastStateRR =
      readEncoderState(ENC_RR_A, ENC_RR_B);

  /* ---------- Cài đặt ngắt encoder X4 ---------- */

  attachInterrupt(
      digitalPinToInterrupt(ENC_FL_A),
      updateEncoderFL,
      CHANGE);

  attachInterrupt(
      digitalPinToInterrupt(ENC_FL_B),
      updateEncoderFL,
      CHANGE);

  attachInterrupt(
      digitalPinToInterrupt(ENC_FR_A),
      updateEncoderFR,
      CHANGE);

  attachInterrupt(
      digitalPinToInterrupt(ENC_FR_B),
      updateEncoderFR,
      CHANGE);

  attachInterrupt(
      digitalPinToInterrupt(ENC_RL_A),
      updateEncoderRL,
      CHANGE);

  attachInterrupt(
      digitalPinToInterrupt(ENC_RL_B),
      updateEncoderRL,
      CHANGE);

  attachInterrupt(
      digitalPinToInterrupt(ENC_RR_A),
      updateEncoderRR,
      CHANGE);

  attachInterrupt(
      digitalPinToInterrupt(ENC_RR_B),
      updateEncoderRR,
      CHANGE);

  resetEncoders();

  Serial.println("================================");
  Serial.println("TEENSY 4.1 - 4 MOTOR + ENCODER");
  Serial.println("F: quay thuan");
  Serial.println("B: quay nghich");
  Serial.println("S: dung");
  Serial.println("R: reset encoder");
  Serial.println("1: test FL");
  Serial.println("2: test FR");
  Serial.println("3: test RL");
  Serial.println("4: test RR");
  Serial.println("0: dung tat ca");
  Serial.println("================================");
}

/* =========================================================
   14. LOOP
   ========================================================= */

void loop() {
  static uint32_t lastPrintTime = 0;

  if (Serial.available()) {
    char command = Serial.read();
    processSerialCommand(command);
  }

  if (millis() - lastPrintTime >= PRINT_TIME_MS) {
    lastPrintTime = millis();
    printEncoders();
  }
}

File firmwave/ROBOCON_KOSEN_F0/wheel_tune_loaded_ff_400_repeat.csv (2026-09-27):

host_s | segment | direction | command_mm_s | record | wheel | target_rpm | actual_rpm | pwm | encoder | yaw_deg | yaw_target_deg | yaw_error_deg
1.5160000000032596 | -1 | IDLE | 0 | WHEEL | FL | 0.00 | 0.00 | 0 | 264
1.5160000000032596 | -1 | IDLE | 0 | WHEEL | FR | 0.00 | 0.00 | 0 | -340
1.5309999999881256 | -1 | IDLE | 0 | WHEEL | BL | 0.00 | 0.00 | 0 | -204
1.5309999999881256 | -1 | IDLE | 0 | WHEEL | BR | 0.00 | 0.00 | 0 | 269
1.5309999999881256 | -1 | IDLE | 0 | HDG |  |  |  |  |  | 2.54 | 2.36 | -0.18
1.5309999999881256 | -1 | IDLE | 0 | WHEEL | FL | 0.00 | 0.00 | 0 | 264
1.5309999999881256 | -1 | IDLE | 0 | WHEEL | FR | 0.00 | 0.00 | 0 | -340
1.5309999999881256 | -1 | IDLE | 0 | WHEEL | BL | 0.00 | 0.00 | 0 | -204
1.5309999999881256 | -1 | IDLE | 0 | WHEEL | BR | 0.00 | 0.00 | 0 | 269
1.5309999999881256 | -1 | IDLE | 0 | HDG |  |  |  |  |  | 2.54 | 2.36 | -0.18
1.5469999999913853 | -1 | IDLE | 0 | WHEEL | FL | 0.00 | 0.00 | 0 | 264
1.5469999999913853 | -1 | IDLE | 0 | WHEEL | FR | 0.00 | 0.00 | 0 | -340
1.5469999999913853 | -1 | IDLE | 0 | WHEEL | BL | 0.00 | 0.00 | 0 | -204
1.5469999999913853 | -1 | IDLE | 0 | WHEEL | BR | 0.00 | 0.00 | 0 | 269
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

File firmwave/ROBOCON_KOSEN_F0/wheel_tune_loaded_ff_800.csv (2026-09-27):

host_s | segment | direction | command_mm_s | record | wheel | target_rpm | actual_rpm | pwm | encoder | yaw_deg | yaw_target_deg | yaw_error_deg
1.5160000000032596 | -1 | IDLE | 0 | WHEEL | FL | 0.00 | 0.00 | 0 | 448
1.5160000000032596 | -1 | IDLE | 0 | WHEEL | FR | 0.00 | 0.00 | 0 | -729
1.5160000000032596 | -1 | IDLE | 0 | WHEEL | BL | 0.00 | 0.00 | 0 | -373
1.5160000000032596 | -1 | IDLE | 0 | WHEEL | BR | 0.00 | 0.00 | 0 | 546
1.5310000000172295 | -1 | IDLE | 0 | HDG |  |  |  |  |  | 7.12 | 7.11 | -0.01
1.5310000000172295 | -1 | IDLE | 0 | WHEEL | FL | 0.00 | 0.00 | 0 | 448
1.5310000000172295 | -1 | IDLE | 0 | WHEEL | FR | 0.00 | 0.00 | 0 | -729
1.5310000000172295 | -1 | IDLE | 0 | WHEEL | BL | 0.00 | 0.00 | 0 | -373
1.5310000000172295 | -1 | IDLE | 0 | WHEEL | BR | 0.00 | 0.00 | 0 | 546
1.5310000000172295 | -1 | IDLE | 0 | HDG |  |  |  |  |  | 7.12 | 7.11 | -0.01
1.5469999999913853 | -1 | IDLE | 0 | WHEEL | FL | 0.00 | 0.00 | 0 | 448
1.5469999999913853 | -1 | IDLE | 0 | WHEEL | FR | 0.00 | 0.00 | 0 | -729
1.5469999999913853 | -1 | IDLE | 0 | WHEEL | BL | 0.00 | 0.00 | 0 | -373
1.5469999999913853 | -1 | IDLE | 0 | WHEEL | BR | 0.00 | 0.00 | 0 | 546
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

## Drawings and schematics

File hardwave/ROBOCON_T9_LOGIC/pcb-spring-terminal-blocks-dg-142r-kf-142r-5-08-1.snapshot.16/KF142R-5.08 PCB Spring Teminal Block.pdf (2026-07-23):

# 慈溪市科发电子有限公司

CIXI KEFA ELECTRONICS CO.,LTD.

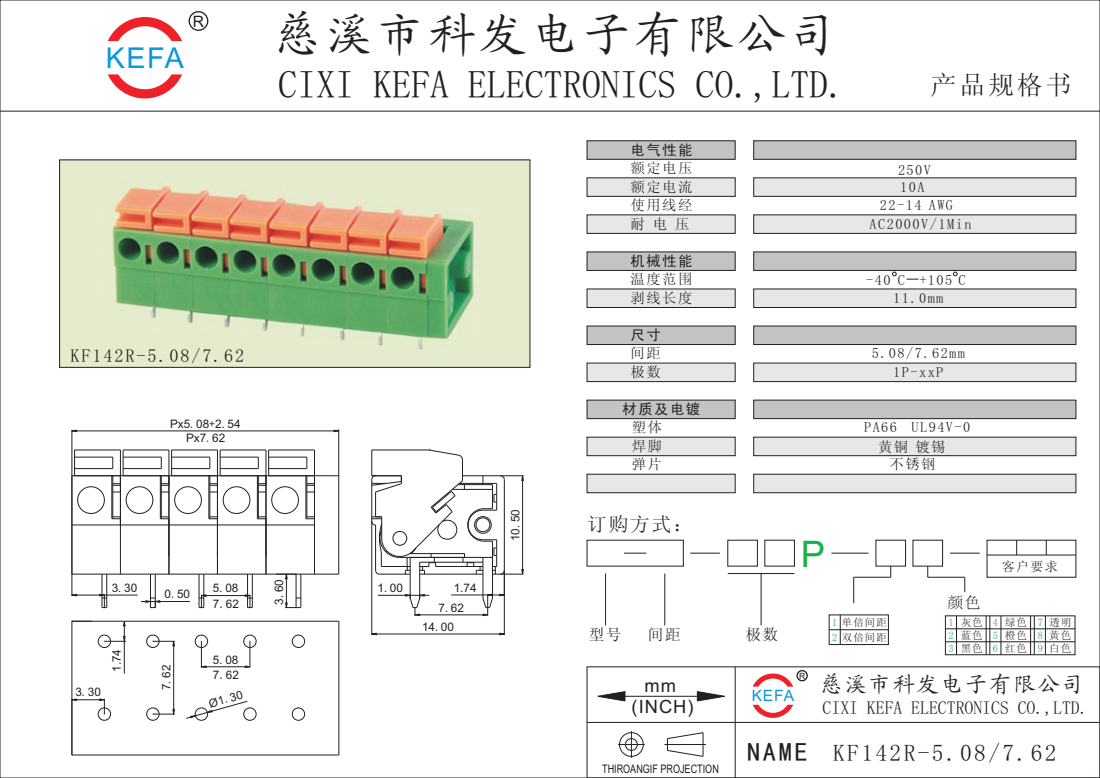
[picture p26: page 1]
电气性能; mm (INCH); THIROANGIF PROJECTION; 产品规格书; 额定电压 额定电流 使用线经 耐 电 压; 机械性能 温度范围 剥线长度; 材质及电镀 塑体 焊脚 弹片; KEFA; 250V 10A 22-14 AWG AC2000V/1Min; 5.08/7.62mm 1P-xxP; PA66 UL94V-0 黄铜 镀锡 不锈钢; 客户要求; 订购方式：

单倍间距
双倍间距
慈溪市科发电子有限公司
CIXI KEFA ELECTRONICS CO.,LTD.
NAME

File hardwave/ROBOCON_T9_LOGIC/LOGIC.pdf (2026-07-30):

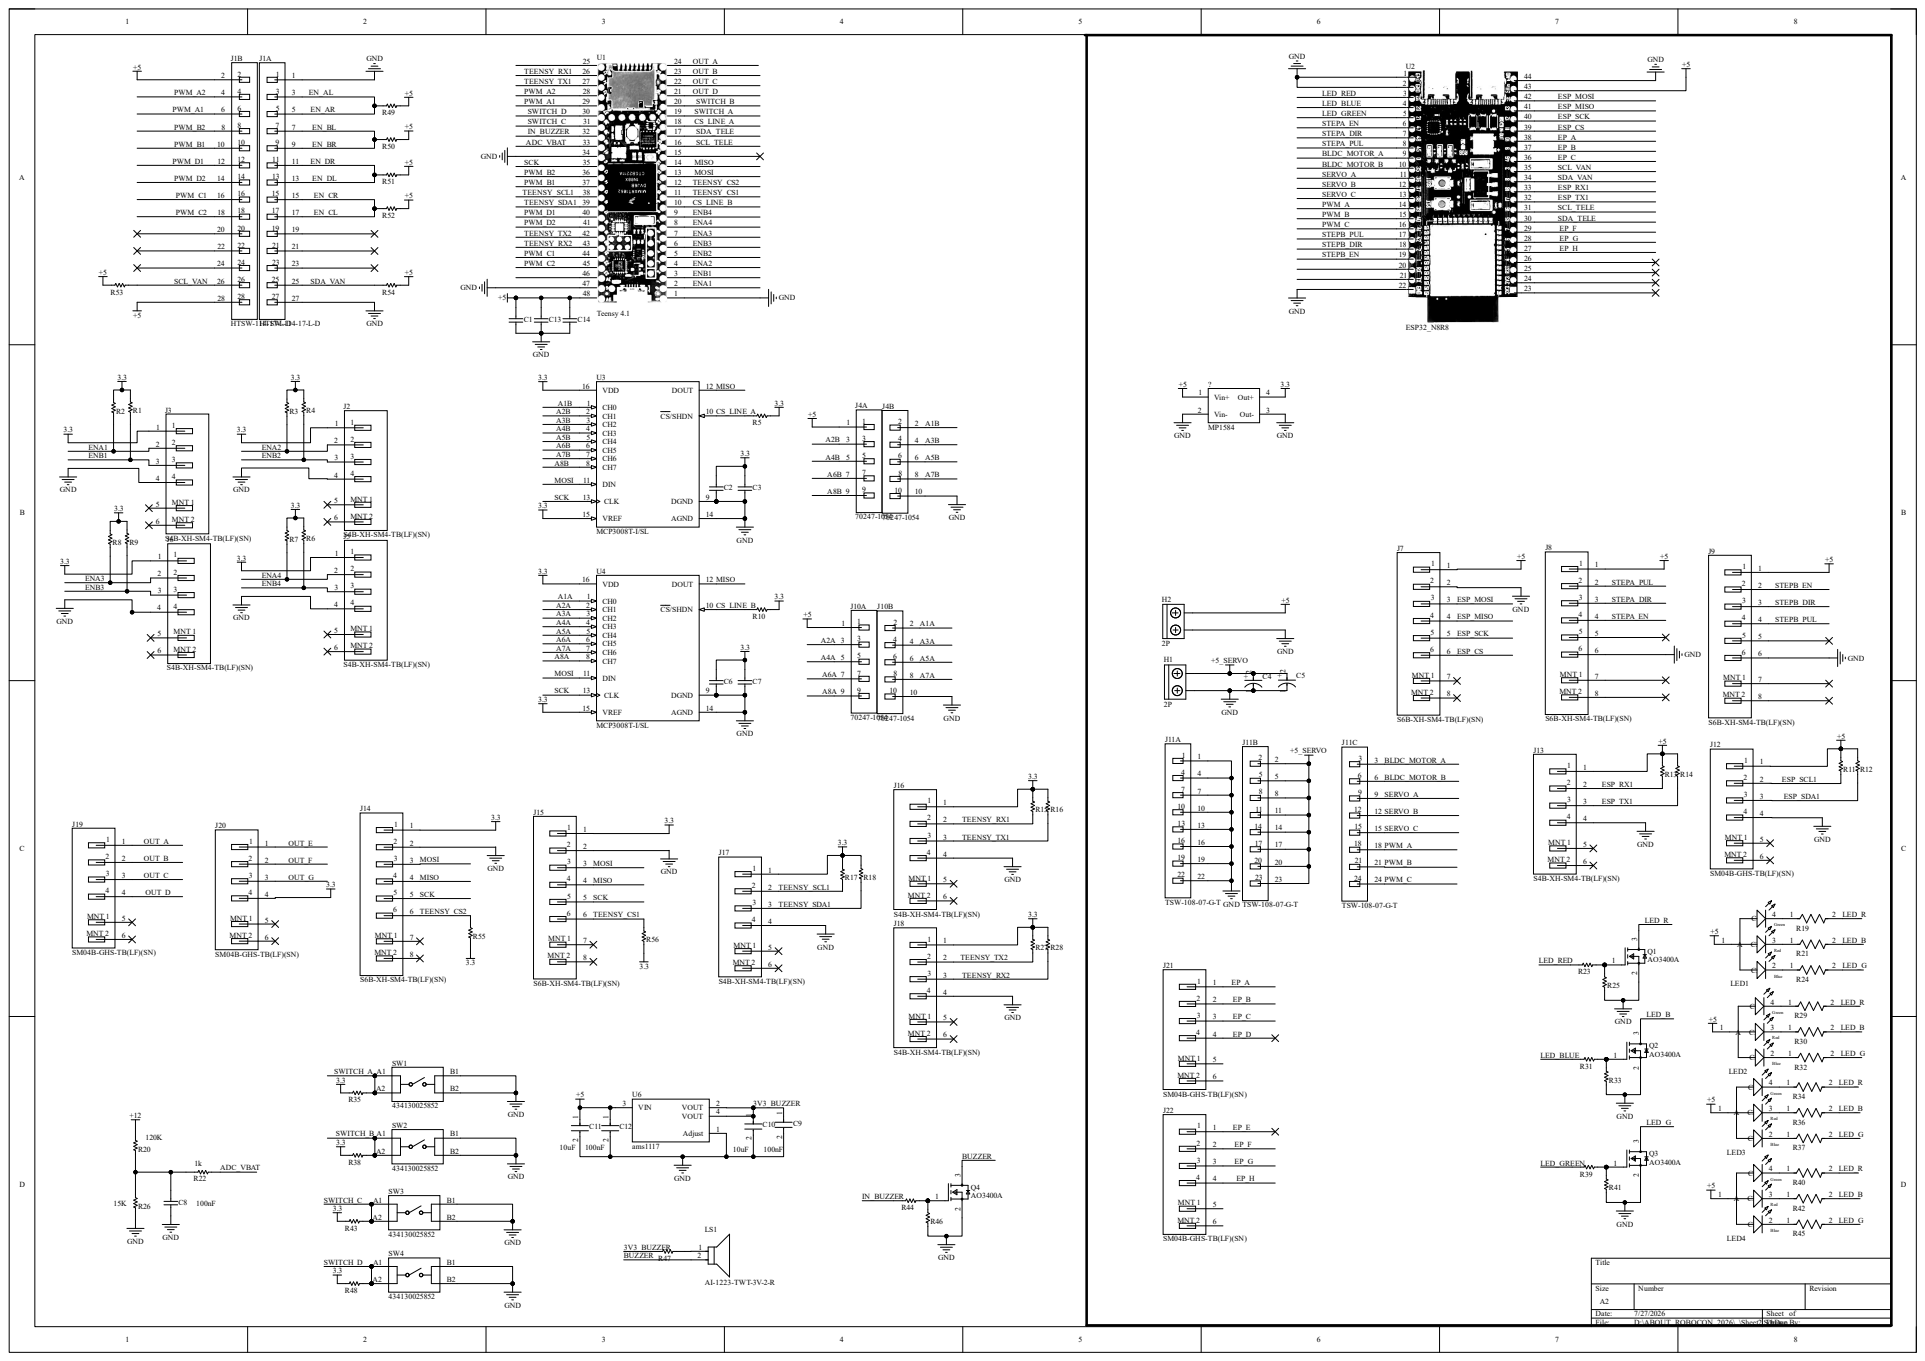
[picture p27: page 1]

SM04B-GHS-TB(LF)(SN)

Size A2 | Number | Revision

Date: 7/27/2026 | Sheet of
File: D:\ABOUT_ROBOCON_2026\..\Sheet2.SchDoc Drawn By:

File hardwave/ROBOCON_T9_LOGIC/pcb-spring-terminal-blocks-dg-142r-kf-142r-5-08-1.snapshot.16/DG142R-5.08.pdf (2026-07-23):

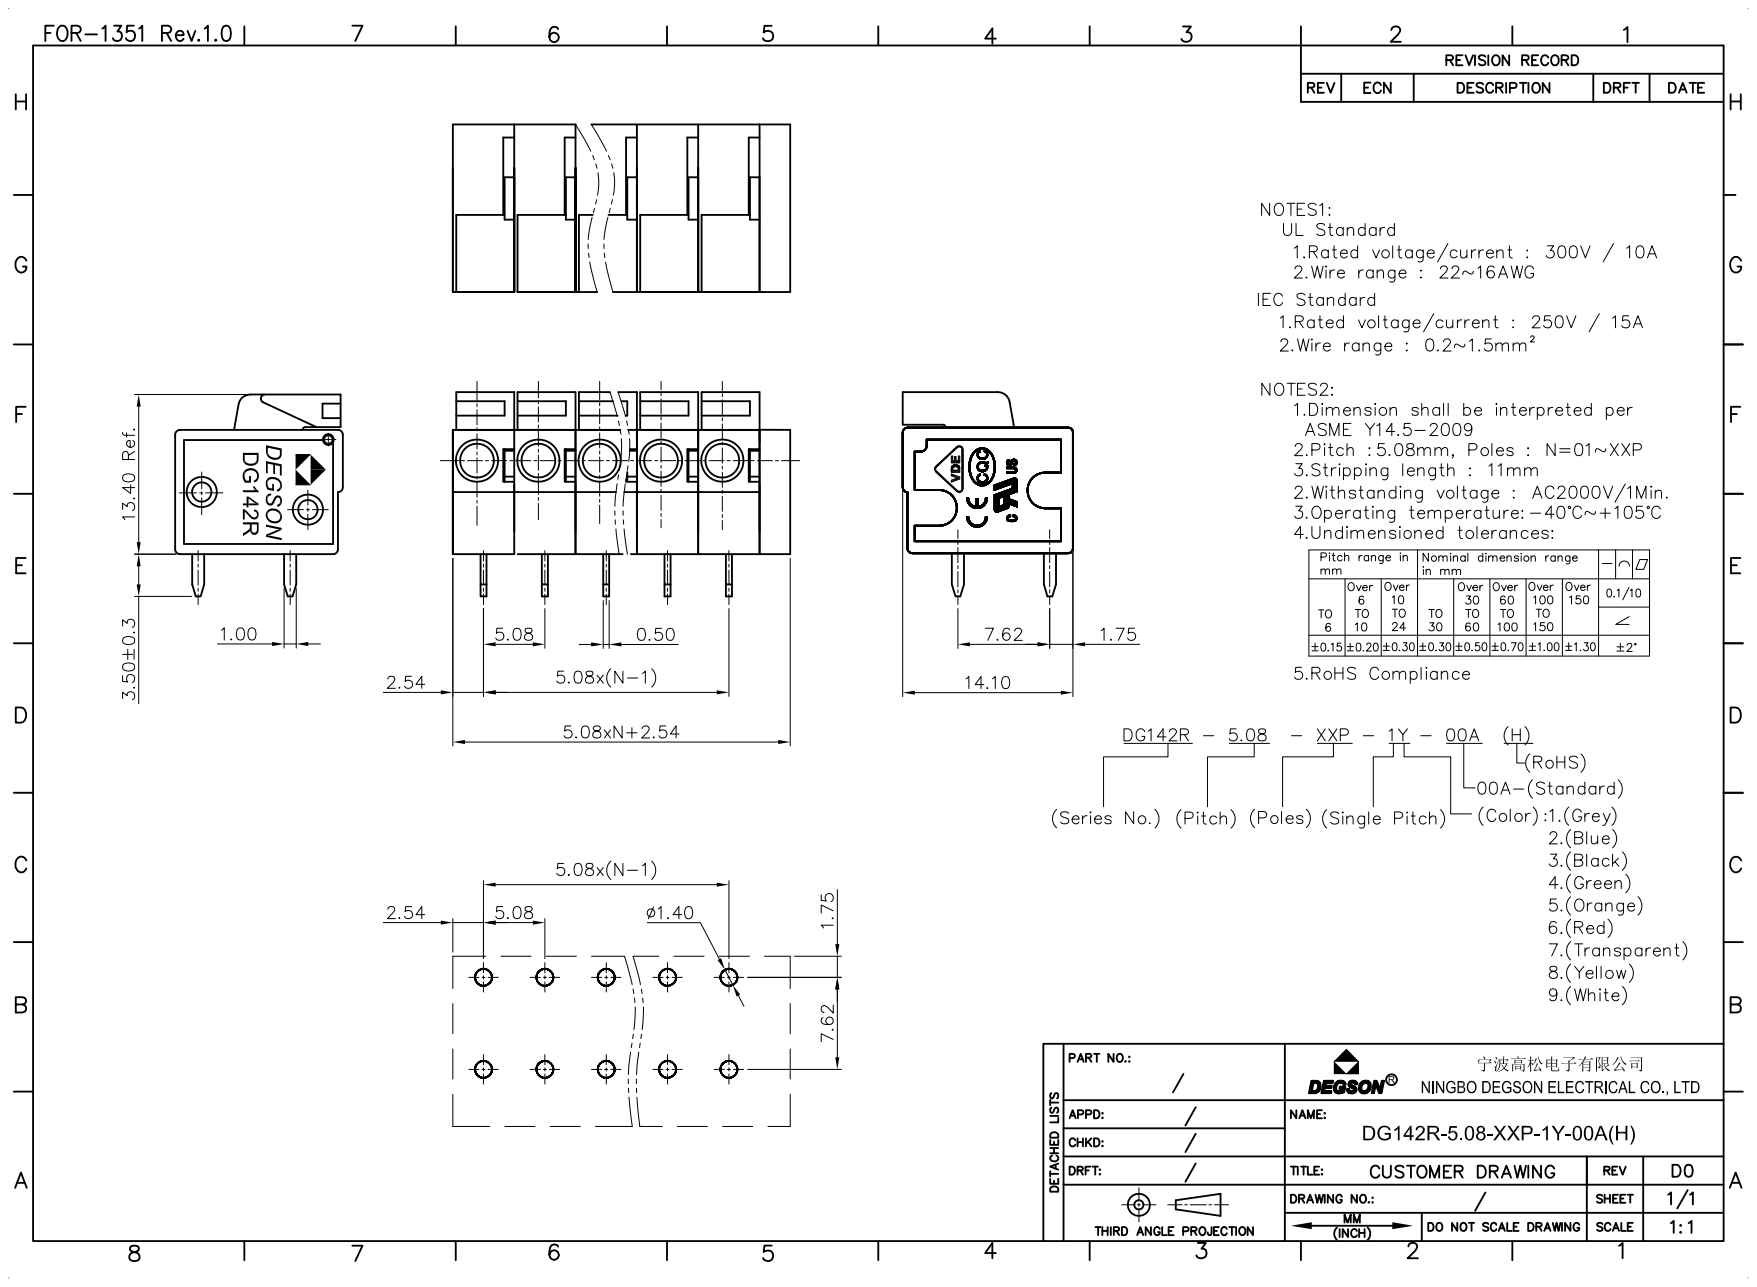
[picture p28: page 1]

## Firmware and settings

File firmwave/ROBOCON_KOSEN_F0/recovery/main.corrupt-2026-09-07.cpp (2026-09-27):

#include <Arduino.h>
#include <Encoder.h>
#include <SPI.h>
#include <Wire.h>
#include <Adafruit_BNO08x.h>
#include <PWFusion_VL53L3C.h>
#include <math.h>
#include <stddef.h>
#include <stdio.h>
#include <string.h>
#include "RobotConfig.h"
using namespace RobotConfig;

// Route the existing RBT/1 command parser and telemetry prints to Serial5.
// USB Serial (COM14) is intentionally not the control link in this build.
#define Serial TELEMETRY_UART

// ============================================================
// Types, faults and shared state
// ============================================================

enum FaultCode : uint32_t {
  FAULT_NONE          = 0,
  FAULT_IMU_TIMEOUT   = 1UL << 0,
  FAULT_FLOW_TIMEOUT  = 1UL << 1,
  FAULT_LINE_LOST     = 1UL << 2,
  FAULT_TOF_TIMEOUT   = 1UL << 3,
  FAULT_ENCODER       = 1UL << 4,
  FAULT_ESP_TIMEOUT   = 1UL << 5,
  FAULT_STATE_TIMEOUT = 1UL << 6,
  FAULT_CONFIG        = 1UL << 7
};

enum LineState : uint8_t {
  LINE_VALID,
  LINE_LOST_LEFT,
  LINE_LOST_RIGHT,
  LINE_LOST_UNKNOWN,
  CROSS_LINE
};

enum AutoState : uint8_t {
  WAIT_START,
  CAN_START,
  CAN_START_FAST,
  CAN_START_FINE,
  DI_SANG_TRAI_A,
  BU_TAM_A,
  CAN_YAW_A,
  CAN_A,
  DOI_GAP_A,
  DI_SANG_TRAI_B,
  BU_TAM_B,
  CAN_YAW_B,
  CAN_B,
  DOI_GAP_B,
  DI_SANG_C,
  BU_TAM_C,
  CAN_YAW_C,
  CHAY_LEN_XANH,
  CAN_GIUA_LINE_C,
  DI_LEN_DEM_LINE,
  HOME_CENTER,
  HOME_DROP,
  HOME_TO_B,
  TIEN_34CM_B,
  DOI_THA_2B,
  CHO_SAU_B,
  LUI_33CM_A,
  DOI_THA_2A,
  CHO_SAU_THA_A,
  LUI_3M,
  SANG_TRAI_1M5,
  FINISH,
  FAULT_STOP
};

struct RobotPose {
  float x_mm = 0;
  float y_mm = 0;
  float yaw_deg = 0;
};

struct OpticalFlowData {
  float deltaX = 0;
  float deltaY = 0;
  float velocityX = 0;
  float velocityY = 0;
  float quality = 0;
  float groundDistance = 0;
  bool valid = false;
  bool fresh = false;
  uint32_t lastUpdateMs = 0;
};

struct LineArrayData {
  uint16_t raw[8] = {};
  float filtered[8] = {};
  uint16_t normalized[8] = {};
  float position = 0;
  float lastPosition = 0;
  uint8_t activeCount = 0;
  bool valid = false;
  bool cross = false;
  LineState state = LINE_LOST_UNKNOWN;
  uint32_t lastValidMs = 0;
};

struct StopArrayData {
struct StopArrayData {
struct StopArrayData {
  uint16_t raw[6] = {};
  float filtered[6] = {};
  uint16_t normalized[6] = {};
  float leftPosition = 0;
  float rightPosition = 0;
  bool leftValid = false;
  bool rightValid = false;
  uint16_t holdRaw[2] = {};
  float holdFiltered[2] = {};
  uint16_t holdNormalized[2] = {};
};
  bool rightValid = false;
  uint16_t holdRaw[2] = {};
  float holdFiltered[2] = {};
  uint16_t holdNormalized[2] = {};
};
  bool rightValid = false;
  uint16_t holdRaw[2] = {};
  float holdFiltered[2] = {};
  uint16_t holdNormalized[2] = {};
};

class PID {
 public:
  float kp = 0, ki = 0, kd = 0;
  float integral = 0, previousError = 0;
  float integralLimit = 0;

  PID() = default;
  PID(float p, float i, float d, float limit)
      : kp(p), ki(i), kd(d), integralLimit(limit) {}

  void reset() { integral = 0; previousError = 0; }

  float updateError(float error, float dt, float low, float high) {
    if (dt <= 0 || !isfinite(error)) return 0;
    const float derivative = (error - previousError) / dt;
    const float candidateIntegral = constrain(integral + error * dt,
                                               -integralLimit, integralLimit);
    const float candidate = kp * error + ki * candidateIntegral + kd * derivative;
    const bool saturatingHigh = candidate > high && error > 0;
    const bool saturatingLow = candidate < low && error < 0;
    if (!saturatingHigh && !saturatingLow) integral = candidateIntegral;
    previousError = error;
    return constrain(kp * error + ki * integral + kd * derivative, low, high);
  }
};

enum WheelId : uint8_t { FL, FR, RL, RR, WHEEL_COUNT };

struct WheelControl {
  Encoder *encoder;
  uint8_t rpwm, lpwm;
  int8_t motorSign, encoderSign;
  long count = 0;
  long previousCount = 0;
  float deltaMm = 0;
  float targetMmS = 0;
  float measuredMmS = 0;
  int pwm = 0;
  float kff = 0;
  int deadzone = 0;
  PID pid;
  uint32_t lastEncoderMotionMs = 0;
};

Encoder encFL(FL_ENC_A, FL_ENC_B);
Encoder encFR(FR_ENC_A, FR_ENC_B);
Encoder encRL(RL_ENC_A, RL_ENC_B);
Encoder encRR(RR_ENC_A, RR_ENC_B);

WheelControl wheels[WHEEL_COUNT] = {
  {&encFL, FL_RPWM, FL_LPWM, MOTOR_SIGN_FL, ENCODER_SIGN_FL},
  {&encFR, FR_RPWM, FR_LPWM, MOTOR_SIGN_FR, ENCODER_SIGN_FR},
  {&encRL, RL_RPWM, RL_LPWM, MOTOR_SIGN_RL, ENCODER_SIGN_RL},
  {&encRR, RR_RPWM, RR_LPWM, MOTOR_SIGN_RR, ENCODER_SIGN_RR}
};

RobotPose pose;
OpticalFlowData flow;
LineArrayData centerLine;
StopArrayData stopLine;

Adafruit_BNO08x bno085(-1);
sh2_SensorValue_t bnoEvent;
VL53L3C tof;

PID headingPid(HEADING_KP, HEADING_KI, HEADING_KD, HEADING_INTEGRAL_LIMIT);
PID fineHeadingPid(FINE_HEADING_KP, 0.0f, FINE_HEADING_KD, 0.0f);
PID linePid(LINE_KP, LINE_KI, LINE_KD, 2500.0f);
PID positionXPid(POSITION_X_KP, POSITION_X_KI, POSITION_X_KD, POSITION_X_INTEGRAL_LIMIT);
PID positionYPid(POSITION_Y_KP, POSITION_Y_KI, POSITION_Y_KD, POSITION_Y_INTEGRAL_LIMIT);
PID stopForwardPid(STOP_FORWARD_KP, STOP_FORWARD_KI, STOP_FORWARD_KD, STOP_FORWARD_INTEGRAL_LIMIT);
PID stopYawPid(STOP_YAW_KP, STOP_YAW_KI, STOP_YAW_KD, STOP_YAW_INTEGRAL_LIMIT);
PID tofDistancePid(TOF_DISTANCE_KP, TOF_DISTANCE_KI, TOF_DISTANCE_KD, TOF_DISTANCE_INTEGRAL_LIMIT);
PID rightLinePid(RIGHT_LINE_KP, RIGHT_LINE_KI, RIGHT_LINE_KD, RIGHT_LINE_INTEGRAL_LIMIT);
PID leftLinePid(LEFT_LINE_KP, LEFT_LINE_KI, LEFT_LINE_KD, LEFT_LINE_INTEGRAL_LIMIT);
PID positionXPid(POSITION_X_KP, POSITION_X_KI, POSITION_X_KD, POSITION_X_INTEGRAL_LIMIT);
PID positionYPid(POSITION_Y_KP, POSITION_Y_KI, POSITION_Y_KD, POSITION_Y_INTEGRAL_LIMIT);
PID stopForwardPid(STOP_FORWARD_KP, STOP_FORWARD_KI, STOP_FORWARD_KD, STOP_FORWARD_INTEGRAL_LIMIT);
PID stopYawPid(STOP_YAW_KP, STOP_YAW_KI, STOP_YAW_KD, STOP_YAW_INTEGRAL_LIMIT);
PID tofDistancePid(TOF_DISTANCE_KP, TOF_DISTANCE_KI, TOF_DISTANCE_KD, TOF_DISTANCE_INTEGRAL_LIMIT);
PID rightLinePid(RIGHT_LINE_KP, RIGHT_LINE_KI, RIGHT_LINE_KD, RIGHT_LINE_INTEGRAL_LIMIT);
PID leftLinePid(LEFT_LINE_KP, LEFT_LINE_KI, LEFT_LINE_KD, LEFT_LINE_INTEGRAL_LIMIT);
PID positionXPid(POSITION_X_KP, POSITION_X_KI, POSITION_X_KD, POSITION_X_INTEGRAL_LIMIT);
PID positionYPid(POSITION_Y_KP, POSITION_Y_KI, POSITION_Y_KD, POSITION_Y_INTEGRAL_LIMIT);
PID stopForwardPid(STOP_FORWARD_KP, STOP_FORWARD_KI, STOP_FORWARD_KD, STOP_FORWARD_INTEGRAL_LIMIT);
PID stopYawPid(STOP_YAW_KP, STOP_YAW_KI, STOP_YAW_KD, STOP_YAW_INTEGRAL_LIMIT);
PID tofDistancePid(TOF_DISTANCE_KP, TOF_DISTANCE_KI, TOF_DISTANCE_KD, TOF_DISTANCE_INTEGRAL_LIMIT);
PID rightLinePid(RIGHT_LINE_KP, RIGHT_LINE_KI, RIGHT_LINE_KD, RIGHT_LINE_INTEGRAL_LIMIT);
PID leftLinePid(LEFT_LINE_KP, LEFT_LINE_KI, LEFT_LINE_KD, LEFT_LINE_INTEGRAL_LIMIT);

float maxWheelSpeedMmS = MAX_WHEEL_SPEED_MM_S;
float maxManualHeadingWzRadS = MAX_MANUAL_HEADING_WZ_RAD_S;
float maxAutoHeadLockWzRadS = MAX_AUTO_HEAD_LOCK_WZ_RAD_S;
float headingOutputDeadbandDeg = HEADING_OUTPUT_DEADBAND_DEG;
float headingMinWzRadS = HEADING_MIN_WZ_RAD_S;

uint32_t faultFlags = FAULT_NONE;
bool armed = false;
enum ControlMode : uint8_t { CONTROL_MANUAL = 0, CONTROL_AUTO = 1 };
enum FieldSide : uint8_t { FIELD_RED = 0, FIELD_BLUE = 1 };
ControlMode controlMode = CONTROL_MANUAL;
FieldSide selectedField = FIELD_RED;

int8_t selectedFieldLateralSign() {
  return selectedField == FIELD_RED ? RED_FIELD_LATERAL_SIGN
                                    : BLUE_FIELD_LATERAL_SIGN;
}

bool selectedFieldUsesRightStopGroup() {
  // Confirmed physical sensor selection: RED counts with the right-side
  // three-eye array. BLUE mirrors this and counts with the left-side array.
  return selectedField == FIELD_RED;
}

bool secondPickUsesRightStopGroup() {
  // Point B is reached by the opposite side of the chassis.  Do not keep
  // counting with the point-A array or RED will stop on line 3 at the right.
  return !selectedFieldUsesRightStopGroup();
}

bool softwareEStopLatched = false;
bool bnoInitialized = false;
bool bnoValid = false;
bool tofInitialized = false;
int16_t tofInitModeStatus = 32767, tofInitBudgetStatus = 32767, tofInitStartStatus = 32767;
bool tofValid = false;
// Accept valid VL53L3CX samples continuously so telemetry is available in
// MANUAL as well as AUTO. State transitions may clear the filter history,
// but must not gate every subsequent sample forever.
bool tofAcceptanceEnabled = true;
// Accept valid VL53L3CX samples continuously so telemetry is available in
// MANUAL as well as AUTO. State transitions may clear the filter history,
// but must not gate every subsequent sample forever.
bool tofAcceptanceEnabled = true;
// Accept valid VL53L3CX samples continuously so telemetry is available in
// MANUAL as well as AUTO. State transitions may clear the filter history,
// but must not gate every subsequent sample forever.
bool tofAcceptanceEnabled = true;
bool calibrationActive = false;
bool calibrationCenterOnly = false;
bool calibrationStopOnly = false;
bool espDone = false;
bool xAligned = false, yAligned = false;
bool supervisedAutoRun = false;
char lastEspCommand[16] = "NONE";
char lastEspResponse[16] = "NONE";
float robotVx = 0, robotVy = 0, robotWz = 0;
float positionErrorX = 0, positionErrorY = 0;
float lateralHoldXMm = 0.0f;
float lateralHoldTofMm = 0.0f;
bool lateralHoldTofCaptured = false;
float lateralHeadingCommandWz = 0.0f;
float stationHeadingCommandWz = 0.0f;
float lateralLineHoldCommandVx = 0.0f;
int8_t lateralLineHoldLastSign = 0;
uint32_t lateralLineHoldLastSeenMs = 0;
uint32_t lateralLineHoldStartedMs = 0;
float firstLateralStartedYmm = 0.0f;
bool firstLateralGuidanceArmed = false;
float currentYawDeg = 0, targetYawDeg = 0, yawReferenceDeg = 0;
float yawRateDegS = 0.0f;
float previousBnoYawDeg = 0.0f;
uint32_t previousBnoYawMs = 0;
float robotVx = 0, robotVy = 0, robotWz = 0;
float positionErrorX = 0, positionErrorY = 0;
float lateralHoldXMm = 0.0f;
float lateralHoldTofMm = 0.0f;
bool lateralHoldTofCaptured = false;
float lateralHeadingCommandWz = 0.0f;
float stationHeadingCommandWz = 0.0f;
float lateralLineHoldCommandVx = 0.0f;
int8_t lateralLineHoldLastSign = 0;
uint32_t lateralLineHoldLastSeenMs = 0;
uint32_t lateralLineHoldStartedMs = 0;
float firstLateralStartedYmm = 0.0f;
bool firstLateralGuidanceArmed = false;
float robotVx = 0, robotVy = 0, robotWz = 0;
float positionErrorX = 0, positionErrorY = 0;
float lateralHoldXMm = 0.0f;
float lateralHoldTofMm = 0.0f;
bool lateralHoldTofCaptured = false;
float lateralHeadingCommandWz = 0.0f;
float stationHeadingCommandWz = 0.0f;
float lateralLineHoldCommandVx = 0.0f;
int8_t lateralLineHoldLastSign = 0;
uint32_t lateralLineHoldLastSeenMs = 0;
uint32_t lateralLineHoldStartedMs = 0;
float firstLateralStartedYmm = 0.0f;
bool firstLateralGuidanceArmed = false;
float currentYawDeg = 0, targetYawDeg = 0, yawReferenceDeg = 0;
float yawRateDegS = 0.0f;
float currentRollDeg = 0.0f, currentPitchDeg = 0.0f;
bool bnoTiltInitialized = false;
float previousBnoYawDeg = 0.0f;
uint32_t previousBnoYawMs = 0;
enum BridgeSlopePhase : uint8_t {
  BRIDGE_PHASE_APPROACH = 0,
  BRIDGE_PHASE_ASCENDING,
  BRIDGE_PHASE_CREST_DESCENT
};
BridgeSlopePhase bridgeSlopePhase = BRIDGE_PHASE_APPROACH;
float bridgeLevelRollDeg = 0.0f, bridgeLevelPitchDeg = 0.0f;
float bridgeRelativeTiltDeg = 0.0f;
uint32_t bridgeInclineSinceMs = 0, bridgeLevelSinceMs = 0;
uint32_t bridgeEndMarkerSinceMs = 0;
uint32_t bridgeAscentDetectedMs = 0;
uint8_t bridgeSlopeAxis = 0; // 1=roll X, 2=pitch Y
float competitionHeadingDeg = 0.0f; // Captured once at START and held through A/B
float tofDistanceMm = 0;
float lateralSlipMmS = 0;
uint32_t lastBnoMs = 0, lastTofMs = 0;
uint32_t lastControlUs = 0, lastTelemetryMs = 0;
AutoState state = WAIT_START;

uint16_t centerCalMin[8];
uint16_t centerCalMax[8];
uint16_t stopCalMin[6];
uint16_t stopCalMax[6];

void applyFactoryPidConfig() {
void applyFactoryPidConfig() {
void applyFactoryPidConfig() {
  for(uint8_t i=0;i<4;i++){
    wheels[i].pid.kp=WHEEL_KP[i];wheels[i].pid.ki=WHEEL_KI[i];
    wheels[i].pid.kd=WHEEL_KD[i];wheels[i].kff=WHEEL_KFF[i];
    wheels[i].deadzone=WHEEL_DEADZONE_PWM[i];wheels[i].pid.reset();
  }
  headingPid.kp=HEADING_KP;headingPid.ki=HEADING_KI;headingPid.kd=HEADING_KD;
  linePid.kp=LINE_KP;linePid.ki=LINE_KI;linePid.kd=LINE_KD;
  maxWheelSpeedMmS=MAX_WHEEL_SPEED_MM_S;
  maxManualHeadingWzRadS=MAX_MANUAL_HEADING_WZ_RAD_S;
  maxAutoHeadLockWzRadS=MAX_AUTO_HEAD_LOCK_WZ_RAD_S;
  headingOutputDeadbandDeg=HEADING_OUTPUT_DEADBAND_DEG;
  headingMinWzRadS=HEADING_MIN_WZ_RAD_S;
  headingPid.reset();linePid.reset();
}
}
}

// ============================================================
// Utility and safety
// ============================================================

float wrap180(float angle) {
  while (angle > 180.0f) angle -= 360.0f;
  while (angle < -180.0f) angle += 360.0f;
  return angle;
}

float shortestAngleError(float target, float current) {
  return wrap180(target - current);
}

float readFloatLE(const uint8_t *p) {
  float value;
  memcpy(&value, p, sizeof(value));
  return value;
}

uint32_t readU32LE(const uint8_t *p) {
  uint32_t value;
  memcpy(&value, p, sizeof(value));
  return value;
}

void resetAllControllers();
void stopRobot();
void transitionTo(AutoState next);

void setFault(FaultCode fault, const char *reason) {
  if ((faultFlags & fault) == 0) {
    Serial.print("FAULT,");
    Serial.println(reason);
  }
  faultFlags |= fault;
  armed = false;
  stopRobot();
}

bool stopInputActive() {
  return softwareEStopLatched ||
         (PHYSICAL_START_STOP_ENABLED && digitalRead(STOP_PIN) == LOW);
}

void clearFaults() {
  if (stopInputActive()) return;
  faultFlags = FAULT_NONE;
  armed = false;
  resetAllControllers();
  Serial.println("ACK,RESET");
}

bool hardwareConfigurationValid() {
  return HARDWARE_CONFIG_VERIFIED && dimensionsValid() &&
         MECANUM_X_CONFIGURATION;
}

bool competitionConfigurationValid() {
  return hardwareConfigurationValid() && ESP32_UART_ENABLED &&
         (TOF_CONTROL_SIGN == -1 || TOF_CONTROL_SIGN == 1) &&
         (LEFT_STOP_CONTROL_SIGN == -1 || LEFT_STOP_CONTROL_SIGN == 1) &&
         (RIGHT_STOP_CONTROL_SIGN == -1 || RIGHT_STOP_CONTROL_SIGN == 1) &&
         CENTER_LINE_CALIBRATION_VERIFIED &&
         STOP_LINE_CALIBRATION_VERIFIED && STOP_SENSOR_ORDER_VERIFIED;
}

bool wheelTuneConfigurationValid() {
  return HARDWARE_CONFIG_VERIFIED&&WHEEL_DIAMETER_MM>0.0f&&
         ENCODER_COUNTS_PER_WHEEL_REV>0.0f;
}

bool configurationAllowsMotion() {
  return hardwareConfigurationValid() && faultFlags == FAULT_NONE &&
         !stopInputActive();
}

// ============================================================
// Motor output, encoder measurement and wheel PID
// ============================================================

void writeMotor(WheelControl &wheel, int pwm) {
  pwm = constrain(pwm * wheel.motorSign, -PWM_MAX, PWM_MAX);
  analogWrite(wheel.rpwm, pwm > 0 ? pwm : 0);
  analogWrite(wheel.lpwm, pwm < 0 ? -pwm : 0);
}

void resetWheelPid(WheelControl &wheel) {
  wheel.targetMmS = 0;
  wheel.pwm = 0;
  wheel.pid.reset();
  wheel.lastEncoderMotionMs = millis();
  writeMotor(wheel, 0);
}

void resetAllControllers() {
  for (WheelControl &wheel : wheels) resetWheelPid(wheel);
  headingPid.reset();
  fineHeadingPid.reset();
  for (WheelControl &wheel : wheels) resetWheelPid(wheel);
  headingPid.reset();
  fineHeadingPid.reset();
  for (WheelControl &wheel : wheels) resetWheelPid(wheel);
  headingPid.reset();
  fineHeadingPid.reset();
  linePid.reset();
  positionXPid.reset();
  positionYPid.reset();
  stopForwardPid.reset();
  stopYawPid.reset();
  tofDistancePid.reset();
  rightLinePid.reset();
  leftLinePid.reset();
  lateralHeadingCommandWz = 0.0f;
  stationHeadingCommandWz = 0.0f;
  lateralLineHoldCommandVx = 0.0f;
  robotVx = robotVy = robotWz = 0;
}
  leftLinePid.reset();
  lateralHeadingCommandWz = 0.0f;
  stationHeadingCommandWz = 0.0f;
  lateralLineHoldCommandVx = 0.0f;
  robotVx = robotVy = robotWz = 0;
}
  leftLinePid.reset();
  lateralHeadingCommandWz = 0.0f;
  stationHeadingCommandWz = 0.0f;
  lateralLineHoldCommandVx = 0.0f;
  robotVx = robotVy = robotWz = 0;
}

void stopRobot() {
  robotVx = robotVy = robotWz = 0;
  lateralHeadingCommandWz = 0.0f;
  stationHeadingCommandWz = 0.0f;
  lateralLineHoldCommandVx = 0.0f;
  positionErrorX = positionErrorY = 0;
  for (WheelControl &wheel : wheels) resetWheelPid(wheel);
}

void setRobotVelocity(float vx, float vy, float wz) {
  robotVx = vx;
  robotVy = vy;
  robotWz = wz;

  if (!armed || !configurationAllowsMotion()) {
    for (WheelControl &wheel : wheels) wheel.targetMmS = 0;
    return;
  }

  const float k = mecanumKmm();
  float targets[4] = {
    vx - vy - k * wz,
    vx + vy + k * wz,
    vx + vy - k * wz,
    vx - vy + k * wz
  };
void stopRobot() {
  robotVx = robotVy = robotWz = 0;
  lateralHeadingCommandWz = 0.0f;
  stationHeadingCommandWz = 0.0f;
  lateralLineHoldCommandVx = 0.0f;
  positionErrorX = positionErrorY = 0;
  for (WheelControl &wheel : wheels) resetWheelPid(wheel);
}

  float scale = 1.0f;
  for (float target : targets)
    scale = max(scale, fabsf(target) / maxWheelSpeedMmS);

  // Slew all wheel targets by one common factor. Independent clipping here
  // would alter the requested Mecanum direction during acceleration.
  float desired[WHEEL_COUNT] = {};
  float maxDelta = 0.0f;
  float currentMagnitude = 0.0f;
  float desiredMagnitude = 0.0f;
  for (uint8_t i = 0; i < WHEEL_COUNT; ++i) {
    desired[i] = targets[i] / scale;
    maxDelta = max(maxDelta, fabsf(desired[i] - wheels[i].targetMmS));
    currentMagnitude = max(currentMagnitude, fabsf(wheels[i].targetMmS));
    desiredMagnitude = max(desiredMagnitude, fabsf(desired[i]));
  }

  const bool accelerating = desiredMagnitude > currentMagnitude;
  const float rate = accelerating ? WHEEL_TARGET_ACCEL_MM_S2
                                  : WHEEL_TARGET_DECEL_MM_S2;
  const float allowedDelta = rate * (CONTROL_PERIOD_US * 1.0e-6f);
  const float slewScale = maxDelta > allowedDelta ? allowedDelta / maxDelta
                                                   : 1.0f;
  for (uint8_t i = 0; i < WHEEL_COUNT; ++i)
    wheels[i].targetMmS += (desired[i] - wheels[i].targetMmS) * slewScale;
}
void setRobotVelocity(float vx, float vy, float wz) {
  robotVx = vx;
  robotVy = vy;
  robotWz = wz;

  if (!armed || !configurationAllowsMotion()) {
    for (WheelControl &wheel : wheels) wheel.targetMmS = 0;
    return;
  }

  const float k = mecanumKmm();
  float targets[4] = {
    vx - vy - k * wz,
    vx + vy + k * wz,
    vx + vy - k * wz,
    vx - vy + k * wz
  };
void stopRobot() {
  robotVx = robotVy = robotWz = 0;
  lateralHeadingCommandWz = 0.0f;
  stationHeadingCommandWz = 0.0f;
  lateralLineHoldCommandVx = 0.0f;
  positionErrorX = positionErrorY = 0;
  for (WheelControl &wheel : wheels) resetWheelPid(wheel);
}
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
void loop() {
  updateUsbCommands();updateEspProtocol();updateOpticalFlow();updateBno085();updateTof();

  static bool previousStop=HIGH;
  const bool stopNow=PHYSICAL_START_STOP_ENABLED?digitalRead(STOP_PIN):HIGH;
  if(previousStop==HIGH&&stopNow==LOW){
    testMode=TEST_NONE;armed=false;stopRobot();
    if(state!=WAIT_START)transitionTo(WAIT_START);
    Serial.println("STOP_INPUT_ACTIVE");
  }
  previousStop=stopNow;
  static bool previousStart=HIGH;
  const bool startNow=PHYSICAL_START_STOP_ENABLED?digitalRead(START_PIN):HIGH;
  if(previousStart==HIGH&&startNow==LOW){
    if(stopNow==LOW)Serial.println("ERR,STOP_ACTIVE");
    else if(faultFlags!=FAULT_NONE)Serial.println("ERR,RESET_REQUIRED");
    else if(competitionConfigurationValid()){
      testMode=TEST_NONE;armed=true;resetAllControllers();resetPose();
      competitionHeadingDeg=currentYawDeg;targetYawDeg=competitionHeadingDeg;transitionTo(CAN_START);
    }else setFault(FAULT_CONFIG,"START_CONFIG_LOCKED");
  }
  previousStart=startNow;

  const uint32_t nowUs=micros();
  if(nowUs-lastControlUs>=CONTROL_PERIOD_US){
    const float dt=(nowUs-lastControlUs)*1.0e-6f;lastControlUs=nowUs;
    updateLineArrays();updateEncoderMeasurements(dt);updateOdometry(dt);
    if(armed&&testMode!=TEST_WHEEL_TUNE&&testMode!=TEST_MANUAL_DRIVE&&!bnoValid)
      setFault(FAULT_IMU_TIMEOUT,"BNO085_TIMEOUT");
    if(supervisedAutoRun&&millis()-lastTunerHeartbeatMs>POSITION_LINK_WATCHDOG_MS){
      supervisedAutoRun=false;armed=false;moveCommand.active=false;stopRobot();
      transitionTo(WAIT_START);Serial.println("ERR,AUTO_TEST_HEARTBEAT_TIMEOUT");
    }
    updateTestMode(dt);
    if(testMode==TEST_NONE)updateCompetition(dt);
    updateWheelSpeedPid(dt);
  }
  printTelemetry();
}

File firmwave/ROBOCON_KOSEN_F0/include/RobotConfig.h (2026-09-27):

#pragma once

#include <Arduino.h>

namespace RobotConfig {

// Set true only after every TODO value and direction has been measured.
// Motor/encoder wiring and encoder CPR verified for safe one-wheel PID tuning.
// Autonomous motion remains locked until dimensionsValid() is also true.
constexpr bool HARDWARE_CONFIG_VERIFIED = true; // VI: Cho phép vận hành khi cấu hình phần cứng đã được xác minh.
// Keep the long DBG record off on the 57600-baud air link. The compact TEL,
// WHEEL and selected raw-line records remain enabled for the tuner at 10 Hz.
constexpr bool DEBUG_TELEMETRY = false; // VI: Bật hoặc tắt bản tin telemetry gỡ lỗi dài.

// ---------------- Mechanical configuration ----------------
constexpr float WHEEL_DIAMETER_MM = 100.0f; // VI: Đường kính bánh xe, đơn vị mm.
constexpr float ROBOT_LENGTH_MM = 260.0f; // VI: Khoảng cách tâm bánh trước–sau, đơn vị mm.
constexpr float ROBOT_WIDTH_MM = 350.0f; // VI: Khoảng cách tâm bánh trái–phải, đơn vị mm.
constexpr float ENCODER_COUNTS_PER_WHEEL_REV = 300.0f; // VI: Số xung encoder X4 trên một vòng bánh sau hộp số.
constexpr float DISTANCE_CALIBRATION = 1.0f; // VI: Hệ số hiệu chỉnh quãng đường encoder.
// Lateral route mirror selected at run time by FIELD,RED / FIELD,BLUE.
// Verified on the physical chassis: +Vy moves toward the red-field left
// route, while -Vy moves toward the mirrored blue-field right route.
constexpr int8_t RED_FIELD_LATERAL_SIGN = 1; // VI: Dấu chiều chạy ngang của MAP đỏ.
constexpr int8_t BLUE_FIELD_LATERAL_SIGN = -1; // VI: Dấu chiều chạy ngang của MAP xanh.

constexpr int8_t MOTOR_SIGN_FL = 1; // VI: Chiều điều khiển động cơ bánh trước trái FL.
constexpr int8_t MOTOR_SIGN_FR = -1; // VI: Chiều điều khiển động cơ bánh trước phải FR.
// Rear hardware channels were identified in the opposite physical positions:
// old RR is physical RL, and old RL is physical RR.
constexpr int8_t MOTOR_SIGN_RL = 1; // VI: Chiều điều khiển động cơ bánh sau trái BL/RL.
constexpr int8_t MOTOR_SIGN_RR = -1; // VI: Chiều điều khiển động cơ bánh sau phải BR/RR.
// Verified from live 30 RPM tune telemetry: positive motor command counted down.
constexpr int8_t ENCODER_SIGN_FL = -1; // VI: Chiều đếm encoder bánh trước trái FL.
// Verified from live 10 RPM tune telemetry: positive motor command counted down.
constexpr int8_t ENCODER_SIGN_FR = 1; // VI: Chiều đếm encoder bánh trước phải FR.
constexpr int8_t ENCODER_SIGN_RL = 1; // VI: Chiều đếm encoder bánh sau trái BL/RL.
constexpr int8_t ENCODER_SIGN_RR = -1; // VI: Chiều đếm encoder bánh sau phải BR/RR.

// X-configuration wheel equations:
// FL=vx-vy-k*wz, FR=vx+vy+k*wz, RL=vx+vy-k*wz, RR=vx-vy+k*wz.
constexpr bool MECANUM_X_CONFIGURATION = true; // VI: Chọn cấu hình con lăn Mecanum kiểu X.

// ---------------- Motor and encoder pins ----------------
constexpr uint8_t FL_RPWM = 36, FL_LPWM = 37; // VI: Chân PWM hai chiều bánh FL: RPWM và LPWM.
constexpr uint8_t FR_RPWM = 22, FR_LPWM = 23; // VI: Chân PWM hai chiều bánh FR: RPWM và LPWM.
constexpr uint8_t RL_RPWM = 18, RL_LPWM = 19; // VI: Chân PWM hai chiều bánh BL/RL: RPWM và LPWM.
constexpr uint8_t RR_RPWM = 14, RR_LPWM = 15; // VI: Chân PWM hai chiều bánh BR/RR: RPWM và LPWM.

constexpr uint8_t FL_ENC_A = 0, FL_ENC_B = 1; // VI: Chân encoder A/B của bánh FL.
constexpr uint8_t FR_ENC_A = 6, FR_ENC_B = 7; // VI: Chân encoder A/B của bánh FR.
constexpr uint8_t RL_ENC_A = 2, RL_ENC_B = 3; // VI: Chân encoder A/B của bánh BL/RL.
constexpr uint8_t RR_ENC_A = 4, RR_ENC_B = 5; // VI: Chân encoder A/B của bánh BR/RR.

constexpr int PWM_FREQUENCY_HZ = 20000; // VI: Tần số PWM FREQUENCY, đơn vị Hz.
constexpr int PWM_MAX = 255; // VI: Giá trị PWM lớn nhất.
constexpr float MAX_WHEEL_SPEED_MM_S = 1300.0f; // VI: Tốc độ tối đa bánh xe tốc độ, đơn vị mm/s.
constexpr float WHEEL_SPEED_FILTER_ALPHA = 0.35f; // VI: Hệ số lọc tốc độ bánh; lớn hơn bám nhanh nhưng nhiễu hơn.
constexpr uint32_t CONTROL_PERIOD_US = 10000; // VI: Thời gian điều khiển PERIOD, đơn vị µs.
// Synchronized wheel-target ramp. It limits the initial torque step without
// changing the Mecanum wheel-speed ratios. Safety stops still bypass this ramp.
constexpr float WHEEL_TARGET_ACCEL_MM_S2 = 1400.0f; // VI: Gia tốc bánh xe mục tiêu tăng tốc, đơn vị mm/s².
constexpr float WHEEL_TARGET_DECEL_MM_S2 = 2400.0f; // VI: Gia tốc bánh xe mục tiêu giảm tốc, đơn vị mm/s².

// All controller gains live in this file. Telemetry tuning changes RAM only;
// reset/reboot restores these compiled values. EEPROM is not used for PID.
// Direct USB tuning with all four wheels lifted, both directions, 40/80/120 RPM
// on 2026-09-05. Recheck under load before competition use.
// Array order everywhere in firmware: FL, FR, BL/RL, BR/RR.
constexpr float WHEEL_KP[4] = { // VI: Hệ số P bốn bánh, thứ tự FL, FR, BL/RL, BR/RR.
    0.25f, // FL - bánh trước trái
    0.25f, // FR - bánh trước phải
    0.25f, // BL/RL - bánh sau trái
    0.25f  // BR/RR - bánh sau phải
};
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

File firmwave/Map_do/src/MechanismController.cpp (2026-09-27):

#include "MechanismController.h"

#include <limits.h>
#include <math.h>
#include <stdio.h>
#include <string.h>

#include "HardwareConfig.h"

MechanismController::MechanismController(AccelStepper &motorA,
                                         AccelStepper &motorB,
                                         ValveController &valves)
    : motorA_(motorA), motorB_(motorB), valves_(valves) {}

void MechanismController::setOperationName(const char *name) {
  strncpy(operationName_, name ? name : "NONE", sizeof(operationName_) - 1);
  operationName_[sizeof(operationName_) - 1] = '\0';
}

void MechanismController::begin(MechanismConfig &config) {
  config_ = &config;
  motorA_.setMinPulseWidth(HardwareConfig::STEPPER_MIN_PULSE_US);
  motorB_.setMinPulseWidth(HardwareConfig::STEPPER_MIN_PULSE_US);
  pinMode(HardwareConfig::HOME_SWITCH_A_PIN, INPUT_PULLUP);
  pinMode(HardwareConfig::HOME_SWITCH_B_PIN, INPUT_PULLUP);
  pinMode(HardwareConfig::RGB_GREEN_PIN, OUTPUT);
  pinMode(HardwareConfig::RGB_RED_PIN, OUTPUT);
  pinMode(HardwareConfig::RGB_BLUE_PIN, OUTPUT);
  competitionField_ = MechanismField::Red;
  updateFieldLed();
  // main.cpp performs an early safe-off before slower startup work. Keep this
  // retry for tests and for recovery when that first I2C probe did not succeed.
  if (!valves_.healthy()) valves_.begin();
  if (!valves_.healthy()) {
    setFault(MechanismFault::Pcf8574Unavailable, "PCF8574_NOT_FOUND");
    return;
  }
  emergencyStop("BOOT_SAFE");
  clearFault();
  startHome();
}

void MechanismController::updateFieldLed() {
  const uint8_t on = HardwareConfig::RGB_LED_ACTIVE_HIGH ? HIGH : LOW;
  const uint8_t off = HardwareConfig::RGB_LED_ACTIVE_HIGH ? LOW : HIGH;
  digitalWrite(HardwareConfig::RGB_GREEN_PIN, off);
  digitalWrite(HardwareConfig::RGB_RED_PIN,
               competitionField_ == MechanismField::Red ? on : off);
  digitalWrite(HardwareConfig::RGB_BLUE_PIN,
               competitionField_ == MechanismField::Blue ? on : off);
}

bool MechanismController::setCompetitionField(MechanismField field) {
  // FIELD only selects routing for a future POINT_A/POINT_B action. It is safe
  // to accept it while HOME is running, which lets Teensy synchronize at boot.
  // Never change it halfway through an active competition action.
  if (state_ == State::Competition) return false;
  competitionField_ = field;
  updateFieldLed();
  return true;
}

const StepperProfile &MechanismController::profile() const {
  return config_->profiles[static_cast<uint8_t>(activeProfile_)];
}

float MechanismController::stepsPerMmA(const StepperProfile &p) const {
  return p.stepsPerRevA * p.correctionA / p.screwPitchAmm;
}

float MechanismController::stepsPerMmB(const StepperProfile &p) const {
  return p.stepsPerRevB * p.correctionB / p.screwPitchBmm;
}

float MechanismController::positionAmm() const {
  if (!config_) return 0.0f;
  const float scale = stepsPerMmA(profile());
  return scale > 0.0f ? motorA_.currentPosition() / scale : 0.0f;
}

float MechanismController::positionBmm() const {
  if (!config_) return 0.0f;
  const float scale = stepsPerMmB(profile());
  return scale > 0.0f ? motorB_.currentPosition() / scale : 0.0f;
}

bool MechanismController::homeSwitchAActive() const {
  return digitalRead(HardwareConfig::HOME_SWITCH_A_PIN) ==
         HardwareConfig::HOME_SWITCH_ACTIVE_LEVEL;
}

bool MechanismController::homeSwitchBActive() const {
  return digitalRead(HardwareConfig::HOME_SWITCH_B_PIN) ==
         HardwareConfig::HOME_SWITCH_ACTIVE_LEVEL;
}

void MechanismController::selectProfileScale(ProfileId id) {
  const float positionA = positionAmm();
  const float positionB = positionBmm();
  activeProfile_ = id;
  const StepperProfile &next = profile();
  motorA_.setCurrentPosition(lroundf(positionA * stepsPerMmA(next)));
  motorB_.setCurrentPosition(lroundf(positionB * stepsPerMmB(next)));
}

bool MechanismController::targetsWithinLimits(float targetAmm,
                                               float targetBmm) const {
  return config_ && isfinite(targetAmm) && isfinite(targetBmm) &&
         targetAmm >= config_->minimumPositionAmm &&
         targetAmm <= config_->maximumPositionAmm &&
         targetBmm >= config_->minimumPositionBmm &&
         targetBmm <= config_->maximumPositionBmm;
}

bool MechanismController::issueAbsoluteMotion(
    float targetAmm, float targetBmm, float maxSpeedA, float maxSpeedB,
    float accelerationA, float accelerationB) {
  if (!targetsWithinLimits(targetAmm, targetBmm)) {
    setFault(MechanismFault::PositionLimit, "POSITION_LIMIT");
    return false;
  }

  const StepperProfile &scaleProfile = profile();
  const float scaleA = stepsPerMmA(scaleProfile);
  const float scaleB = stepsPerMmB(scaleProfile);
  const float currentA = positionAmm();
  const float currentB = positionBmm();
  const float travelA = fabsf(targetAmm - currentA) * scaleA;
  const float travelB = fabsf(targetBmm - currentB) * scaleB;
  float speedA = maxSpeedA;
  float speedB = maxSpeedB;
  const float timeA = speedA > 0.0f ? travelA / speedA : 0.0f;
  const float timeB = speedB > 0.0f ? travelB / speedB : 0.0f;
  const float longest = max(timeA, timeB);
  if (longest > 0.0f) {
    if (travelA > 0.0f) speedA = min(speedA, travelA / longest);
    if (travelB > 0.0f) speedB = min(speedB, travelB / longest);
  }

  motorA_.setMaxSpeed(max(10.0f, speedA));
  motorB_.setMaxSpeed(max(10.0f, speedB));
  motorA_.setAcceleration(accelerationA);
  motorB_.setAcceleration(accelerationB);
  motorA_.moveTo(lroundf(targetAmm * scaleA));
  motorB_.moveTo(lroundf(targetBmm * scaleB));
  motionIssued_ = true;
  return true;
}

bool MechanismController::issueProfileMotion(const StepperProfile &p) {
  const float currentA = positionAmm();
  const float currentB = positionBmm();
  const float targetA = p.absoluteMode
      ? p.distanceAmm * p.directionA
      : currentA + p.distanceAmm * p.directionA;
  const float targetB = p.absoluteMode
      ? p.distanceBmm * p.directionB
      : currentB + p.distanceBmm * p.directionB;
  return issueAbsoluteMotion(targetA, targetB, p.maxSpeedA, p.maxSpeedB,
                             p.accelerationA, p.accelerationB);
}
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

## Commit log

2026-07-18 Thêm chương trình C++ đầu tiên
2026-07-18 Đổi tên
2026-07-18 Thêm phần cưng PCB và Schermatic
    [0402_CA_CB_CC_CD.SLDPRT, ESP32-S3-WROOM-1.SLDASM, ESP32-S3-WROOM-1.STEP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]
2026-07-18 docs: chuẩn hóa dự án và quy trình làm việc nhóm
2026-07-18 Update code thang 6 để tham khảo cho code mơi
2026-07-20 FIRMWAVE TUNE PID
2026-07-22 update 22/7/2026
    [DEMO_T9_V4.step, PCB1.PcbDoc, PCB1.step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]
2026-07-23 update 23/7/2026
    [DG142R-2-5.08.SLDPRT, DG142R-2-5.08.STEP, DG142R-3-5.08.SLDPRT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]
2026-08-15 UPDATE 15/8
    [3mat.SchDoc, 3matline.PcbDoc, BOADR_CS.PrjPcb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]
2026-08-18 UPDATE 18/8
    [11.step, 22.step, Part3.SLDPRT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]
2026-08-21 update 21/8
    [MÔ HÌNH.step, TẤM ĐẾ PHAY 2.step, TẤM ĐẾ PHAY.step]
2026-09-01 update 2/9
    [3matline.step]
2026-09-03 Add Teensy Mecanum competition firmware
2026-09-10 up
    uodatr 11/9/26
    [ESP32-S3-N16R8.PcbLib, ESP32_DR.PrjPcb, MACHKICHVAN.PcbDoc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]
2026-09-27 up
    up
    [1789266678601_53441593253659687_6409918754985055598_sift.csv, 1789266678601_53441593253659687_6409918754985055598_trajectory.csv, 1789266678602_534415932536596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]
